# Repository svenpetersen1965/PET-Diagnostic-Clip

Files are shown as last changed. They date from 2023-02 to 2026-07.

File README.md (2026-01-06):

# PET-Diagnostic-Clip
This is a modern remake of the two Commodore Diagnostic Clips

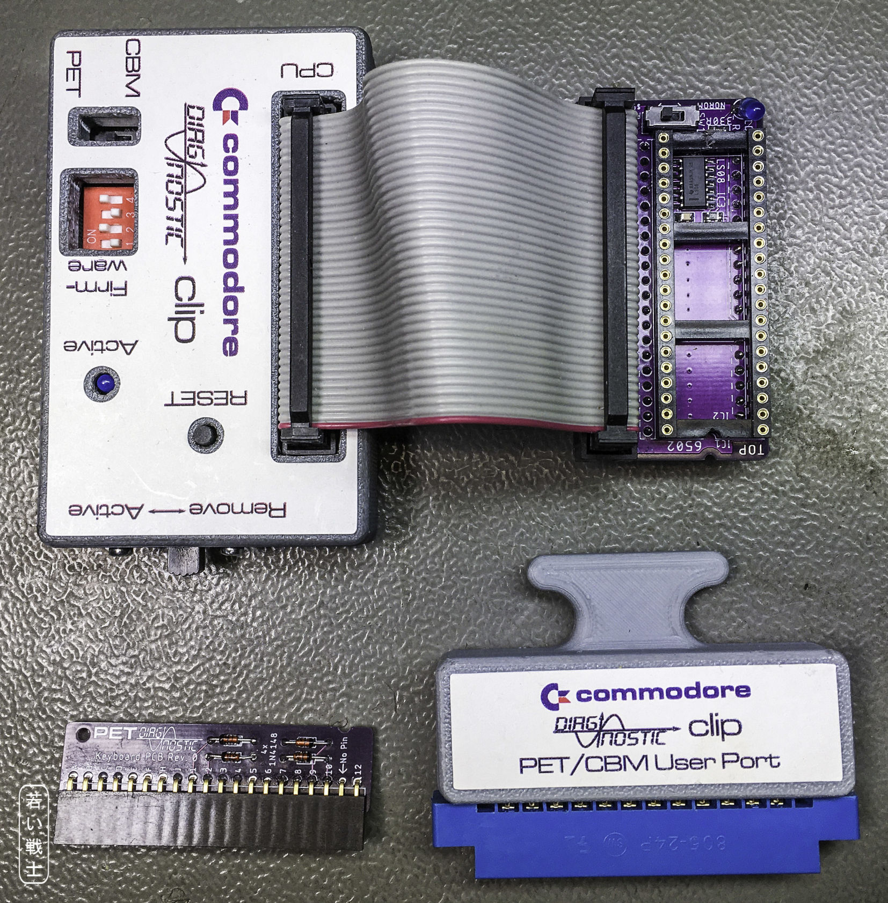
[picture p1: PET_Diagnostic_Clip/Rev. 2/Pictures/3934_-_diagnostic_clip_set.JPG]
Diagnostic Clip (complete)
<br>Complete Diagnostic Clip Set

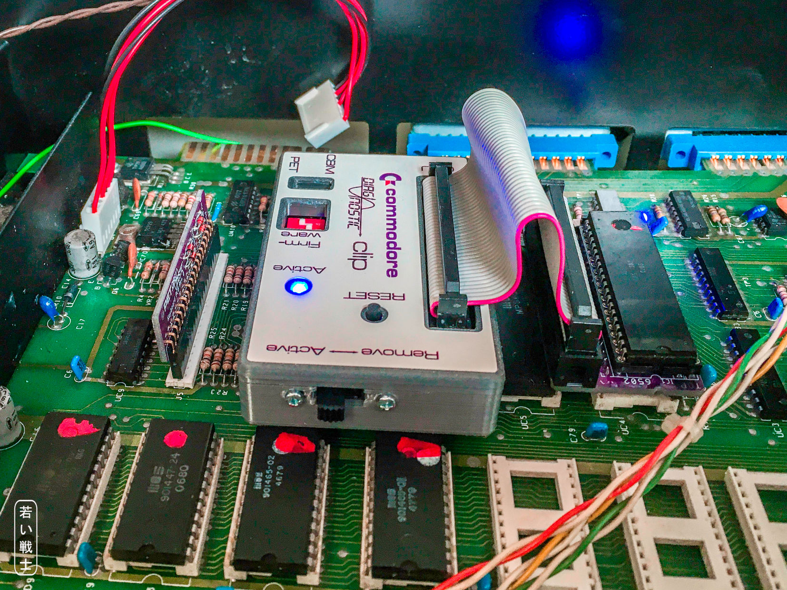
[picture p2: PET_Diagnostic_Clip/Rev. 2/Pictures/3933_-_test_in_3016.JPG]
Diagnostic Clip in CBM3016
<br>Diagnostic Clip installed in a CBM3016 (non CRTC machine)

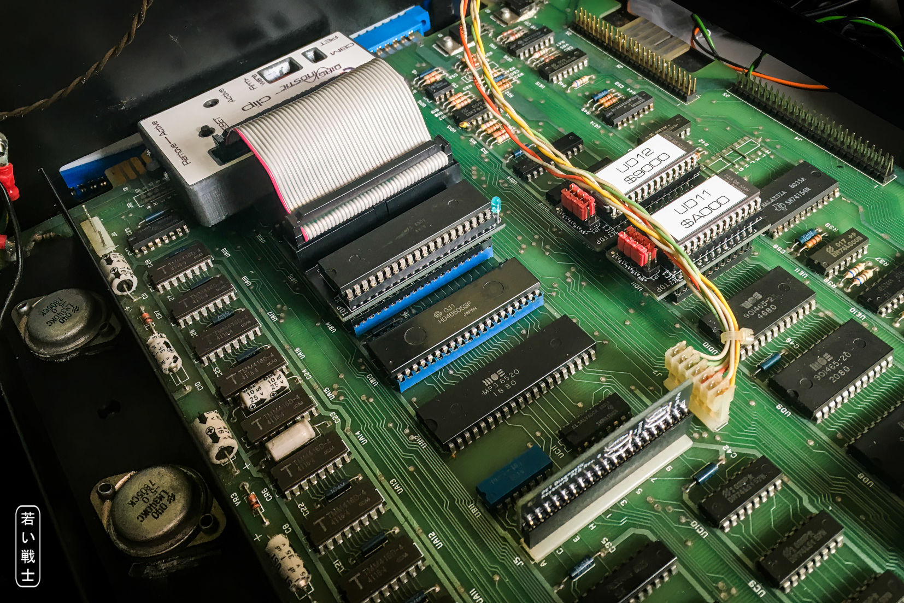
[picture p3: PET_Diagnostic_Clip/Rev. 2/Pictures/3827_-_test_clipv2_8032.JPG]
Diagnostic Clip in CBM8032
<br>Diagnostic Clip installed in a CBM8032 (CRTC machine)

# PET Diagnostic Software (40 column, non CRTC):<br>
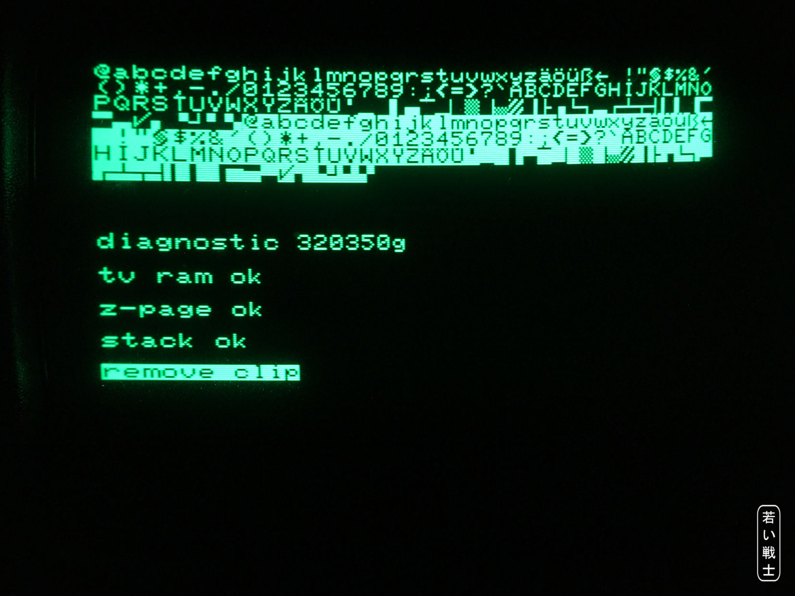
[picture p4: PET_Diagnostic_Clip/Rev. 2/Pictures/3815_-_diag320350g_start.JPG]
40col non CRTC Start
<br>Opening Screen

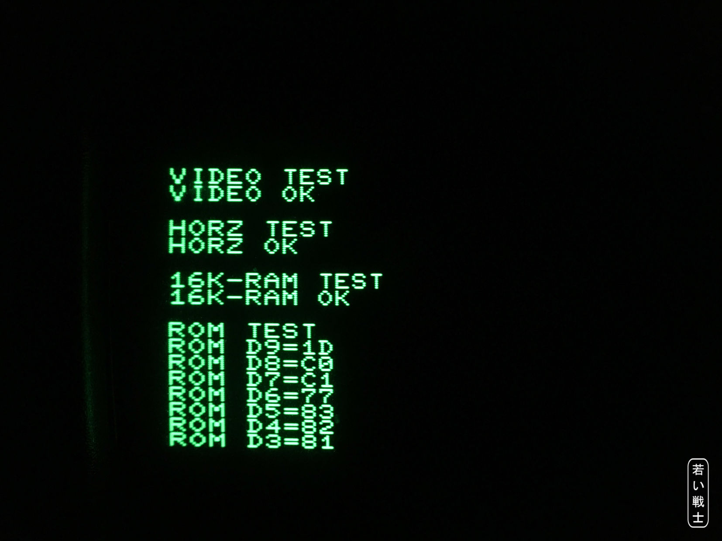
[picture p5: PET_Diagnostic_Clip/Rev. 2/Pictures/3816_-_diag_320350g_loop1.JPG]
<br>Actual tests

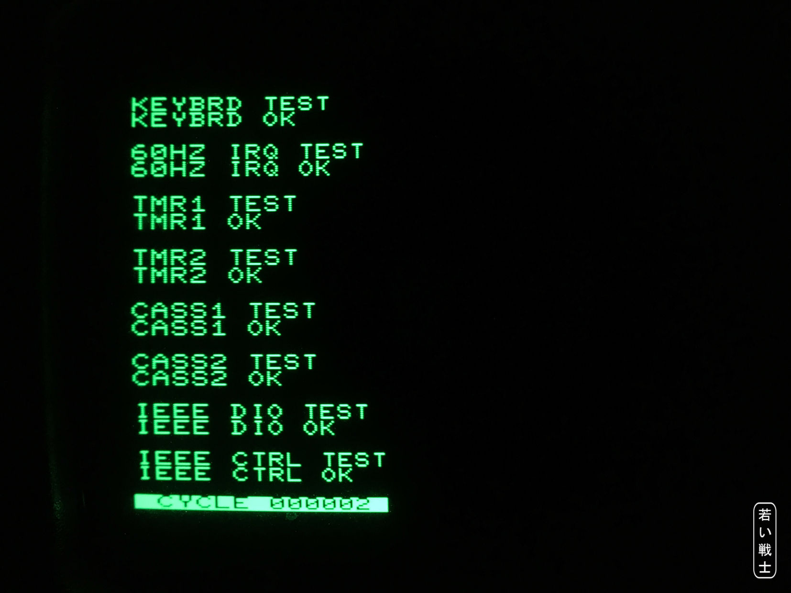
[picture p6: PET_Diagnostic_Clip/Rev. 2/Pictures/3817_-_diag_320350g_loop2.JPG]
<br>Actual tests (continued)

# PET Diagnostic Software (80 column, CRTC):<br>
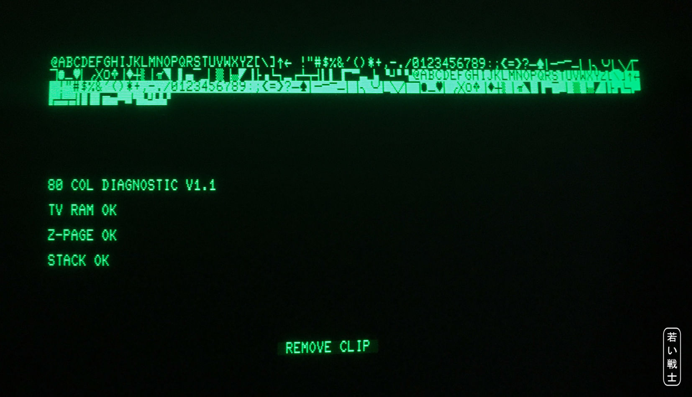
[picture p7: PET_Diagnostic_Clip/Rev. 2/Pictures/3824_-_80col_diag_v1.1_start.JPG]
80col CRTC Start
<br>Opening Screen

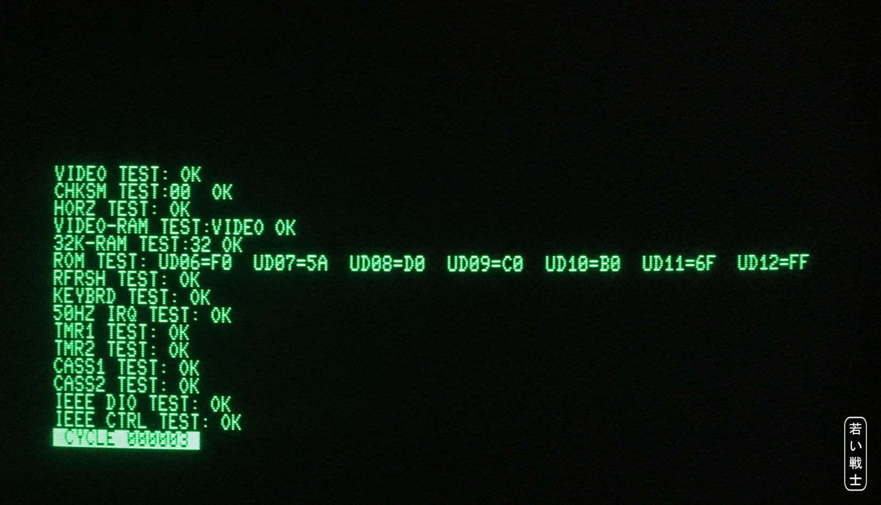
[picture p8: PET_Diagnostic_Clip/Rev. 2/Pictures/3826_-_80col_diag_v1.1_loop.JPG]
80col CRTC Tests
<br>Actual tests

# Binaries for the EPROM
The name of the combined file is "80colCRCTv1.1_40colCRCTv2.0_diag3202350g_diag320350g.bin". It contains:
<table>
  <thead>
    <tr>
      <th>EPROM Offset</th><th>Software</th><th>DIP Switch</th>
    </tr>
  </thead>
  <tbody>
    <tr>
      <td>$0000</td><td>80_col_diagnostic_v1.1.bin</td><td>A[15..12]: 0000 =  ON  ON  ON  ON</td>
    </tr>
    <tr>
      <td>$1000</td><td>40_col_diagnostic_v2.0.bin</td><td>A[15..12]: 0001 =  ON  ON  ON  OFF</td>
    </tr>
    <tr>
      <td>$2000</td><td>901447-30_diagnostic_320350g_$9000.bin</td><td>A[15..12]: 0010 =  ON  ON  OFF ON</td>
    </tr>
    <tr>
      <td>$3000</td><td>901447-30_diagnostic_320350g_$9000.bin</td><td>A[15..12]: 0011 =  ON  ON  OFF OFF</td>
    </tr>
 </tbody>
</table>    
    
The Diagnostic 320350g is double. The reason is, the computer would crash if an empty slot is selected. So all slots, that can be selected with the two low switches of the dip switch are occupied.

In a subdirectory, there are some "PETtester" Softwares. These are not a complete test. The (vice) screen shots are included. It could also be installed on the clip, if desired. 
# CBM8296
This part of the project is not tested yet. <b>The release is preliminary</b>.

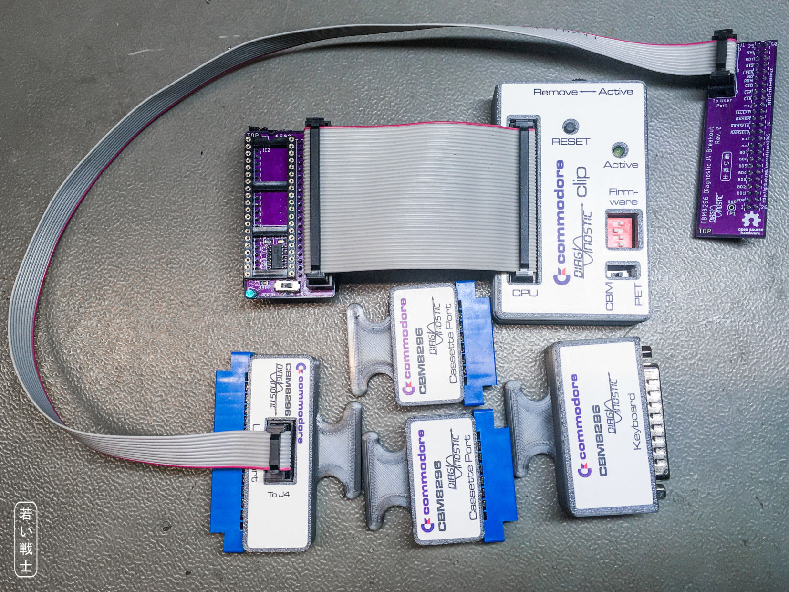
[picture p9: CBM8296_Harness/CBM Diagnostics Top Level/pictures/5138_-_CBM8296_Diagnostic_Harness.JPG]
CBM8296 Diagnostic Harness (complete)
<br>CBM8296 Diagnostic Harness (complete)

The diagnostic software for the CBM8296 is contained in the respective folder. There is also a merged binary file ("80colCRCTv1.1_40colCRCTv2.0_diag3202350g_diag320350g_8296.bin") which contains the 324806-01.bin at offset address $4000 (A[15..12]: 0100 =  ON  OFF  ON ON).

<b>State of testing:</b><br>
14.06.2023:<br>
* all dongles work with the original (Commodore) clip
* the cassette dongle case reqires modification
21.06.2023:<br>
The CBM8296 can actively switch the /NOROM signal (register @$FFF0). It does so to access the RAM underneath the ROMs. As a result, the diagnostic ROM in the clip is getting visible, which interferes with the test of the upper RAM banks.

A solution is switching off the /NOROM signal in the clip by using the 2nd stage of the external switch. The /NOROM trace at J1, pin 9 has to be cut open and connected to the middle pin of the said switch, the right pin ("active" position) has to be connected to the clip's internal /NOROM signal, e.g. at SW4.  

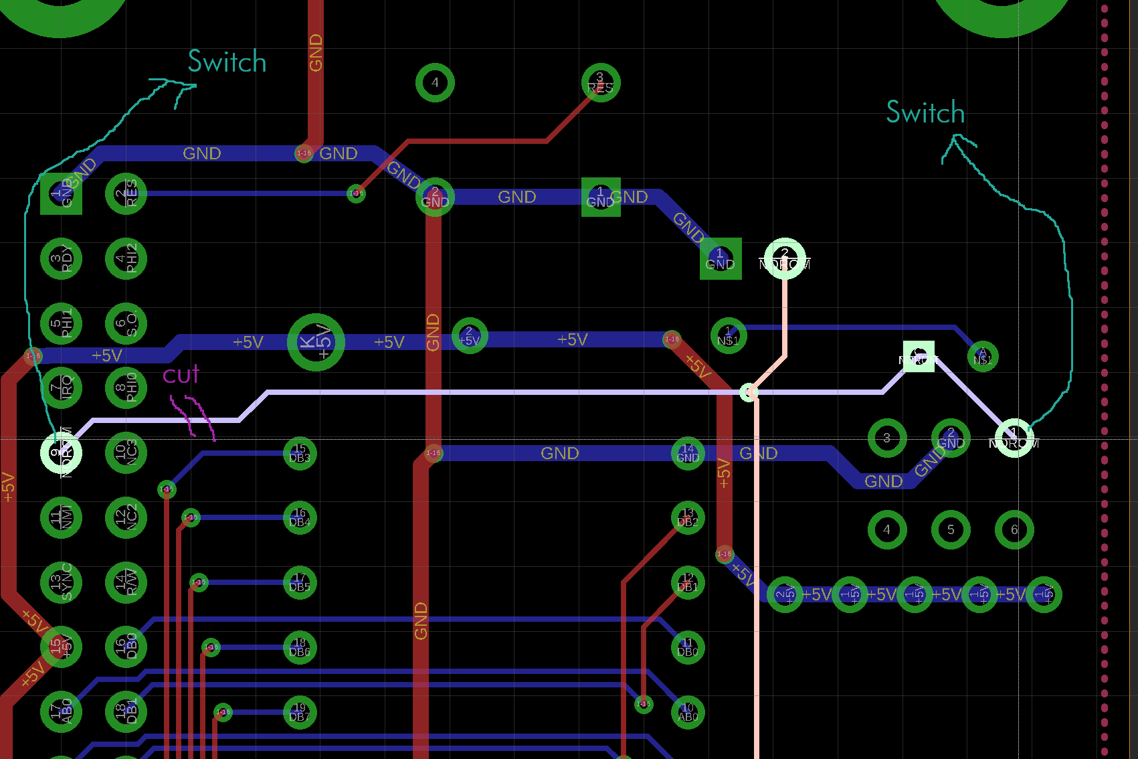
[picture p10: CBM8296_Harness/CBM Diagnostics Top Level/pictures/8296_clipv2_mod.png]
Diagnostic Clip (complete)
<br>/NOROM modification of Clip Rev. 2

The clip Rev. 3 incorporates this modificaltion. Since I do not own a CBM8296, I cannot test the new clip with this computer. 

# Additional Information
I have held a presentation about this topic for Commodore Users Europe on Sept. 23rd, 2023. The pdf of the power point presentation can be found here: <a href="https://github.com/svenpetersen1965/PET-Diagnostic-Clip/commit/a3cc22ed0ae75f65ffd660c29feb877c46cf6521">here</a>

Also check my website for <a href="http://tech.guitarsite.de/petcbm_diag_clip.html">additional information</a>.

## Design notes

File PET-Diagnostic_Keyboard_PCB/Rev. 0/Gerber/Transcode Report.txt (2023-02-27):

   ---- Transcoding 'X:\Projekte\_Eigene\PET_CBM_Projects\PET_Diagostics\PET-Diagnostic_Keyboard_PCB\Rev. 0\Gerber\gerber_PET_Diag_KB.out' ----   Sat Feb 18 21:43:34 2023

D11   --> D100
D12   --> D101
D13   --> D102
-----------------------------------------------------------------

   ---- Transcoding 'X:\Projekte\_Eigene\PET_CBM_Projects\PET_Diagostics\PET-Diagnostic_Keyboard_PCB\Rev. 0\Gerber\gerber_PET_Diag_KB.plc' ----   Sat Feb 18 21:43:34 2023

D11   --> D103
D12   --> D104
D13   --> D105
D14   --> D106
D15   --> D107
D16   --> D108
D17   --> D109
D18   --> D110
D19   --> D111
D20   --> D112
-----------------------------------------------------------------

   ---- Transcoding 'X:\Projekte\_Eigene\PET_CBM_Projects\PET_Diagostics\PET-Diagnostic_Keyboard_PCB\Rev. 0\Gerber\gerber_PET_Diag_KB.pls' ----   Sat Feb 18 21:43:34 2023

D11   --> D183
D12   --> D184
D13   --> D185
D14   --> D186
D15   --> D187
D16   --> D188
D17   --> D189
D18   --> D190
D19   --> D191
D20   --> D192
D21   --> D193
D22   --> D194
D23   --> D195
D24   --> D196
D25   --> D197
D26   --> D198
D27   --> D199
D28   --> D200
D29   --> D201
D30   --> D202
D31   --> D203
D32   --> D204
D33   --> D205
D34   --> D206
D35   --> D207
D36   --> D208
D37   --> D209
D38   --> D210
D39   --> D211
D40   --> D212
D41   --> D213
D42   --> D214
D43   --> D215
D44   --> D216
D45   --> D217
D46   --> D218
D47   --> D219
D48   --> D220
D49   --> D221
D50   --> D222
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
-----------------------------------------------------------------

   ---- Transcoding 'X:\Projekte\_Eigene\PET_CBM_Projects\PET_Diagostics\PET-Diagnostic_Keyboard_PCB\Rev. 0\Gerber\gerber_PET_Diag_KB.stc' ----   Sat Feb 18 21:43:34 2023

D11   --> D274
D12   --> D275
D13   --> D276
D14   --> D277
D16   --> D278
D17   --> D279
D18   --> D280
-----------------------------------------------------------------

   ---- Transcoding 'X:\Projekte\_Eigene\PET_CBM_Projects\PET_Diagostics\PET-Diagnostic_Keyboard_PCB\Rev. 0\Gerber\gerber_PET_Diag_KB.sts' ----   Sat Feb 18 21:43:34 2023

D11   --> D281
D12   --> D282
D13   --> D283
D14   --> D284
D16   --> D285
D17   --> D286
D18   --> D287
-----------------------------------------------------------------

   ---- Transcoding 'X:\Projekte\_Eigene\PET_CBM_Projects\PET_Diagostics\PET-Diagnostic_Keyboard_PCB\Rev. 0\Gerber\gerber_PET_Diag_KB.top' ----   Sat Feb 18 21:43:34 2023

D11   --> D288
D12   --> D289
D13   --> D290
D14   --> D291
D15   --> D292
D16   --> D293
D17   --> D294
D18   --> D295
D19   --> D296
-----------------------------------------------------------------

   ---- Transcoding 'X:\Projekte\_Eigene\PET_CBM_Projects\PET_Diagostics\PET-Diagnostic_Keyboard_PCB\Rev. 0\Gerber\excellon_PET_Diag_KB.ndk' ----   Sat Feb 18 21:43:44 2023

T1   --> T4
-----------------------------------------------------------------

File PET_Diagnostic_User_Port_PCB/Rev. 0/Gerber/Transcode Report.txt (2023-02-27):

   ---- Transcoding 'X:\Projekte\_Eigene\PET_CBM_Projects\PET_Diagostics\PET_Diagnostic_User_Port_PCB\Rev. 0\Gerber\gerber_PET_Diag_UP.out' ----   Wed Jan 04 18:26:30 2023

D12   --> D100
D13   --> D101
-----------------------------------------------------------------

   ---- Transcoding 'X:\Projekte\_Eigene\PET_CBM_Projects\PET_Diagostics\PET_Diagnostic_User_Port_PCB\Rev. 0\Gerber\gerber_PET_Diag_UP.plc' ----   Wed Jan 04 18:26:30 2023

D11   --> D252
D12   --> D253
D13   --> D254
D14   --> D255
D15   --> D256
D16   --> D257
D17   --> D258
D18   --> D259
D19   --> D260
D20   --> D261
D100  --> D262
D101  --> D263
-----------------------------------------------------------------

   ---- Transcoding 'X:\Projekte\_Eigene\PET_CBM_Projects\PET_Diagostics\PET_Diagnostic_User_Port_PCB\Rev. 0\Gerber\gerber_PET_Diag_UP.stc' ----   Wed Jan 04 18:26:30 2023

D12   --> D264
D13   --> D265
D15   --> D266
D16   --> D267
-----------------------------------------------------------------

   ---- Transcoding 'X:\Projekte\_Eigene\PET_CBM_Projects\PET_Diagostics\PET_Diagnostic_User_Port_PCB\Rev. 0\Gerber\gerber_PET_Diag_UP.sts' ----   Wed Jan 04 18:26:30 2023

D12   --> D268
D13   --> D269
D15   --> D270
D16   --> D271
-----------------------------------------------------------------

   ---- Transcoding 'X:\Projekte\_Eigene\PET_CBM_Projects\PET_Diagostics\PET_Diagnostic_User_Port_PCB\Rev. 0\Gerber\gerber_PET_Diag_UP.top' ----   Wed Jan 04 18:26:30 2023

D18   --> D272
D19   --> D273
-----------------------------------------------------------------

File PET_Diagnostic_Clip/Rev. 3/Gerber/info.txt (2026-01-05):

      
       Board: PET_Diag_Clip
       Rev.:  3
  
       Files:
       ======
  
       All Gerber files are generated in extended gerber format (RS274X)
       *.TOP        : Film top copper
       *.BOT        :  -"- bottom copper
       *.STC        :  -"- top soldermask 
       *.STS        :  -"- bottom soldermask
       *.PLC        :  -"- silk screen top
       *.PLS        :  -"- silk screen bottom
       *.DK         : Drills plated Through (Excellon)
       *.NDK        : Drills not plated Through (Excellon)
       *.OUT        : Board outline

       Board Size:
       ===========
       Length     :   77.0 mm
       Width      :   47.0 mm
       Thickness  :   1.6 mm
       Material   :   FR 4
       Copper     :   35 um
       Surface    :   HASL
       
       Remarks:
       ========
       minimum drill: 0.35mm
       minimum width: 8 mil
       minimum distance: 6 mil

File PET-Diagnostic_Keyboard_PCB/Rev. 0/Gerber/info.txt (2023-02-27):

      
       Board: PET_Diag_KB
       Rev:   0
  
       Files:
       ======
  
       All Gerber files are generated in extended gerber format (RS274X)
       *.TOP        : Film top copper
       *.BOT        :  -"- bottom copper
       *.STC        :  -"- top soldermask 
       *.STS        :  -"- bottom soldermask
       *.PLC        :  -"- silk screen top
       *.PLS        :  -"- silk screen bottom
       *.DK         : Drills plated Through (Excellon)
       *.NDK        : Drills not plated Through (Excellon)
       *.OUT        : Board outline

       Board Size:
       ===========
       Length     :   53.0 mm
       Width      :   14.0 mm
       Thickness  :   1.6 mm
       Material   :   FR 4
       Copper     :   35 um
       Surface    :   HASL
       
       Remarks:
       ========
       Width >= 8mil
       Distance >= 6mil
       Drill >= 0.35mm

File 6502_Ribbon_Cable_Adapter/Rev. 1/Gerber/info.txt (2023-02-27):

      
       Board: 6502_cable_ada
       Rev.:  1
  
       Files:
       ======
  
       All Gerber files are generated in extended gerber format (RS274X)
       *.TOP        : Film top copper
       *.BOT        :  -"- bottom copper
       *.STC        :  -"- top soldermask 
       *.STS        :  -"- bottom soldermask
       *.PLC        :  -"- silk screen top
       *.PLS        :  -"- silk screen bottom
       *.CRC        :  -"- cream top
       *.DK         : Drills plated Through (Excellon)
       *.NDK        : Drills not plated Through (Excellon)
       *.OUT        : Board outline

       Board Size:
       ===========
       Length     :   61.0 mm
       Width      :   32.0 mm
       Thickness  :   1.6 mm
       Material   :   FR 4
       Copper     :   35 um
       Surface    :   HASL
       
       Remarks:
       ========
       minimum drill: 0.35mm
       minimum width: 8 mil
       minimum distance: 6 mil

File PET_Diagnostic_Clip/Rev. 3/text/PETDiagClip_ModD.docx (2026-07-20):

Commodore PET/CBM80xx/40xx Diagnostic Clip Rev. 3

Module Description

# 1. Introduction

The diagnostic clip is a diagnostic tool, which is originally issued by Commodore. It contains the diagnostic software, which has to fit to the board type, that is tested. For testing, it is connected to the 6502, switches off the ROMs on the mainboard and/or redirects the Kernal accesses to its built in EPROM.

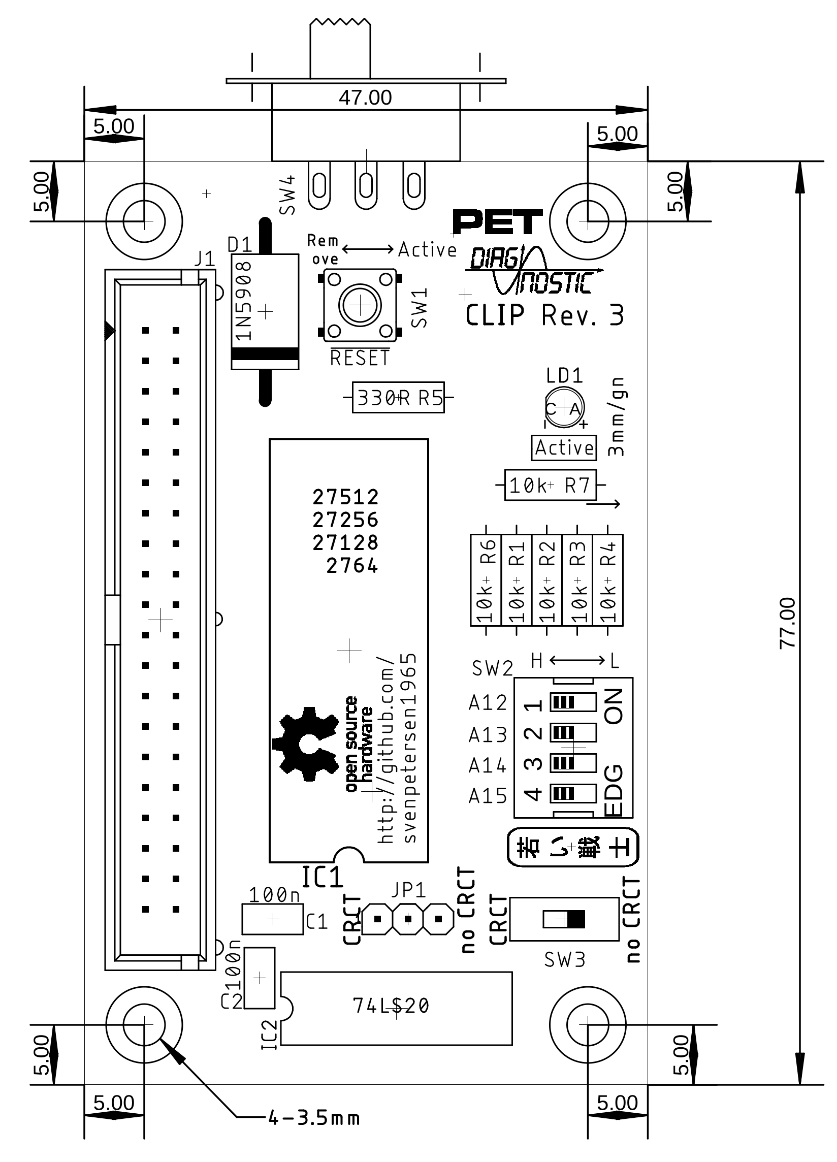
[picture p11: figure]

Figure 1: Dimension of the PCB

The original hardware consists of:

- DIP40 test clip (3M is still producing this kind of clip – They are available from Mouser and Digikey: https://www.digikey.com/en/products/detail/3m/923743-40/12075, which is $94.07 in February 2023)
- the box with the EPROM/Test software)
- the keyboard feedback dongle
- user port feedback dongle

There is an extra box for each version of the software.

The goal of this development is to eliminate the need for an expensive DIP40 test clip and to merge the different box designs to one PCB. Further, shorting A13 and A14 to GND should be prevented.

The result is a 4 PCB solution:

- the clip box with a ribbon cable
- a ribbon cable adapter for the 6502
- a keyboard feed back
- a user port feed back

The EPROM in the clip box is fully connected to the 6502 µprocessor address and data bus. When connected (and configured properly), the test software is run after powering up the machine. The two main types of mainboards require different methods of making the test software appear in the system.

- CRTC machines, like the 8032, have a signal, which can switch off all ROMs on the mainboard (except the character set) and the test software resides at $Fxxx instead of the Kernal. It comes with its own RESET vector @ $FFFC/D (it points to $F000, the start of the test software)
- Non CRTC machines, like the PET2001 or CBM30xx: the Kernal access is redirected to the option ROM address space $9xxx. This happens by (brutally) shorting the address signals A13 and A14 to GND – $F/1111BIN becomes a $9/1001BIN. The test software starts at $9800, the redirected reset vector is now at $9FFC/D and it points to $9800

Note: CRTC means “Cathode Ray Tube Controller. The first PETs had a video circuit, solely consisting of TTL ICs and the Character ROM. This includes the first “dynamic PETs”, like the CBM 30xx. The later machines had a controller chip (6545) as the heart of the video circuit. It can be configured for 40 column and 80 column machines and is a bit more flexible. The CBM 80xx and most CBM 40xx are CRTC machines.

For testing the CBM8296, it is required to switch the /NOROM signal off while the Active « Remove switch is in the Remove state, since it is also controlled by software. This is realize in Rev. 3.

# 2. Test procedure

## 2.1. Brief discription

The diagnostic hardware (clip/ribbon cable adapter, clip box, keyboard and user port dongles have to be connected before power up.

After power up, the diagnostic software is started. It consists or the first basic tests, which make sure, that the basic system is working:

- Printing the character set on the screen
- Testing the “TV RAM” (screen memory)
- Testing the Zero Page
- Testing the stack
- Copying the actual test software into the RAM, starting at $0200. Jumping to that software
- Waiting for the clip to be removed

NOTE: A switch installed on JP5 allows to switch off , which is logically removing the clip EPROM from the system. As a non-CRTC machine the CBM3016 was tested.

The copied test software first waits for the clip to be removed by checking the (redirected) reset vector. If it does not point to $F000 or $9800 for a couple of seconds, it is assumed, that the clip is removed. Then testing is proceeded:

- Video Test
- Checksum Test (CRTC machines)
- Horizontal (video) Test
- Video RAM Test (CRTC machines)
- 32k RAM test
- ROM Test (shows checksum only)
- Refresh Test (dynamic RAM refresh)
- Keyboard Test
- 60Hz (non CRTC) or 50Hz (CRTC) IRQ (interrupt) test
- Timer 1 Test
- Timer 2 Test
- Cassette 1 Test
- Cassette 2 Test
- IEEE DIO Test
- IEEE Ctrl Test

This part of the test is cycling until the Reset switch is pressed or the computer is power down. The tests are described in chapter 6.2.2

## 2.2. Notes

The user port is used to monitor the video signals, SRQ and EOI from the IEEE Bus, the Tape write and read signals and the “Diagsens” and “Graphic” signal.

I would not consider this as a proper user port test.

The IEEE signals are fed back internally, there is no external feedback, so the driver chips are not tested.

The tape port TPWRITE signal on the user port us fed back to both TPREAD1 and TPREAD2. CASS SWITCH #1 and #2 are not tested, neither is CASS MOTOR #1 and #2.

The testing will stop on the first failed test.

# 3. Diagnostic Software

## 3.1. 80 col CRTC

The file name in the “Diagnostic Software” folder is “80_col_diagnostic_v1.1.bin”. It is suitable for 80 col 80xx and 40xx machines (with the 12” monitor).

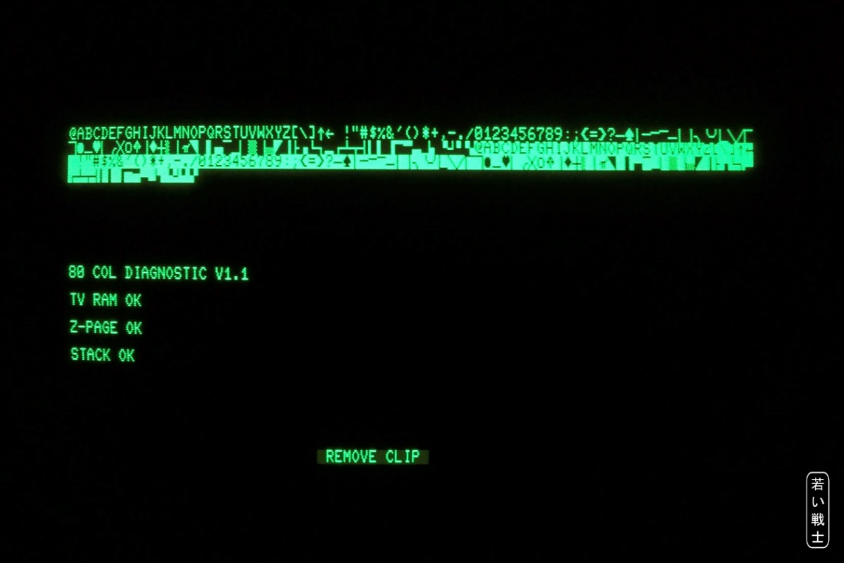
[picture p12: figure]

Figure 1: 80_col_diagnostic_v1.1.bin - first page

After removing the clip, respectively switching it to “remove”, the test continues on the 2nd page.

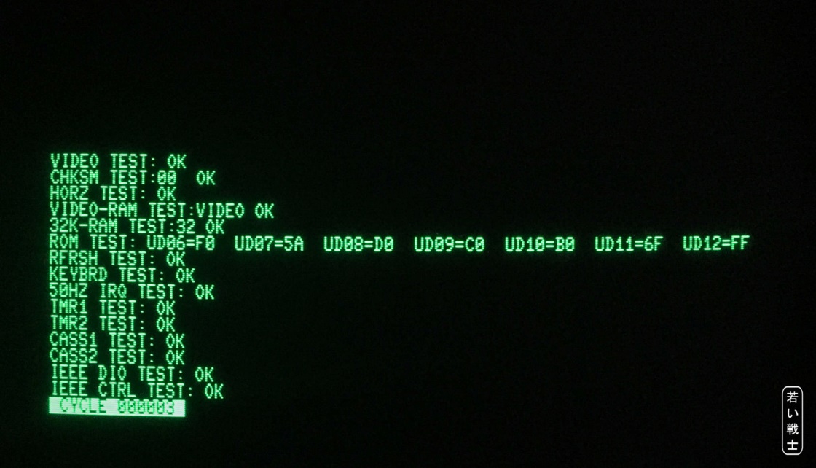
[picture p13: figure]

Figure 2: 80_col_diagnostic_v1.1.bin - second page

## 3.2. 40 col CRTC

Since no such a computer is available, just the opening page can be shown on a 40 col. screen. A further test on a non CRTC machine (CBM3016) fails. The test itself passes on the CBM8032, but the output screen is not properly aligned.

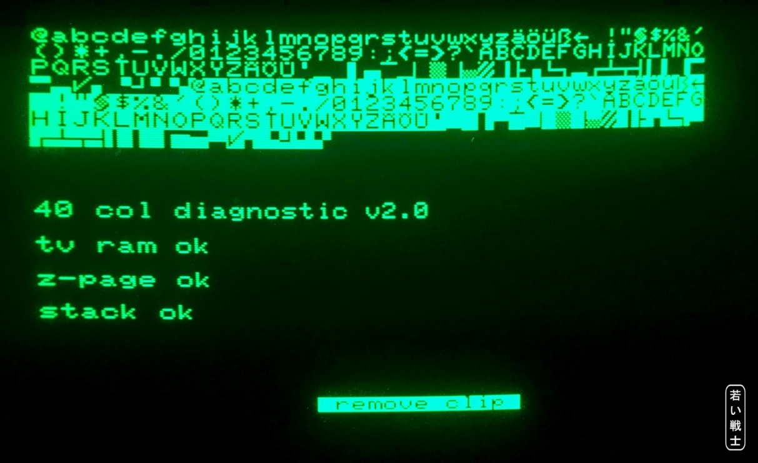
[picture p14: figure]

Figure 3: 40_col_diagnostic_v2.0.bin - first page

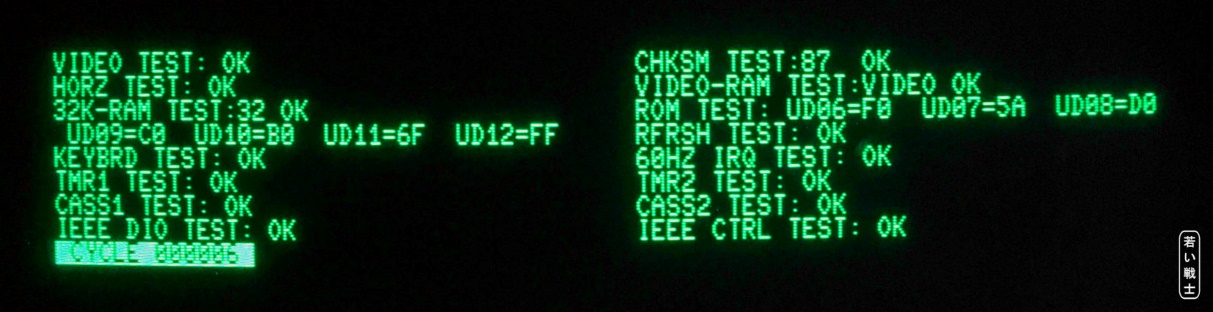
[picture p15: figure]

Figure 4: 40_col_diagnostic_v2.0.bin - second page (on an 80 col machine)

## 3.3. 40 col non-CRTC

This test should work with all 40 column non-CRTC machines. The 2nd page is scrolling, so an upper and lower half of the looping test is shown.

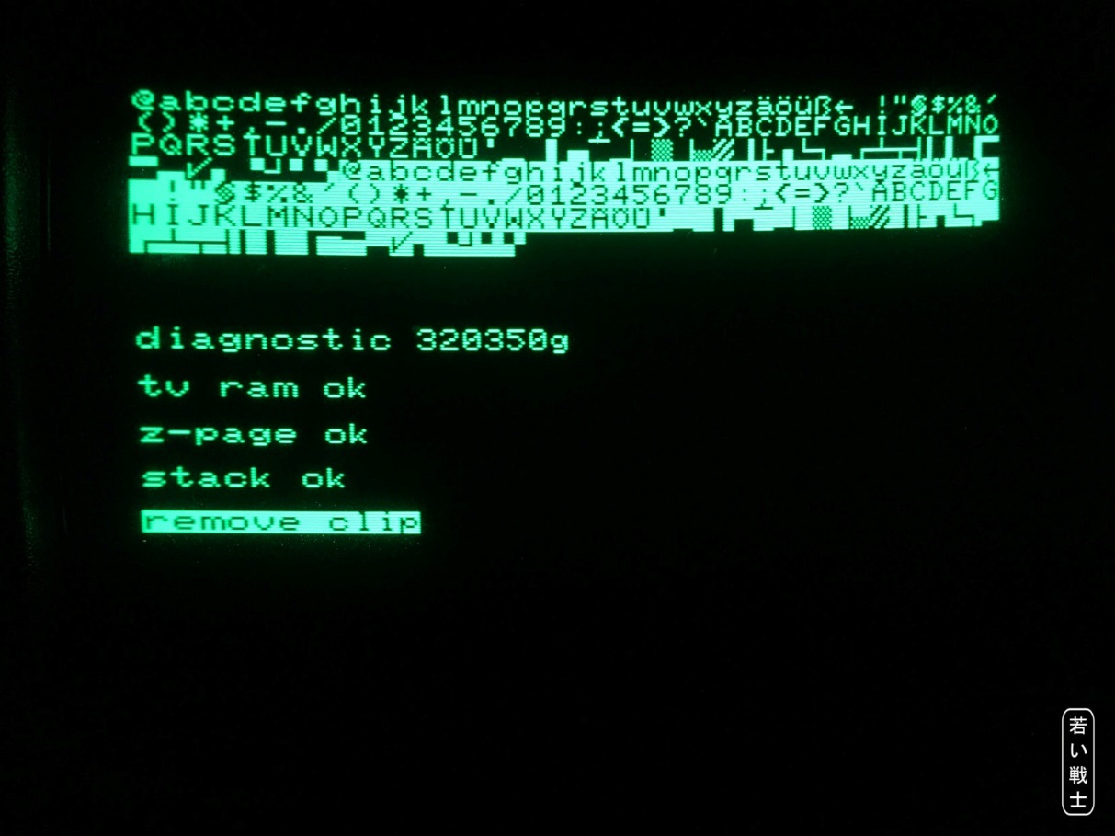
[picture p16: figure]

Figure 5: 901447-30_diagnostic_320350g_$9000.bin - first page

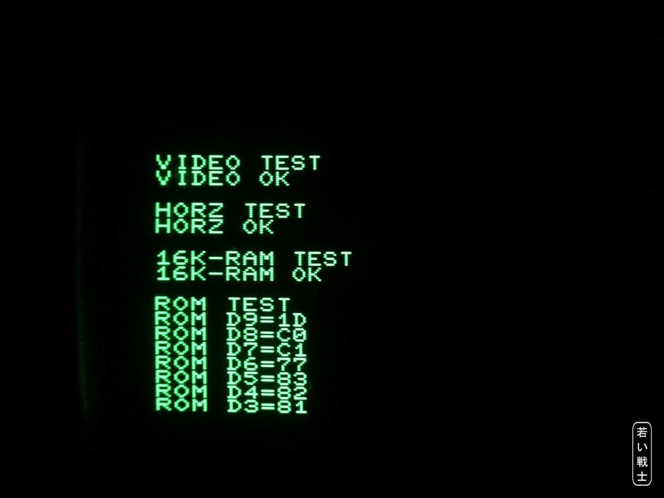
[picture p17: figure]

Figure 6: 901447-30_diagnostic_320350g_$9000.bin - 2nd page (upper half)

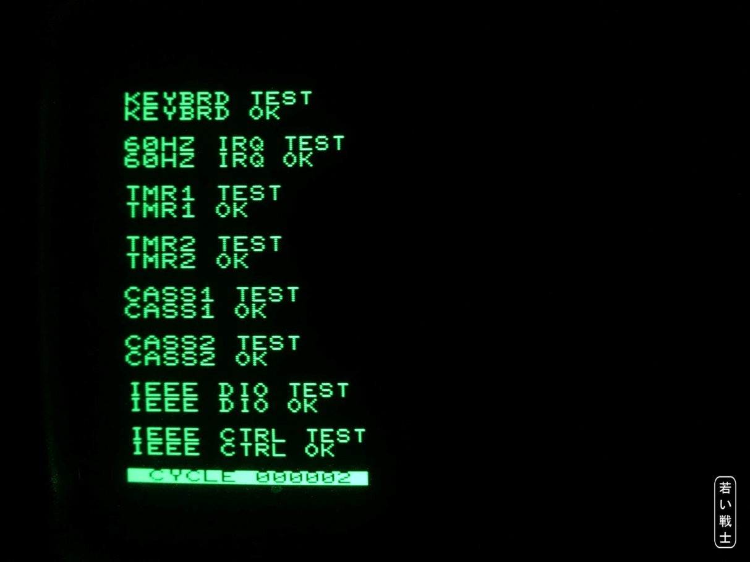
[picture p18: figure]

Figure 7: 901447-30_diagnostic_320350g_$9000.bin - 2nd page (lower half)

# 4. Complete Diagnostic Clip Set

In Figure 8 all required PCBs are shown, including the short 40 pin ribbon cable.

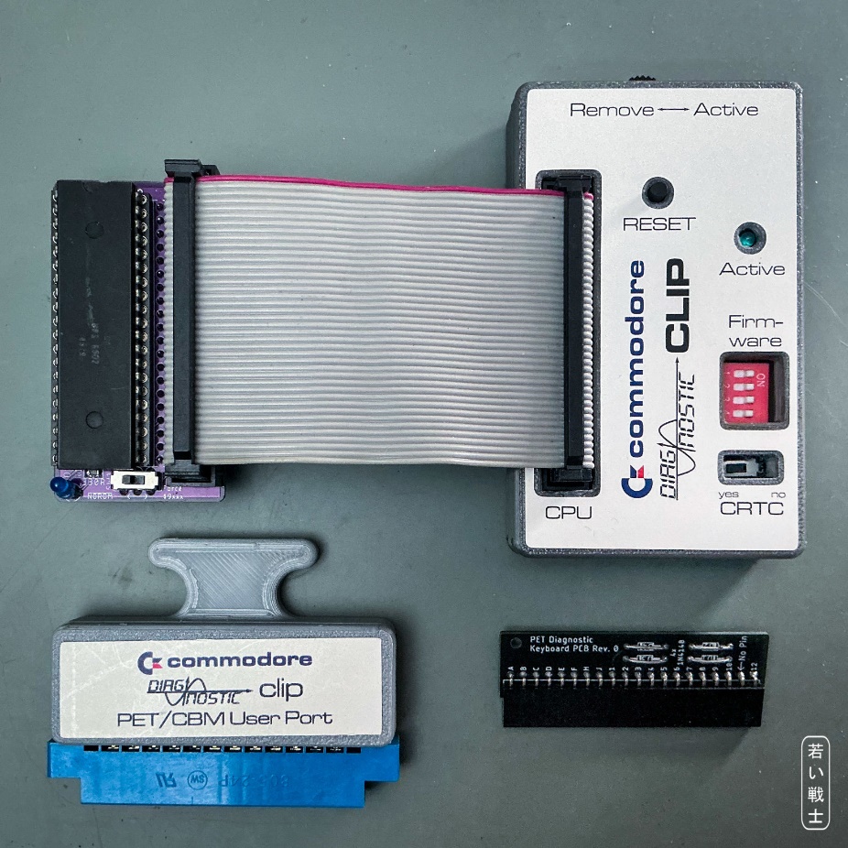
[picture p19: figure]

Figure 8: Diagnostic set, 6502 inserted in Ribbon cable adapter

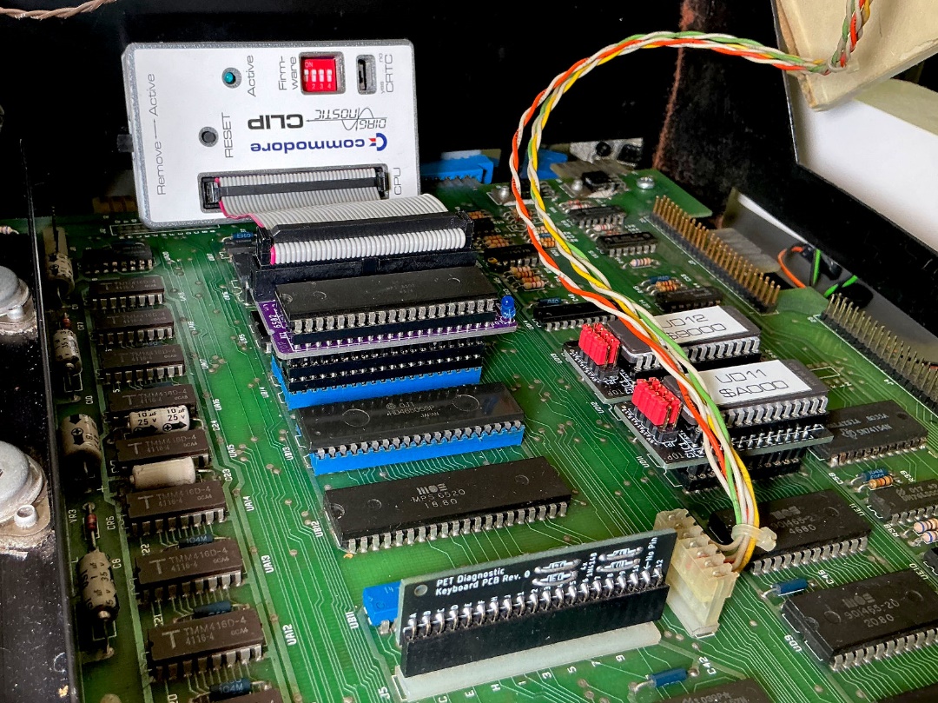
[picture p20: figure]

Figure 9: Diagnostic clip connected to the 6502 ribbon cable adapter (in the CBM8032)

# 5. Connectors and Jumpers

## 5.1. J1 – Connector to test clip/6502 Ribbon Cable Adapter

A 2x20 box connector, 2.54mm pitch

Signal | Pin | Pin | Signal
GND (6502, Pin 1) | 1 | 2
RDY | 3 | 4 | PHI2
PHI | 5 | 6 | S.O.
| 7 | 8 | PHI0
| 9 | 10 | n.c. (6502, Pin 36)
| 11 | 12 | n.c. (6502, Pin 35)
SYNC | 13 | 14 | R/
5V | 15 | 16 | DB0
AB0 | 17 | 18 | DB1
AB1 | 19 | 20 | DB2
AB2 | 21 | 22 | DB3
AB3 | 23 | 24 | DB4
AB4 | 25 | 26 | DB5
AB5 | 27 | 28 | DB6
AB6 | 29 | 30 | DB7
AB7 | 31 | 32 | AB15
AB8 | 33 | 34 | AB14
AB9 | 35 | 36 | AB13
AB10 | 37 | 38 | AB12
AB11 | 39 | 40 | GND (6502, Pin 21)

## 5.2. Jumpers & Switches

### 5.2.1. SW1 Reset Switch

The Reset switch serves for resetting the tested computer.

### 5.2.2. JP6/SW3 – AB13 & AB14

This selects the CRTC/non CRTC mode

Signal | Pin | Pin | Signal
n.c. | 1 | 2 | AS14
AB13 | 3 | 4 | AB14
GND | 5 | 6 | GND

CRTC machines, like the 80xx or most 40xx: Jumper 1 – 3 & 2 – 4.

Non-CRTC machines, like the PET20xx or CBM 30xx: Jumper 3 – 5 & 4 – 6.

Internally the mini slide Switch SW3 can be installed instead of JP6, which is the recommended solution.

### 5.2.3. SW2 – The DIP Switch

The DIP-Switch serves for selecting the test software (one of 16 possible) from the EPROM (27C512) that can be run on the clip. The size of the test software is 4kByte, while the size of the EPROM is 64kByte. If it is desired to have a smaller EPROM, the highest (not required) address bits have to be HIGH and the DIP-switch can be smaller.

EPROM | SW | Address Bits | DIP-Switch
27C256 | 8x4k | A15 open/HIGH | position 1-3
27C128 | 4x4k | A15&A14 open/HIGH | position 1-2
27C64 | 2x4k | A15&A14&A13 open/HIGH | position 1

The OFF position of a switch means HIGH, the ON Position means LOW.

4 | 3 | 2 | 1 | A15..12 | 4k Slot | EPROM Offset
on | on | on | on | 0000 | 0 | $0000
on | on | on | off | 0001 | 1 | $1000
on | on | off | on | 0010 | 2 | $2000
on | on | off | off | 0011 | 3 | $3000
on | off | on | on | 0100 | 4 | $4000
on | off | on | off | 0101 | 5 | $5000
on | off | off | on | 0110 | 6 | $6000
on | off | off | off | 0111 | 7 | $7000
off | on | on | on | 1000 | 8 | $8000
off | on | on | off | 1001 | 9 | $9000
off | on | off | on | 1010 | 10 | $A000
off | on | off | off | 1011 | 11 | $B000
off | off | on | on | 1100 | 12 | $C000
off | off | on | off | 1101 | 13 | $D000
off | off | off | on | 1110 | 14 | $E000
off | off | off | off | 1111 | 15 | $F000

### 5.2.4. SW4 – Active/Remove Switch

This switch is initially set to “Active”, after the computer is started (by power on or reset), the diagnostics software runs the first page/part of the diagnostic test routine (Figure 1 and Figure 3). In this state, the internal signal is pulled LOW and is connected to the (external) signal that is connected to the CPU socket pin 5 and the rest of the computer.

To continue the diagnostic test, the switch SW4 has to be set to the “Remove” position. In this position, the signal is HIGH (via pull-up R7) and it is also disconnected from the external signal.

The separation of the internal and the external signal has no effect with the PETs or CBM40xx and 80xx, but obviously the CBM8296 can modify the signal via a register to access the RAM, which is in the same address space of the ROMs. Since there is no real clip in this project, which is physically disconnected from the computer, the signal has to be separated with SW4 to prevent the clip from interfering with the test.

# 6. Resources

## 6.1. Websites

The information for creating this project, like the schematics of the original diagnostic clips and some test software was retrieved from André Fachat’s website:

- http://www.6502.org/users/andre/petindex/diag/index.html

Further test software and the connections of the keyboard and user port feedback was retrieved from Bo Zimmerman’s website:

- http://www.zimmers.net/anonftp/pub/cbm/firmware/computers/pet/other/index.html
- http://www.zimmers.net/anonftp/pub/cbm/schematics/computers/pet/diagnostics.txt

## 6.2. Commodore Training: 40xx/80xx Service Manual

Some further descriptions can be found in the (German) "Commodore Training_40xx_80xx_Service Manual (https://www.retro-commodore.eu/2017/02/26/commodore-service-training-material-for-cbm-40xx80xx/)" on Carsten's great retro-commodore.eu website .

Page 33ff:

### 6.2.1. DIAGNOSTIC BOX DESCRIPTION

"DIAGNOSTIC-BOX BESCHREIBUNG

Die Diagnostic-Box ist ein Testgerät, mit dem die wichtigsten Komponenten auf der Logic-Platine der Zentraleinheiten getestet und ein hoher Prozentsatz der Fehler gefunden werden kann.

Die Tastatur selbst und das Video-Board wird nicht überprüft. Für jede Zentraleinheit gibt es eine spezielle Diagnostic-Box.

Anschluß und Starten des Testprogramms:

Zur Diagnostic-Box gehören zwei Diagnostic-Stecker, einer für den User-Port und einer für die Tastatur. An der Box befindet sich ein 40-poliges Flachbandkabel mit einem IC-Clip.

Dieser Clip wird auf den Prozessor gesteckt und die beiden Diagnostic-Stecker kommen an die entsprechenden Positionen

Wenn die rote LED leuchtet, kann das Diagnose-Programm durch drücken der roten Taste (Reset) gestartet werden.

Auf dem Bildschirm wird nun angezeigt welcher Test gerade läuft, ob er fehlerfrei durchläuft, oder was für Fehler erkannt wurden. Wird ein Fehler erkannt, stoppt das Testprogramm. Treten keine Fehler auf, werden die Tests laufend wiederholt."

Translated to English:

"DIAGNOSTIC BOX DESCRIPTION

The Diagnostic-Box is a test device with which the most important components on the logic board of the central units are tested and a high percentage of errors can be found.

The keyboard itself and the video board are not checked. There is a special diagnostic box for each computer.

Connection and start of the test program:

The Diagnostic Box includes two diagnostic plugs, one for the User port and one for the keyboard. There is a 40-pin ribbon cable with an IC clip attached to the box.

This clip is put on the processor and the two diagnostic plugs are connected to the appropriate positions/connectors.

When the red LED lights up, the diagnostic program can be started by pressing the red button (Reset). The screen now shows which test is currently running and whether it is passed or failed, or what kind of errors were detected. If an error is detected, the test program stops. if there are no fails, the tests are repeated continuously."

[...]

### 6.2.2. Test description

"Testbeschreibung

Nach Betätigung der Reset-Taste wird der CRT-Controller initialisiert und der CBM-Zeichensatz in den oberen Teil des Bildschirms geschrieben womit festgestellt wird ob es überhaupt möglich ist Daten auf den Bildschirm zu schreiben.

Nun wird Zero-Page und Stack getestet. Treten hier Fehler auf wird entweder ein RAM als defekt angezeigt oder eine Adressleitung.

Eine genaue Erkennung des Fehlers ist aber in manchen Fällen nicht möglich, sodaß zum Teil unrichtige Fehlermeldungen ausgegeben werden. Um den Fehler zu lokalisieren kann man die CAS-Leitungen an den RAMs vertauschen und den Test neu starten. Wird wieder eine Fehlermeldung ausgegeben, so liegt der Fehler wahrscheinlich nicht an den RAM', sondern an der Ansteuerung (Adressleitungen, Refresh, RAS, CAS, RAM R/W, MUX A).

Ist Zero-Page und Stack in Ordnung wird ein Testprogramm in den RAM-Bereich geschrieben und die Aufforderung REMOVE CLIP erscheint auf dem Bildschirm.

Wird nun die Diagnostic-Box vom Prozessor entfernt, werden von dem in der Zero-Page befindlichen Testprogramm die weiteren Teile des Systems getestet. Die ausgegebenen Fehlermeldungen sind im Allgemeinen zuverlässig."

English:

"Test description

After pressing the reset button, the CRT controller is initialized and the CBM character set is displayed on the upper part of the screen, which determines whether it is even possible to write data on the screen.

Now the zero-page and stack are tested. If errors occur here, either a RAM is displayed as defective or an address line

In some cases, however, an exact detection of the error is not possible, so that in some cases incorrect error messages are output. To localize the error, you can swap the CAS lines on the RAM's and restart the test. If an error message is output again, the error is probably not due to the RAM, but to the control (address lines, refresh, RAS, CAS, RAM R/W, MUX A).

If the zero page and stack are OK, a test program is written to the RAM area and the REMOVE CLIP request appears the screen.

If the diagnostic box is now removed from the processor, the other parts of the system are tested by the test program in the zero page. The error messages issued are generally reliable."

CHKSM TEST: | Um zu überprüfen, ob das Testprogramm richtig in die Zero-Page geladen wurde, wird eine Prüfsumme gebildet die 00 ergeben muß.
VIDEO RAM TEST: | Es werden in jede Bildschirmadresse Daten geschrieben wieder gelesen und verglichen
32K RAM TEST: | Es wird der gesamte RAM-Speicher außer Zero-Page und Stack getestet
ROM TEST: | Es werden Prüfsummen von jedem ROM gebildet (siehe Liste der Prüfsummen)
RFRSH TEST: | Es werden Daten in die RAMs geschrieben, eine Zeit lang gewartet und die Daten wieder ausgelesen. So wird überprüft, ob der Refresh in Ordnung ist.
KEYBOARD TEST: | Es wird die Funktion des Decoders und des PIA überprüft
50 HZ IRQ TEST: | Es wird getestet, ob von dem Signal Vert Drive über den PIA Interrupts erzeugt werden.
TMR1/2 TEST: | Es werden die beiden TIMER des VIA getestet
CASS1/2 TEST: | Es werden die beiden Cassetten-Ports getestet Beim Lesen werden Interrupts erzeugt (VIA, PIA)
IEEE Tests: | Es werden Daten und Steuersignale getestet. Die IEEE-Buffer werden mitgetestet

English:

CHKSM TEST: | In order to check whether the test program has been loaded correctly into the zero page, a checksum is formed which must result 00.
VIDEO RAM TEST: | Data is written to each screen address, read back and compared
32K RAM TEST: | The entire RAM memory except for the zero page and stack is tested
ROM TEST: | Checksums are generated from each ROM (see list of checksums)
RFRSH TEST: | Data is written to the RAMs, waited for a while and the data is read out again. This checks whether the refresh is OK
KEYBOARD TEST: | The function of the decoder and the PIA is checked
50 HZ IRQ TEST: | It is tested whether interrupts are generated by the signal Vert Drive via the PIA
TMR1 / 2 TEST: | The two TIMERS of the VIA are tested
CASS1 / 2 TEST: | The two cassette ports are tested When reading, interrupts are generated (VIA, PIA)
IEEE Tests: | Data and control signals are tested. The IEEE buffers are also tested

# 7. Annotations

## 7.1. 3D printed Case

The case of Rev. 0 is not suitable for any later version of the PCB than Rev.0. The PCBs rev. 1 and 2 require the case revision 1. PCB Rev. 3 requires a Case Rev. 3

For the switch, two M2x5 screws are required. For the case, four C2.9 x 9.5 (DIN7981) self-tapping plastic screws are recommended.

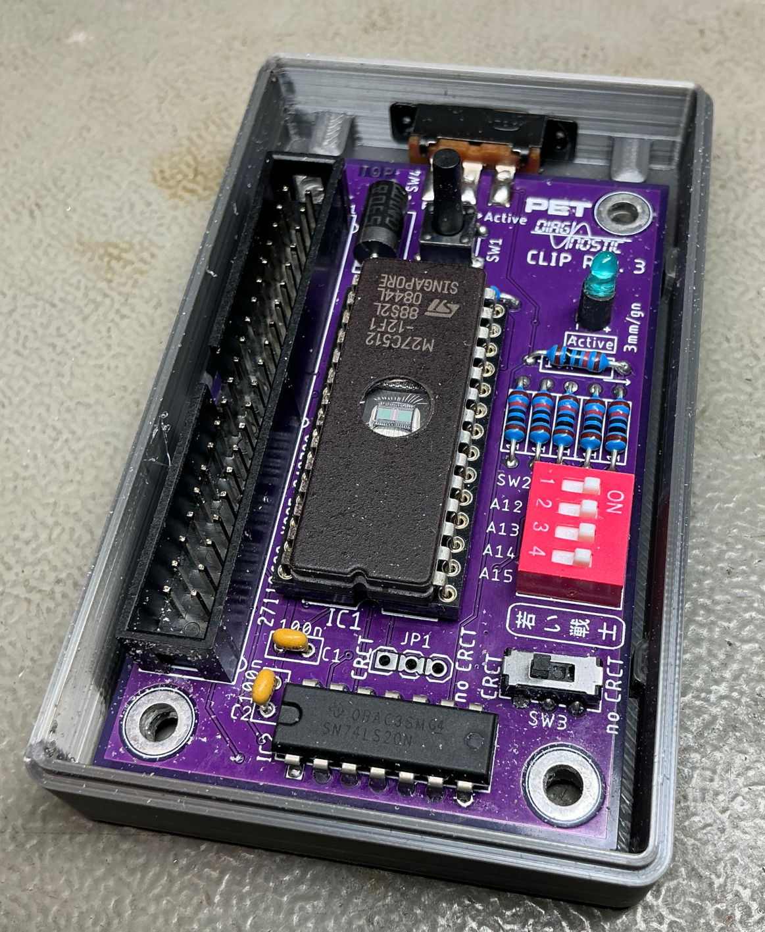
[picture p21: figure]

Figure 2: PCB v3 in bottom shell of the case

## 7.2. Ribbon Cable

The ribbon cable is used to connect the Diagnostic Clip (Box) to the 6502 Ribbon Cable Adapter. Since it directly connects to the address and data bus of the 6502, this ribbon cable should not be too long. 10cm -15cm are tested and acceptable.

The strain reliefs should be installed properly, because it is expected to be connected and disconnected several times.

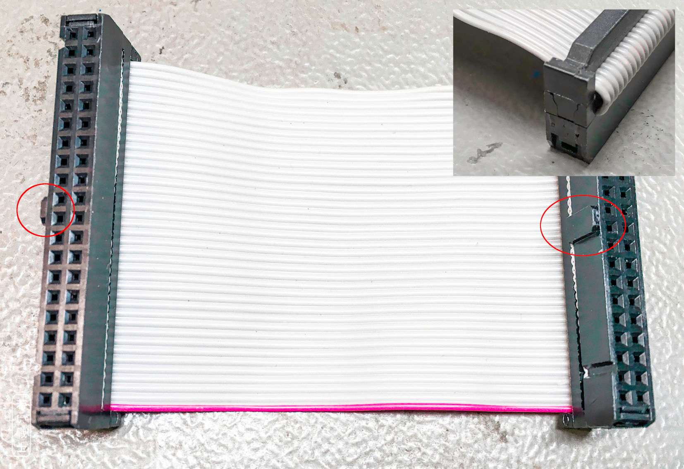
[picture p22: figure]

Figure 10: Ribbon cable

Building the ribbon cable is fairly simple. The ribbon cable itself is cut to length, both ends should be cut off perpendicular to the cable. The red wire marks pin one.

- Insert the cable into the IDC receptacle, be aware of the orientation (Figure 10, rec circles)
- Slightly squeeze the connector (to hold the ribbon cable)
- check, if the wires are placed exactly over the blades of the connector
- squeeze the connector with a vice (or a special IDC tool)
- bend the ribbon cable over the top of the connector and install the strain relief (Figure 10, top right).

Note: IDC means “Insulation-Displacement Connector”. When the crimping is carried out properly, the wires cold-weld to the blades, resulting in a gas tight connection. Refer to http://tech.guitarsite.de/cable_making.html#Ribbon%20Cables

# 8. Revision History

## 8.1. Rev. 0

- Prototype tested successfully with an 8032. Need for improvement.

## 8.2. Rev. 1

- DIP switch SW2 is 4 position now (no more “active”)
- Slide switch SW3 is new (CRTC « non CRTC)
- Slide switch SW4 is new (active « remove)

## 8.3. Rev. 2

- Support of the AND-gates on the ribbon cable adapter to set A13 and A14 low (for non CRTC mainboards).
- SW3 different circuit
- JP6 1x3 pin, different circuit
- Requires 6502 ribbon cable adapter Rev. 1 or later
- No more 3M DIP40 clip possible for non CRTC machines, since no grounding of A13 and A14

## 8.4. Rev. 3

- Active «Remove switch direct solder
- /NORAM is switched with the above switch (CBM8296 compatibility)
- New case Rev. 3 for the clip

PETDiagClip_ModD.docx 20.07.2026 20:00 Drafted by Sven Petersen Page 15 of 15 Doc.-No.: 163-6-01-03

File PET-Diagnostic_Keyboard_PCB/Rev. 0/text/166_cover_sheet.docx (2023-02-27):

Project Documentation

Commodore PET/CBM80xx/40xx Diagnostic Keyboard PCB

Project number: 166

Revision: 0

Date: 27.10.2020

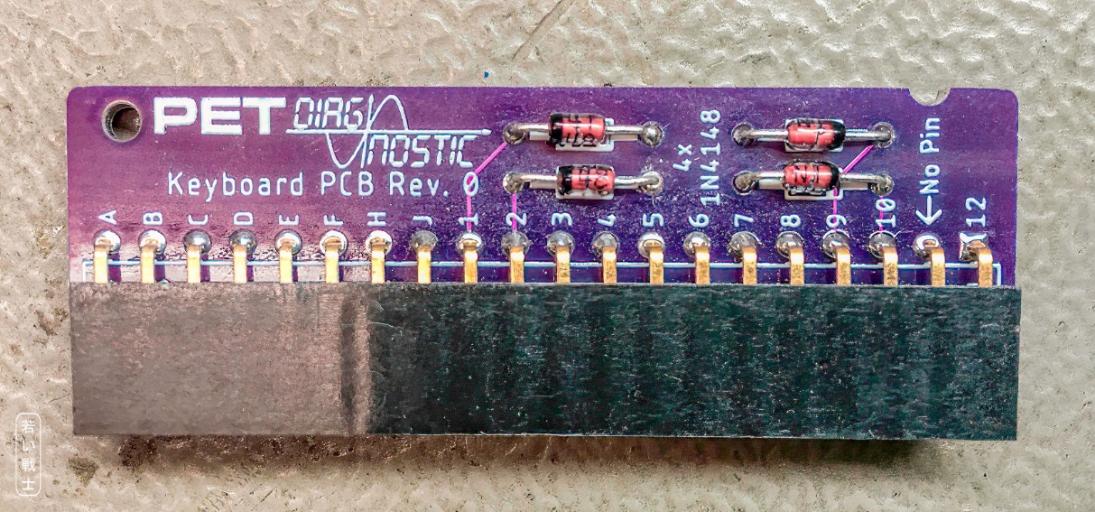
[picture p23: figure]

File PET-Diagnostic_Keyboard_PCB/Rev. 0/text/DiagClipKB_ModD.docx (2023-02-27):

Commodore PET/CBM80xx/40xx Diagnostic Keyboard PCB Rev. 0

Module Description

# Introduction

The Keyboard PCB is part of the Diagnostic Clip project. Originally, it was made with a connector and wires, but since PCBs got cheap and provide interconnects very reproduceable with a low failure rate, it is a very simple board design.

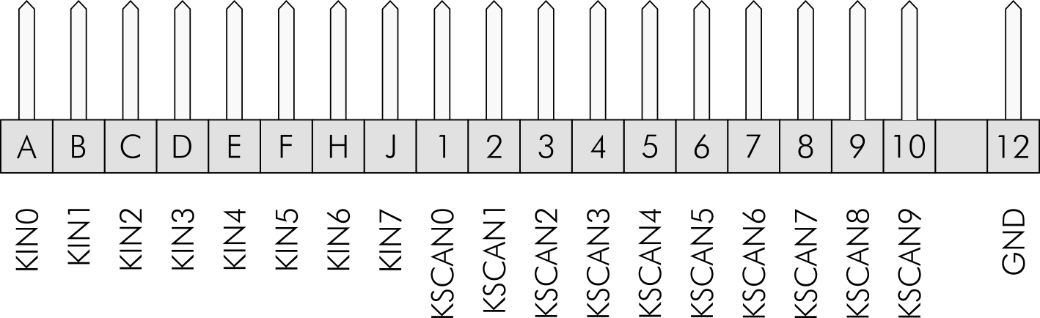
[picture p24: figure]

Figure 1: Pinout of the keyboard connector

KSCANx are the open collector outputs of a 74LS145 BCD to Decimal Decoder. So, it is not critical to connect more than one KeyScan Signal, nevertheless, the keyboard PCB provides diodes for a wired-AND connection, in case the slightly rare 74LS145 was replaced with another IC, that does not provide open collector outputs. The diodes could be replaced by a wire bridge.

Pins | Connected Signals
A-1-9 | KIN0 - KeyScan0 - KeyScan8
B-2-10 | KIN1 - KeyScan1 - KeyScan9
C-3 | KIN2 - KeyScan2
D-4 | KIN3 - KeyScan3
E-5 | KIN4 - KeyScan4
F-6 | KIN5 - KeyScan5
H-7 | KIN6 - KeyScan6
J-8 | KIN7 - KeyScan7

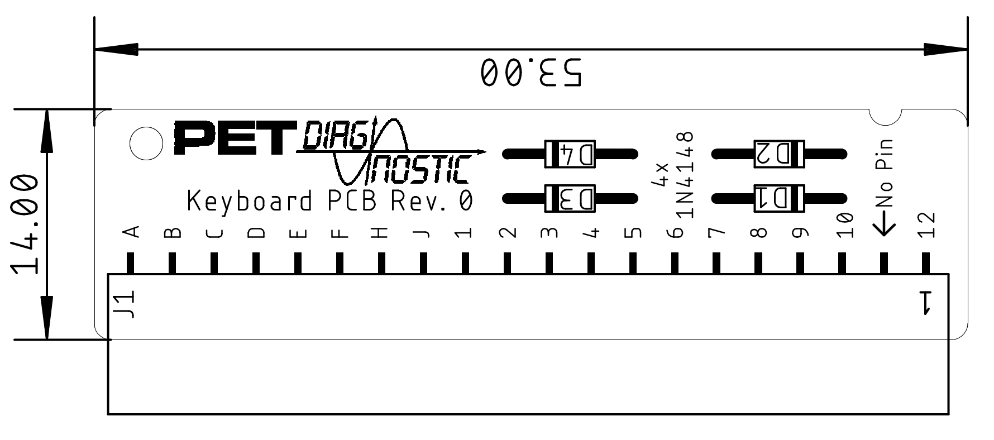
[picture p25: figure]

Figure 2: Dimensions of the Keyboard PCB

# Revision History

## Rev. 0

- Fully functional prototype

DiagClipKB_ModD.docx 26.02.2023 18:50 Drafted by Sven Petersen Page 2 of 2 Doc.-No.: 166-6-01-00

DiagClipKB_ModD.docx 26.02.2023 18:50 Drafted by Sven Petersen Page 1 of 1 Doc.-No.: 000-6-00-00

ENZIANWEG 16 ● 83052 BRUCKMÜHL TEL (08062) 728704 ● FAX (08062) 728705

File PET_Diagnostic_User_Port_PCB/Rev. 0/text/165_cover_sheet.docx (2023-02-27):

Project Documentation

Commodore PET/CBM80xx/40xx Diagnostic User Port PCB

Project number: 165

Revision: 0

Date: 27.10.2020

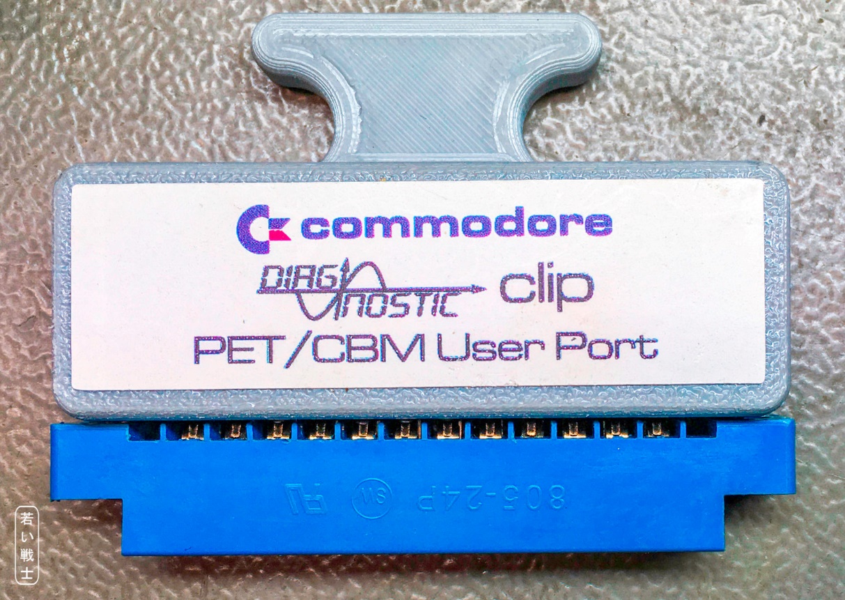
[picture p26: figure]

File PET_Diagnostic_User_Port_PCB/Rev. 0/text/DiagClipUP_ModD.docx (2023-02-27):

Commodore PET/CBM80xx/40xx Diagnostic User Port PCB Rev. 0

Module Description

# Introduction

The User Port PCB is part of the Diagnostic Clip project. Originally, it was made with a connector and wires, but since PCBs got cheap and provide interconnects very reproduceable with a low failure rate, it is a very simple board design.

The user port dongle/PCB connects the video signals and, IEEE Control signals and DIAGSENS & GRAPHIC to the GPIO pins of the user port. Further, it connects the tape read #1/#2 to the tape write signal. Not all user port signals are involved, so the user port is not completely tested.

Pins | Connected Signals
2-B | TVVIDEO - CA1
3-C | IEEESRQ - PA0
4-D | IEEEEOI - PA1
5-E-11 | DIAGSENS - PA2 - GRAPHIC
6-7-8 | TPREAD2 - TPWRITE - TPREAD1
9-K | TVVERT - PA6
10-L | TVHOR - PA7

The source of the information, that was required to design this PCB was retrieved from http://www.zimmers.net/anonftp/pub/cbm/schematics/computers/pet/diagnostics.txt

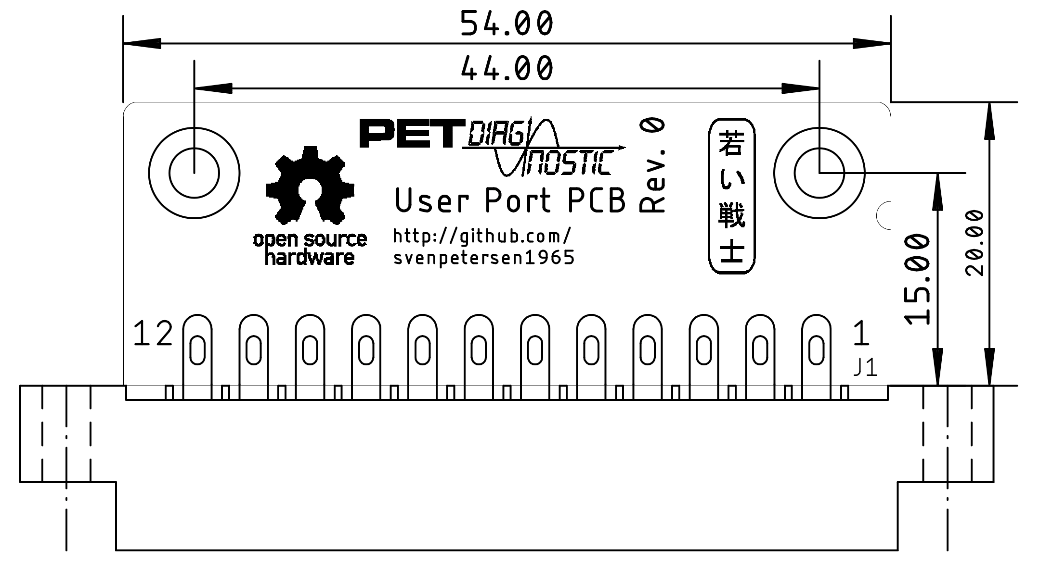
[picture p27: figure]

Figure 1: Dimensions of the User Port PCB

The 3D printable case requires two screws. Type C2.9 x 9.5 (DIN7981) self-tapping plastic screws are recommended.

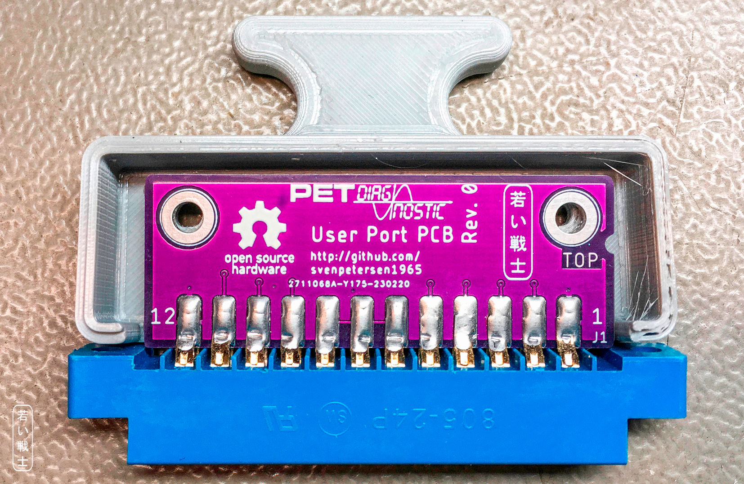
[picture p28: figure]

# Revision History

## Rev. 0

- Fully functional prototype

DiagClipUP_ModD.docx 27.02.2023 21:19 Drafted by Sven Petersen Page 2 of 2 Doc.-No.: 165-6-01-00

DiagClipUP_ModD.docx 27.02.2023 21:19 Drafted by Sven Petersen Page 1 of 1 Doc.-No.: 000-6-00-00

ENZIANWEG 16 ● 83052 BRUCKMÜHL TEL (08062) 728704 ● FAX (08062) 728705

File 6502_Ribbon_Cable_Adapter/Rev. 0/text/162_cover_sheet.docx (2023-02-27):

Project Documentation

Commodore PET/CBM 6502 Ribbon Cable Adapter

Project number: 162

Revision: 0

Date: 24.10.2020

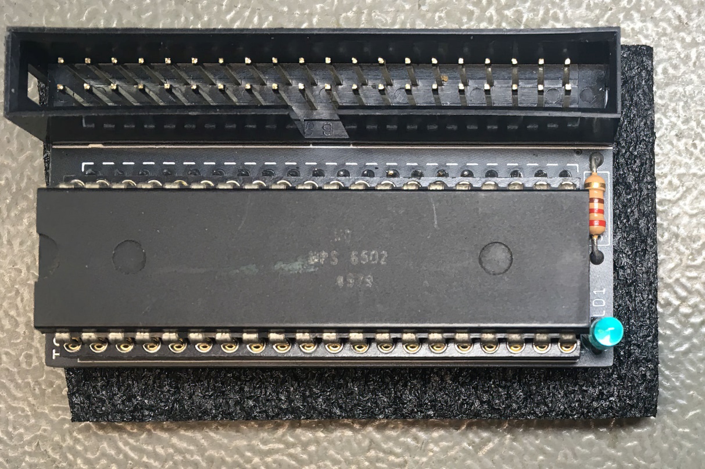
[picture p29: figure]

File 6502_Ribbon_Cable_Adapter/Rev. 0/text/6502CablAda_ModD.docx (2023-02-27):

Commodore PET/CBM 6502 Ribbon Cable Adapter Rev. 0

Module Description

# Introduction

The 6502 Ribbon Cable Adapter is part of the PET Diagnostic Clip assembly. It replaces the actual DIP40 clip, which is available from Mouser etc. for about US$50. It provides a connection of the 6502 µprocessor to a 40 pin box header. The 6502 is inserted into its socket and it is then connected to the socket of the 6502 on the mainboard of the PET.

The Ribbon Cable Adapter (with or without the clip) can remain in the mainboard for normal operation.

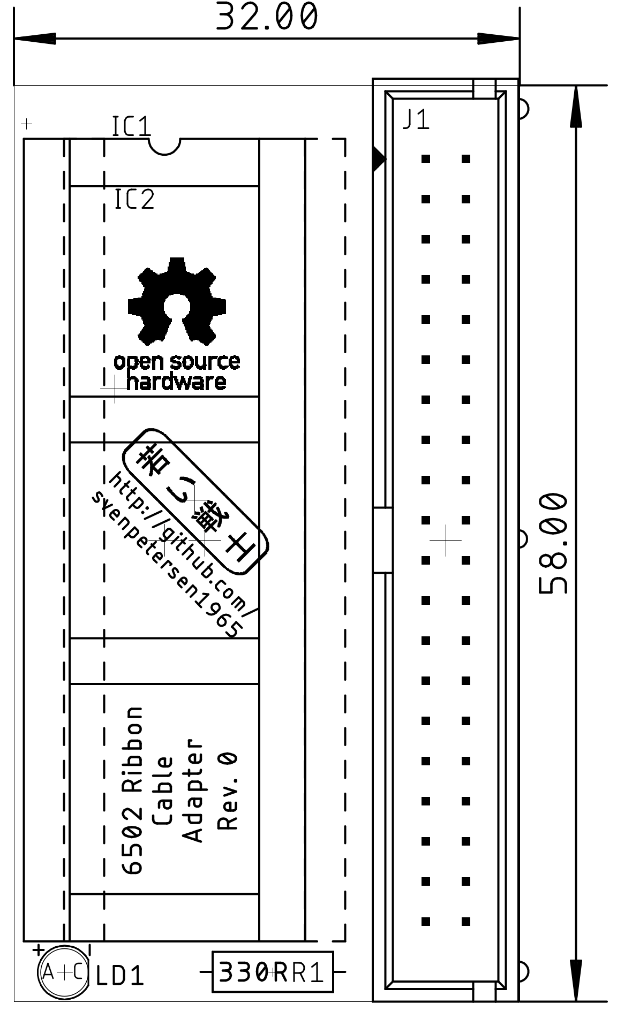
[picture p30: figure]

Figure 1: Dimensions of the 6502 Ribbon Cable Adapter#

# Connectors

## J1 – Clip Connector

Signal | Pin | Pin | Signal
GND (6502, Pin 1) | 1 | 2 | /RES
RDY | 3 | 4 | PHI2
PHI | 5 | 6 | S.O.
/IRQ | 7 | 8 | PHI0
/NOROM | 9 | 10 | n.c. (6502, Pin 36)
/NMI | 11 | 12 | n.c. (6502, Pin 35)
SYNC | 13 | 14 | R//W
5V | 15 | 16 | DB0
AB0 | 17 | 18 | DB1
AB1 | 19 | 20 | DB2
AB2 | 21 | 22 | DB3
AB3 | 23 | 24 | DB4
AB4 | 25 | 26 | DB5
AB5 | 27 | 28 | DB6
AB6 | 29 | 30 | DB7
AB7 | 31 | 32 | AB15
AB8 | 33 | 34 | AB14
AB9 | 35 | 36 | AB13
AB10 | 37 | 38 | AB12
AB11 | 39 | 40 | GND (6502, Pin 21)

It is advised to use a ribbon cable, not longer than 15cm and to install the strain reliefs.

## IC1(socket for the 6502, IC2 (6502 pin header)

Signal | Pin | Pin | Signal
To J1 Pin 1(GND) | 1 | 40 | /RES
RDY | 2 | 39 | PHI2
PHI | 3 | 38 | S.O.
/IRQ | 4 | 37 | PHI0
/NOROM | 5 | 36 | To J1, pin 10
/NMI | 6 | 35 | To J1, pin 12
SYNC | 7 | 34 | R//W
5V | 8 | 33 | DB0
AB0 | 9 | 32 | DB1
AB1 | 10 | 31 | DB2
AB2 | 11 | 30 | DB3
AB3 | 12 | 29 | DB4
AB4 | 13 | 28 | DB5
AB5 | 14 | 27 | DB6
AB6 | 15 | 26 | DB7
AB7 | 16 | 25 | AB15
AB8 | 17 | 24 | AB14
AB9 | 18 | 23 | AB13
AB10 | 19 | 22 | AB12
AB11 | 20 | 21 | GND

The precision round pins are very fragile. It is advised to keep them in a second DIP40 round pin socket.

# Revision History

## Rev. 0

- Working prototype

Dokument1 23.02.2023 20:13 Drafted by Sven Petersen Page 2 of 2 Doc.-No.: 162-6-01-00

Dokument1 23.02.2023 20:13 Drafted by Sven Petersen Page 1 of 1 Doc.-No.: 000-6-00-00

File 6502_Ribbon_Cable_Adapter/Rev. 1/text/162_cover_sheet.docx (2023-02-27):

Project Documentation

Commodore PET/CBM 6502 Ribbon Cable Adapter

Project number: 162

Revision: 1

Date: 01.01.2023

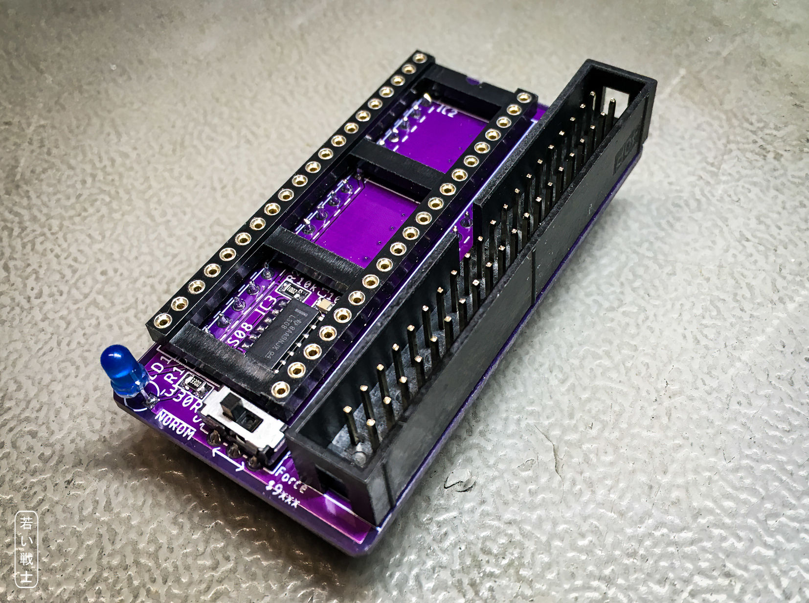
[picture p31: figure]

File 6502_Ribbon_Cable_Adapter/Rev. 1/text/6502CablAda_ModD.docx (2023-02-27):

Commodore PET/CBM 6502 Ribbon Cable Adapter Rev. 1

Module Description

# Introduction

The 6502 Ribbon Cable Adapter is part of the PET Diagnostic Clip assembly. It replaces the actual DIP40 clip, which is available from Mouser etc. for about US$50. It provides a connection of the 6502 µprocessor to a 40 pin box header. The 6502 is inserted into its socket and it is then connected to the socket of the 6502 on the mainboard of the PET.

The Ribbon Cable Adapter (with or without the clip) can remain in the mainboard for normal operation.

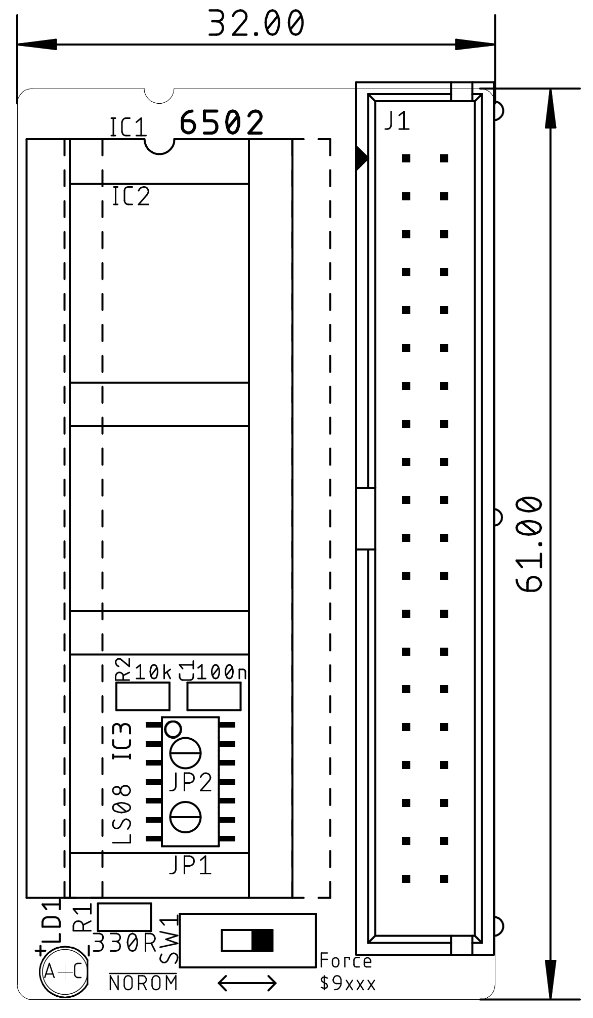
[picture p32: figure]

Figure 1: Dimensions of the 6502 Ribbon Cable Adapter

To prevent the need to short circuit the address lines AB13 and AB14 to GND to redirect kernal ROM accesses from $Fxxx to $9xxx (the lower EDIT ROM address space), two AND gates (IC3: 74LS08) are inserted directly after the processor address lines (A13 and A14). This way, the address lines can be set low. This kind of redirection is required for all “non CRTC type PETs, which are not capable to switch off all system ROMs with the /NOROM signal (being low). This feature requires a diagnostic clip rev. 2 (or later).

# Switch SW1

The switch has to be set to “Force $9xxx” for these non-CRTC mainboards. The CRTC mainboards make use of the /NOROM signal and do not require the said redirection.

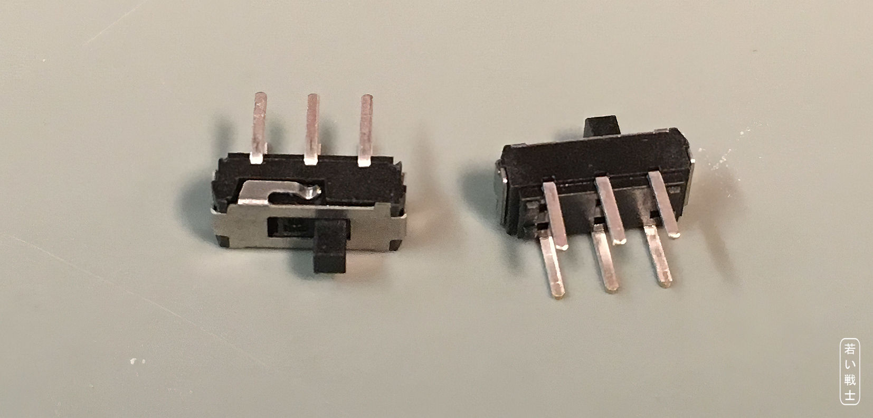
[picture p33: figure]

Figure 2: Mini slide switch

These mini slide switches can be found on Amazon, Ebay and AliExpress. A possible search term is “mini slide switch dpdt” or “MSS22D18”, which will not show these switches exclusively, but it should not be too hard to find the right ones.

# Assembly

First, the SMD components are soldered.

The precision round pins should be aligned properly. For this purpose, they are inserted into the DIP40 socket, inserted into the solder pads, soldered one pin each, checked, if they are properly aligned and vertical, adjusted if required and finally soldered completely.

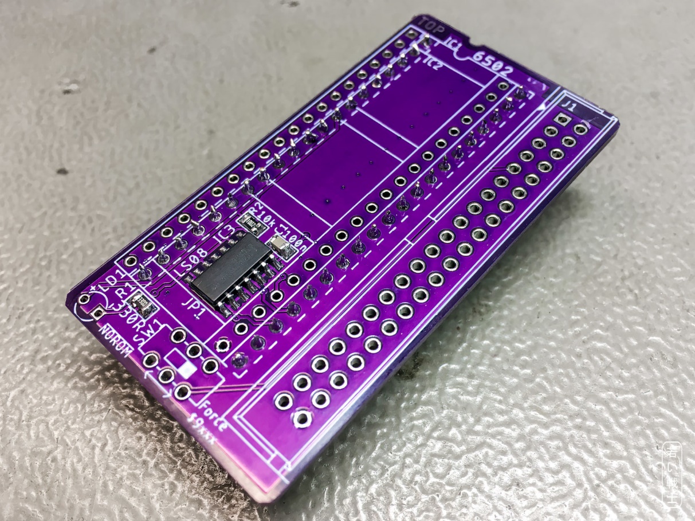
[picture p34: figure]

Figure 3: First steps - SMD components and pin strips assembled


Figure 4: bottom side of the assembled board

# Connectors

## J1 – Clip Connector

Signal | Pin | Pin | Signal
GND (6502, Pin 1) | 1 | 2 | /RES
RDY | 3 | 4 | PHI2
PHI | 5 | 6 | S.O.
/IRQ | 7 | 8 | PHI0
/NOROM | 9 | 10 | n.c. (6502, Pin 36)
/NMI | 11 | 12 | n.c. (6502, Pin 35)
SYNC | 13 | 14 | R//W
5V | 15 | 16 | DB0
AB0 | 17 | 18 | DB1
AB1 | 19 | 20 | DB2
AB2 | 21 | 22 | DB3
AB3 | 23 | 24 | DB4
AB4 | 25 | 26 | DB5
AB5 | 27 | 28 | DB6
AB6 | 29 | 30 | DB7
AB7 | 31 | 32 | AB15
AB8 | 33 | 34 | AB14
AB9 | 35 | 36 | AB13
AB10 | 37 | 38 | AB12
AB11 | 39 | 40 | GND (6502, Pin 21)

It is advised to use a ribbon cable, not longer than 15cm and to install the strain reliefs.

## IC1(socket for the 6502, IC2 (6502 pin header)

Signal | Pin | Pin | Signal
To J1 Pin 1(GND) | 1 | 40 | /RES
RDY | 2 | 39 | PHI2
PHI | 3 | 38 | S.O.
/IRQ | 4 | 37 | PHI0
/NOROM | 5 | 36 | To J1, pin 10
/NMI | 6 | 35 | To J1, pin 12
SYNC | 7 | 34 | R//W
5V | 8 | 33 | DB0
AB0 | 9 | 32 | DB1
AB1 | 10 | 31 | DB2
AB2 | 11 | 30 | DB3
AB3 | 12 | 29 | DB4
AB4 | 13 | 28 | DB5
AB5 | 14 | 27 | DB6
AB6 | 15 | 26 | DB7
AB7 | 16 | 25 | AB15
AB8 | 17 | 24 | AB14
AB9 | 18 | 23 | AB13
AB10 | 19 | 22 | AB12
AB11 | 20 | 21 | GND

The precision round pins are very fragile. It is advised to keep them in a second DIP40 round pin socket.

# Revision History

## Rev. 0

- Working prototype

## Rev. 1

- Tested good with Diagnostic Clip Board Rev. 2

6502CablAda_ModD.docx 23.02.2023 20:04 Drafted by Sven Petersen Page 2 of 2 Doc.-No.: 162-6-01-01

6502CablAda_ModD.docx 23.02.2023 20:04 Drafted by Sven Petersen Page 1 of 1 Doc.-No.: 000-6-00-00

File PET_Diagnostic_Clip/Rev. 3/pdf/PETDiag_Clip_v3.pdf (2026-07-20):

# Project Documentation

## Commodore PET/CBM80xx/40xx Diagnostic Clip

## Project number: 163

## Revision: 3

## Date: 19.03.2024


PETDiagClip_ModD.docx | | 20.07.2026 20:00
Drafted by Sven Petersen | Page 1 of 17 | Doc.-No.: 163-6-01-03

### Commodore PET/CBM80xx/40xx Diagnostic Clip Rev. 3

### Module Description

Table Of Contents


Drafted by Sven Petersen | Page 2 of 17 | Doc.-No.: 163-6-01-03

## 1. Introduction

The diagnostic clip is a diagnostic tool, which is originally issued by Commodore. It contains the diagnostic software, which has to fit to the board type, that is tested. For testing, it is connected to the 6502, switches off the ROMs on the mainboard and/or redirects the Kernal accesses to its built in EPROM.

Figure 1: Dimension of the PCB

The original hardware consists of:

- DIP40 test clip (3M is still producing this kind of clip – They are available from Mouser and Digikey: https://www.digikey.com/en/products/detail/3m/923743-40/12075, which is $94.07 in February 2023)
- the box with the EPROM/Test software)
- the keyboard feedback dongle
- user port feedback dongle

There is an extra box for each version of the software.

The goal of this development is to eliminate the need for an expensive DIP40 test clip and to merge the different box designs to one PCB. Further, shorting A13 and A14 to GND should be prevented.

The result is a 4 PCB solution:

- the clip box with a ribbon cable

Drafted by Sven Petersen | Page 3 of 17 | Doc.-No.: 163-6-01-03
- a ribbon cable adapter for the 6502
- a keyboard feed back
- a user port feed back

The EPROM in the clip box is fully connected to the 6502 µprocessor address and data bus. When connected (and configured properly), the test software is run after powering up the machine. The two main types of mainboards require different methods of making the test software appear in the system.

- CRTC machines, like the 8032, have a signal, which can switch off all ROMs on the mainboard (except the character set) and the test software resides at $Fxxx instead of the Kernal. It comes with its own RESET vector @ $FFFC/D (it points to $F000, the start of the test software)
- Non CRTC machines, like the PET2001 or CBM30xx: the Kernal access is redirected to the option ROM address space $9xxx. This happens by (brutally) shorting the address signals A13 and A14 to GND – $F/1111BIN becomes a $9/1001BIN. The test software starts at $9800, the redirected reset vector is now at $9FFC/D and it points to $9800

Note: CRTC means “Cathode Ray Tube Controller. The first PETs had a video circuit, solely consisting
of TTL ICs and the Character ROM. This includes the first “dynamic PETs”, like the CBM 30xx. The
later machines had a controller chip (6545) as the heart of the video circuit. It can be configured for 40 column and 80 column machines and is a bit more flexible. The CBM 80xx and most CBM 40xx are CRTC machines.

For testing the CBM8296, it is required to switch the /NOROM signal off while the Active « Remove switch is in the Remove state, since it is also controlled by software. This is realize in Rev. 3.

## 2. Test procedure

### 2.1. Brief discription

The diagnostic hardware (clip/ribbon cable adapter, clip box, keyboard and user port dongles have to be connected before power up.

After power up, the diagnostic software is started. It consists or the first basic tests, which make sure, that the basic system is working:

- Printing the character set on the screen

### - Testing the “TV RAM” (screen memory)

- Testing the Zero Page
- Testing the stack
- Copying the actual test software into the RAM, starting at $0200. Jumping to that software
- Waiting for the clip to be removed

NOTE: A switch installed on JP5 allows to switch off , which is logically removing the clip EPROM from the system. As a non-CRTC machine the CBM3016 was tested.

The copied test software first waits for the clip to be removed by checking the (redirected) reset vector. If it does not point to $F000 or $9800 for a couple of seconds, it is assumed, that the clip is removed. Then testing is proceeded:

- Video Test
- Checksum Test (CRTC machines)
- Horizontal (video) Test
- Video RAM Test (CRTC machines)

Drafted by Sven Petersen | Page 4 of 17 | Doc.-No.: 163-6-01-03
- 32k RAM test
- ROM Test (shows checksum only)
- Refresh Test (dynamic RAM refresh)
- Keyboard Test
- 60Hz (non CRTC) or 50Hz (CRTC) IRQ (interrupt) test
- Timer 1 Test
- Timer 2 Test
- Cassette 1 Test
- Cassette 2 Test
- IEEE DIO Test
- IEEE Ctrl Test

This part of the test is cycling until the Reset switch is pressed or the computer is power down. The tests are described in chapter 6.2.2

### 2.2. Notes

The user port is used to monitor the video signals, SRQ and EOI from the IEEE Bus, the Tape write
and read signals and the “Diagsens” and “Graphic” signal.

I would not consider this as a proper user port test.

The IEEE signals are fed back internally, there is no external feedback, so the driver chips are not tested.

The tape port TPWRITE signal on the user port us fed back to both TPREAD1 and TPREAD2. CASS SWITCH #1 and #2 are not tested, neither is CASS MOTOR #1 and #2.

The testing will stop on the first failed test.

## 3. Diagnostic Software


Drafted by Sven Petersen | Page 5 of 17 | Doc.-No.: 163-6-01-03

### 3.1. 80 col CRTC

The file name in the “Diagnostic Software” folder is “80_col_diagnostic_v1.1.bin”. It is suitable for 80 col 80xx and 40xx machines (with the 12” monitor).

Figure 1: 80_col_diagnostic_v1.1.bin - first page
After removing the clip, respectively switching it to “remove”, the test continues on the 2nd page.

Figure 2: 80_col_diagnostic_v1.1.bin - second page


Drafted by Sven Petersen | Page 6 of 17 | Doc.-No.: 163-6-01-03

### 3.2. 40 col CRTC

Since no such a computer is available, just the opening page can be shown on a 40 col. screen. A further test on a non CRTC machine (CBM3016) fails. The test itself passes on the CBM8032, but the output screen is not properly aligned.

Figure 3: 40_col_diagnostic_v2.0.bin - first page

Figure 4: 40_col_diagnostic_v2.0.bin - second page (on an 80 col machine)


Drafted by Sven Petersen | Page 7 of 17 | Doc.-No.: 163-6-01-03

### 3.3. 40 col non-CRTC

This test should work with all 40 column non-CRTC machines. The 2nd page is scrolling, so an upper and lower half of the looping test is shown.

Figure 5: 901447-30_diagnostic_320350g_$9000.bin - first page

Figure 6: 901447-30_diagnostic_320350g_$9000.bin - 2nd page (upper half)


Drafted by Sven Petersen | Page 8 of 17 | Doc.-No.: 163-6-01-03

Figure 7: 901447-30_diagnostic_320350g_$9000.bin - 2nd page (lower half)

## 4. Complete Diagnostic Clip Set

In Figure 8 all required PCBs are shown, including the short 40 pin ribbon cable.

Figure 8: Diagnostic set, 6502 inserted in Ribbon cable adapter


Drafted by Sven Petersen | Page 9 of 17 | Doc.-No.: 163-6-01-03

Figure 9: Diagnostic clip connected to the 6502 ribbon cable adapter (in the CBM8032)

Drafted by Sven Petersen | Page 10 of 17 | Doc.-No.: 163-6-01-03

## 5. Connectors and Jumpers

### 5.1. J1 – Connector to test clip/6502 Ribbon Cable Adapter

A 2x20 box connector, 2.54mm pitch

Signal | Pin | Pin | Signal
GND (6502, Pin 1) | 1 | 2
RDY | 3 | 4 | PHI2
PHI | 5 | 6 | S.O.
| 7 | 8 | PHI0
| 9 | 10 | n.c. (6502, Pin 36)
| 11 | 12 | n.c. (6502, Pin 35)
SYNC | 13 | 14 | R/
5V | 15 | 16 | DB0
AB0 | 17 | 18 | DB1
AB1 | 19 | 20 | DB2
AB2 | 21 | 22 | DB3
AB3 | 23 | 24 | DB4
AB4 | 25 | 26 | DB5
AB5 | 27 | 28 | DB6
AB6 | 29 | 30 | DB7
AB7 | 31 | 32 | AB15
AB8 | 33 | 34 | AB14
AB9 | 35 | 36 | AB13
AB10 | 37 | 38 | AB12
AB11 | 39 | 40 | GND (6502, Pin 21)

### 5.2. Jumpers & Switches

### 5.2.1. SW1 Reset Switch

The Reset switch serves for resetting the tested computer.

### 5.2.2. JP6/SW3 – AB13 & AB14

This selects the CRTC/non CRTC mode

Signal | Pin | Pin | Signal
n.c. | 1 | 2 | AS14
AB13 | 3 | 4 | AB14
GND | 5 | 6 | GND

CRTC machines, like the 80xx or most 40xx: Jumper 1 – 3 & 2 – 4.

Non-CRTC machines, like the PET20xx or CBM 30xx: Jumper 3 – 5 & 4 – 6.

Internally the mini slide Switch SW3 can be installed instead of JP6, which is the recommended solution.

Drafted by Sven Petersen | Page 11 of 17 | Doc.-No.: 163-6-01-03

### 5.2.3. SW2 – The DIP Switch

The DIP-Switch serves for selecting the test software (one of 16 possible) from the EPROM (27C512) that can be run on the clip. The size of the test software is 4kByte, while the size of the EPROM is 64kByte. If it is desired to have a smaller EPROM, the highest (not required) address bits have to be HIGH and the DIP-switch can be smaller.

EPROM | SW | Address Bits | DIP-Switch
27C256 | 8x4k | A15 open/HIGH | position 1-3
27C128 | 4x4k | A15&A14 open/HIGH | position 1-2
27C64 | 2x4k | A15&A14&A13 open/HIGH | position 1
The OFF position of a switch means HIGH, the ON Position means LOW.
4 | 3 | 2 | 1 | A15..12 | 4k Slot | EPROM Offset
on | on | on | on | 0000 | 0 | $0000
on | on | on | off | 0001 | 1 | $1000
on | on | off | on | 0010 | 2 | $2000
on | on | off | off | 0011 | 3 | $3000
on | off | on | on | 0100 | 4 | $4000
on | off | on | off | 0101 | 5 | $5000
on | off | off | on | 0110 | 6 | $6000
on | off | off | off | 0111 | 7 | $7000
off | on | on | on | 1000 | 8 | $8000
off | on | on | off | 1001 | 9 | $9000
off | on | off | on | 1010 | 10 | $A000
off | on | off | off | 1011 | 11 | $B000
off | off | on | on | 1100 | 12 | $C000
off | off | on | off | 1101 | 13 | $D000
off | off | off | on | 1110 | 14 | $E000
off | off | off | off | 1111 | 15 | $F000

### 5.2.4. SW4 – Active/Remove Switch

This switch is initially set to “Active”, after the computer is started (by power on or reset), the
diagnostics software runs the first page/part of the diagnostic test routine (Figure 1 and Figure 3). In this state, the internal signal is pulled LOW and is connected to the (external) signal that is connected to the CPU socket pin 5 and the rest of the computer.
To continue the diagnostic test, the switch SW4 has to be set to the “Remove” position. In this
position, the signal is HIGH (via pull-up R7) and it is also disconnected from the external signal.

The separation of the internal and the external signal has no effect with the PETs or CBM40xx and 80xx, but obviously the CBM8296 can modify the signal via a register to access the RAM, which is in the same address space of the ROMs. Since there is no real clip in this project, which is physically disconnected from the computer, the signal has to be separated with SW4 to prevent the clip from interfering with the test.

## 6. Resources

### 6.1. Websites

The information for creating this project, like the schematics of the original diagnostic clips and

### some test software was retrieved from André Fachat’s website:

- http://www.6502.org/users/andre/petindex/diag/index.html

Drafted by Sven Petersen | Page 12 of 17 | Doc.-No.: 163-6-01-03

Further test software and the connections of the keyboard and user port feedback was retrieved

### from Bo Zimmerman’s website:

- http://www.zimmers.net/anonftp/pub/cbm/firmware/computers/pet/other/index.html
- http://www.zimmers.net/anonftp/pub/cbm/schematics/computers/pet/diagnostics.txt

### 6.2. Commodore Training: 40xx/80xx Service Manual

Some further descriptions can be found in the (German) "Commodore Training_40xx_80xx_Service Manual" (https://www.retro-commodore.eu/2017/02/26/commodore-service-training-material-for-cbm-40xx80xx/) on Carsten's great retro-commodore.eu website .

Page 33ff:

### 6.2.1. DIAGNOSTIC BOX DESCRIPTION

"DIAGNOSTIC-BOX BESCHREIBUNG

Die Diagnostic-Box ist ein Testger‰t, mit dem die wichtigsten Komponenten auf der Logic-Platine der Zentraleinheiten getestet und ein hoher Prozentsatz der Fehler gefunden werden kann.

Die Tastatur selbst und das Video-Board wird nicht ¸berpr¸ft. Fŗ jede Zentraleinheit gibt es eine spezielle Diagnostic-Box.

Anschlufl und Starten des Testprogramms:

Zur Diagnostic-Box gehˆren zwei Diagnostic-Stecker, einer fŗ den User-Port und einer fŗ die Tastatur. An der Box befindet sich ein 40-poliges Flachbandkabel mit einem IC-Clip.

Dieser Clip wird auf den Prozessor gesteckt und die beiden Diagnostic-Stecker kommen an die entsprechenden Positionen

Wenn die rote LED leuchtet, kann das Diagnose-Programm durch drçken der roten Taste (Reset) gestartet werden.

Auf dem Bildschirm wird nun angezeigt welcher Test gerade l‰uft, ob er fehlerfrei durchl‰uft, oder was fŗ Fehler erkannt wurden. Wird ein Fehler erkannt, stoppt das Testprogramm. Treten keine Fehler auf, werden die Tests laufend wiederholt."

Translated to English:

"DIAGNOSTIC BOX DESCRIPTION

The Diagnostic-Box is a test device with which the most important components on the logic board of the central units are tested and a high percentage of errors can be found.

The keyboard itself and the video board are not checked. There is a special diagnostic box for each computer.

Connection and start of the test program:

The Diagnostic Box includes two diagnostic plugs, one for the User port and one for the keyboard. There is a 40-pin ribbon cable with an IC clip attached to the box.

This clip is put on the processor and the two diagnostic plugs are connected to the appropriate positions/connectors.

When the red LED lights up, the diagnostic program can be started by pressing the red button (Reset). The screen now shows which test is currently running and whether it is passed or failed, or what kind

Drafted by Sven Petersen | Page 13 of 17 | Doc.-No.: 163-6-01-03

of errors were detected. If an error is detected, the test program stops. if there are no fails, the tests are repeated continuously."

[...]

### 6.2.2. Test description

"Testbeschreibung

Nach Bet‰tigung der Reset-Taste wird der CRT-Controller initialisiert und der CBM-Zeichensatz in den oberen Teil des Bildschirms geschrieben womit festgestellt wird ob es ¸berhaupt mĝlich ist Daten auf den Bildschirm zu schreiben.

Nun wird Zero-Page und Stack getestet. Treten hier Fehler auf wird entweder ein RAM als defekt angezeigt oder eine Adressleitung.

Eine genaue Erkennung des Fehlers ist aber in manchen F‰llen nicht mĝlich, sodafl zum Teil unrichtige Fehlermeldungen ausgegeben werden. Um den Fehler zu lokalisieren kann man die CAS-Leitungen an den RAMs vertauschen und den Test neu starten. Wird wieder eine Fehlermeldung ausgegeben, so liegt der Fehler wahrscheinlich nicht an den RAM', sondern an der Ansteuerung (Adressleitungen, Refresh, RAS, CAS, RAM R/W, MUX A).

Ist Zero-Page und Stack in Ordnung wird ein Testprogramm in den RAM-Bereich geschrieben und die Aufforderung REMOVE CLIP erscheint auf dem Bildschirm.

Wird nun die Diagnostic-Box vom Prozessor entfernt, werden von dem in der Zero-Page befindlichen Testprogramm die weiteren Teile des Systems getestet. Die ausgegebenen Fehlermeldungen sind im Allgemeinen zuverl‰ssig."

English:

"Test description

After pressing the reset button, the CRT controller is initialized and the CBM character set is displayed on the upper part of the screen, which determines whether it is even possible to write data on the screen.

Now the zero-page and stack are tested. If errors occur here, either a RAM is displayed as defective or an address line

In some cases, however, an exact detection of the error is not possible, so that in some cases incorrect error messages are output. To localize the error, you can swap the CAS lines on the RAM's and restart the test. If an error message is output again, the error is probably not due to the RAM, but to the control (address lines, refresh, RAS, CAS, RAM R/W, MUX A).

If the zero page and stack are OK, a test program is written to the RAM area and the REMOVE CLIP request appears the screen.

If the diagnostic box is now removed from the processor, the other parts of the system are tested by the test program in the zero page. The error messages issued are generally reliable."

CHKSM TEST: | Um zu ¸berpr¸fen, ob das Testprogramm richtig in die Zero-Page geladen wurde, wird eine Pr¸fsumme gebildet die 00 ergeben mufl.
VIDEO RAM TEST: | Es werden in jede Bildschirmadresse Daten geschrieben wieder gelesen und verglichen
32K RAM TEST: | Es wird der gesamte RAM-Speicher aufler Zero-Page und Stack getestet
ROM TEST: | Es werden Pr¸fsummen von jedem ROM gebildet (siehe Liste der Pr¸fsummen)

Drafted by Sven Petersen | Page 14 of 17 | Doc.-No.: 163-6-01-03
RFRSH TEST: | Es werden Daten in die RAMs geschrieben, eine Zeit lang gewartet und die Daten wieder ausgelesen. So wird ¸berpr¸ft, ob der Refresh in Ordnung ist.
KEYBOARD TEST: | Es wird die Funktion des Decoders und des PIA ¸berpr¸ft
50 HZ IRQ TEST: | Es wird getestet, ob von dem Signal Vert Drive ¸ber den PIA Interrupts erzeugt werden.
TMR1/2 TEST: | Es werden die beiden TIMER des VIA getestet
CASS1/2 TEST: | Es werden die beiden Cassetten-Ports getestet Beim Lesen werden Interrupts erzeugt (VIA, PIA)
IEEE Tests: | Es werden Daten und Steuersignale getestet. Die IEEE-Buffer werden mitgetestet

English:

CHKSM TEST: | In order to check whether the test program has been loaded correctly into the zero page, a checksum is formed which must result 00.
VIDEO RAM TEST: | Data is written to each screen address, read back and compared
32K RAM TEST: | The entire RAM memory except for the zero page and stack is tested
ROM TEST: | Checksums are generated from each ROM (see list of checksums)
RFRSH TEST: | Data is written to the RAMs, waited for a while and the data is read out again. This checks whether the refresh is OK
KEYBOARD TEST: | The function of the decoder and the PIA is checked
50 HZ IRQ TEST: | It is tested whether interrupts are generated by the signal Vert Drive via the PIA
TMR1 / 2 TEST: | The two TIMERS of the VIA are tested
CASS1 / 2 TEST: | The two cassette ports are tested When reading, interrupts are generated (VIA, PIA)
IEEE Tests: | Data and control signals are tested. The IEEE buffers are also tested

## 7. Annotations

### 7.1. 3D printed Case

The case of Rev. 0 is not suitable for any later version of the PCB than Rev.0. The PCBs rev. 1 and

### 2 require the case revision 1. PCB Rev. 3 requires a Case Rev. 3

For the switch, two M2x5 screws are required. For the case, four C2.9 x 9.5 (DIN7981) self-tapping plastic screws are recommended.


Drafted by Sven Petersen | Page 15 of 17 | Doc.-No.: 163-6-01-03

Figure 2: PCB v3 in bottom shell of the case

### 7.2. Ribbon Cable

The ribbon cable is used to connect the Diagnostic Clip (Box) to the 6502 Ribbon Cable Adapter. Since it directly connects to the address and data bus of the 6502, this ribbon cable should not be too long. 10cm -15cm are tested and acceptable.

The strain reliefs should be installed properly, because it is expected to be connected and disconnected several times.


Drafted by Sven Petersen | Page 16 of 17 | Doc.-No.: 163-6-01-03

Figure 10: Ribbon cable

Building the ribbon cable is fairly simple. The ribbon cable itself is cut to length, both ends should be cut off perpendicular to the cable. The red wire marks pin one.

- Insert the cable into the IDC receptacle, be aware of the orientation (Figure 10, rec circles)
- Slightly squeeze the connector (to hold the ribbon cable)
- check, if the wires are placed exactly over the blades of the connector
- squeeze the connector with a vice (or a special IDC tool)
- bend the ribbon cable over the top of the connector and install the strain relief (Figure 10, top right).

### Note: IDC means “Insulation-Displacement Connector”. When the crimping is carried out

properly, the wires cold-weld to the blades, resulting in a gas tight connection. Refer to http://tech.guitarsite.de/cable_making.html#Ribbon%20Cables

## 8. Revision History

### 8.1. Rev. 0

- Prototype tested successfully with an 8032. Need for improvement.

### 8.2. Rev. 1 - DIP switch SW2 is 4 position now (no more “active”)

- Slide switch SW3 is new (CRTC « non CRTC)
- Slide switch SW4 is new (active « remove)

### 8.3. Rev. 2

- Support of the AND-gates on the ribbon cable adapter to set A13 and A14 low (for non CRTC mainboards).
- SW3 different circuit
- JP6 1x3 pin, different circuit
- Requires 6502 ribbon cable adapter Rev. 1 or later

Drafted by Sven Petersen | Page 17 of 17 | Doc.-No.: 163-6-01-03
- No more 3M DIP40 clip possible for non CRTC machines, since no grounding of A13 and A14

### 8.4. Rev. 3

- Active «Remove switch direct solder
- /NORAM is switched with the above switch (CBM8296 compatibility)
- New case Rev. 3 for the clip


Diagnostic Clip Sven Petersen

EDG

M27C512-DIP28; EDG; JTP-1130; DIPSW-04


non CRTC machines: diag SW @ $9xxx

CRTC machines: diag SW @ $Fxxx





EDG


PETDiagClip_Testing.docx | | 20.07.2026 20:01
Drafted by Sven Petersen | Page 1 of 2 | Doc.-No.: 163-6-02-03

### Commodore PET/CBM80xx/40xx Diagnostic Clip Rev. 3

### Testing

## Test Setup

The tests were conducted with the following setup:

- Diagnostic Clip Rev. 3
- 6502 Ribbon Cable Adapter Rev. 1
- Ribbon Cable (10 cm and 15 cm)
- User Port Dongle Rev. 0
- Keyboard Dongle Rev. 0
- Commodore CBM8032
- Commodore CBM3016

### The CBM8032 was tested with the software “80_col_diagnostic_v1.1.bin”

### The CBM3016 was tested with the software “901447-30_diagnostic_320350g_$9000.bin”

### The software “40_col_diagnostic_v2.0.bin” was partly tested with the CBM3016 and with the

CBM8032.

The 6502 was inserted into the ribbon cable adapter, which then was installed in the CPU socket of the respective computer. The ribbon cable was connected to the ribbon cable adapter.

Later, the diagnostic box was connected to the ribbon cable, the keyboard and the user port dongle were connected to the respective connector of the main board. The IEEE-488 interface was open, the cassette port was not connected to a Datassette.

Figure 1: Testing the Diagnostic Clip (v2) in the CBM 3016

Pos. Qty Value Footprint Ref.-No. Comment

1 1 163-2-01-03 2 Layer PCB Rev. 3 2 layer, Cu 35µ, HASL, 77.0mm x 47.0mm, 1.6mm FR4

2 1 DPDT switch 1X02 SW4 Reichelt.de: T217 or AliExpress SS22F25-G7

3 1 2x20 box header, 2.54mm

pitch

2X20WV J1 2x20, box pin header or standard pin header, e.g.

reichelt.de WSL 40G

4 2 100n/50V C-2,5 C1, C2 cer. cap, 2.5mm pitch

5 6 10k R-10 R1, R2, R3, R4, R6, R7 1/4W, 5%

6 1 1N5908 DO-201 D1 5V TVS diode. ST Micro. E.g. Reichelt: 1N 5908, tme.eu:

1N5908

7 1 330R R-10 R5 1/4W, 5%

8 1 3mm/gn 3MM LD1 standard LED 3mm/green + 5mm distance holder for 3mm

LED

9 1 74LS20 DIL-14 IC2 e.G. RENESAS, e.G. Reichelt LS 20

10 1 DIPSW-04 DIPSW-04V-

COMBI SW2 Standard DIP-Switch with 4 switches (switch side facing up) The DIP-Switch can be replaced with a 2 switch DIP Switch
and hardwire switch 3 and 4. Reichelt NT 04 or NT 02

11 1 mini slide switch, 2.54mm,

DPDT, through hole

DPDT_9MM SW3 Ali Express, ebay, Amazon, search term "MSS22D18"
12 1 JTP-1130 JTP-1130 SW1 standard TACT switch 6mm x 6mm, height = 13mm

13 1 JUMPER1x3 1X03 JP1 do not place

14 1 M27C512-DIP28 DIL28-6 IC1 M27C512 EPROM (or M27C256 or M27C128)

15 1 DIP 28 socket, low profile (IC1) e.g. Reichelt.de: GS 28P

16 2 2x20 pin IDC receptacle,

pitch 2.54mm

e.g. Reichelt.de: PFL 40

17 15 cm ribbon cable, 40p,

AWG28

e.g. Reichelt.de: AWG 28-40G 3M

18 1 3D printed case Rev. 3

19 4 C2.9x9.5H self tapping screws, DIN7981 (dia 2.9mm, length 9.5mm)

## Commodore PET Diagnostic: Diagnostic Clip Rev. 3

## Bill of Material Rev. 3.0

PETDiag_Clip_BOM_v3_0.xlsx

Drafted by Sven Petersen Page 1 of 1

20.07.2026 20:12
Doc.No.: 163-5-01-03.0


PETDiagClip_Testing.docx | | 20.07.2026 20:01
Drafted by Sven Petersen | Page 2 of 2 | Doc.-No.: 163-6-02-03

Figure 2: Test in CBM8032

## Test Execution

### Interference Test

First, the computer was started with the ribbon cable adapter with the ribbon cable only. The computer was operated over an hour. No crash was experienced. Next, the diagnostic box was connected to the said setup. The computer was used for several hours. No interference was found. The computer operated properly.

### Diagnostic Test

The User Port and Keyboard Dongles were connected. The Diagnostic Clip was switched to “active”.
The computer was switched on.
- The first page of the diagnostic was shown. All tests were performed properly (refer to module description)
- The switch was then toggled to “remove”.
- The actual diagnostic tests were repeatedly performed without error messages until the computer was switched off (refer to module description).

## Test Result

The Diagnostic Clip Rev.3, the adapter and the dongles are working properly.

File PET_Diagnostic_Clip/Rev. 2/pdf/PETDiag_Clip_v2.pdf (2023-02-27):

# Project Documentation

## Commodore PET/CBM80xx/40xx Diagnostic Clip

## Project number: 163

## Revision: 2

## Date: 01.01.2023


PETDiagClip_ModD.docx | | 27.02.2023 22:25
Drafted by Sven Petersen | Page 1 of 14 | Doc.-No.: 163-6-01-02

### Commodore PET/CBM80xx/40xx Diagnostic Clip Rev. 2

### Module Description

Table Of Contents

## 1. Introduction

The diagnostic clip is a diagnostic tool, which is originally issued by Commodore. It contains the diagnostic software, which has to fit to the board type, that is tested. For testing, it is connected to the 6502, switches off the ROMs on the mainboard and/or redirects the Kernal accesses to its built in EPROM.

The original hardware consists of:

Drafted by Sven Petersen | Page 2 of 14 | Doc.-No.: 163-6-01-02
- DIP40 test clip (3M is still producing this kind of clip – They are available from Mouser and Digikey: https://www.digikey.com/en/products/detail/3m/923743-40/12075, which is $94.07 in February 2023)
- the box with the EPROM/Test software)
- the keyboard feedback dongle
- user port feedback dongle

There is an extra box for each version of the software.

The goal of this development is to eliminate the need for an expensive DIP40 test clip and to merge the different box designs to one PCB. Further, shorting A13 and A14 to GND should be prevented.

The result is a 4 PCB solution:

- the clip box with a ribbon cable
- a ribbon cable adapter for the 6502
- a keyboard feed back
- a user port feed back

The EPROM in the clip box is fully connected to the 6502 µprocessor address and data bus. When connected (and configured properly), the test software is run after powering up the machine. The two main types of mainboards require different methods of making the test software appear in the system.

- CRTC machines, like the 8032, have a NOROM signal, which can switch off all ROMs on

the mainboard (except the character set) and the test software resides at $Fxxx instead of the Kernal. It comes with its own RESET vector @ $FFFC/D (it points to $F000, the start of the test software)
- Non CRTC machines, like the PET2001 or CBM30xx: the Kernal access is redirected to the option ROM address space $9xxx. This happens by (brutally) shorting the address signals A13 and A14 to GND – $F/1111BIN becomes a $9/1001BIN. The test software starts at $9800, the redirected reset vector is now at $9FFC/D and it points to $9800

Note: CRTC means <Cathode Ray Tube Controller. The first PETs had a video circuit, solely consisting
of TTL ICs and the Character ROM. This includes the first <dynamic PETs=, like the CBM 30xx. The
later machines had a controller chip (6545) as the heart of the video circuit. It can be configured for 40 column and 80 column machines and is a bit more flexible. The CBM 80xx and most CBM 40xx are CRTC machines.

## 2. Test procedure

### 2.1. Brief discription

The diagnostic hardware (clip/ribbon cable adapter, clip box, keyboard and user port dongles have to be connected before power up.

After power up, the diagnostic software is started. It consists or the first basic tests, which make sure, that the basic system is working:

- Printing the character set on the screen

### - Testing the <TV RAM= (screen memory)

- Testing the Zero Page
- Testing the stack
- Copying the actual test software into the RAM, starting at $0200. Jumping to that software
- Waiting for the clip to be removed

Drafted by Sven Petersen | Page 3 of 14 | Doc.-No.: 163-6-01-02

NOTE: A switch installed on JP5 allows to switch off NOROM , which is logically removing the clip EPROM from the system. As a non-CRTC machine the CBM3016 was tested.

The copied test software first waits for the clip to be removed by checking the (redirected) reset vector. If it does not point to $F000 or $9800 for a couple of seconds, it is assumed, that the clip is removed. Then testing is proceeded:

- Video Test
- Checksum Test (CRTC machines)
- Horizontal (video) Test
- Video RAM Test (CRTC machines)
- 32k RAM test
- ROM Test (shows checksum only)
- Refresh Test (dynamic RAM refresh)
- Keyboard Test
- 60Hz (non CRTC) or 50Hz (CRTC) IRQ (interrupt) test
- Timer 1 Test
- Timer 2 Test
- Cassette 1 Test
- Cassette 2 Test
- IEEE DIO Test
- IEEE Ctrl Test

This part of the test is cycling until the Reset switch is pressed or the computer is power down. The tests are described in chapter 7.2.2

### 2.2. Notes

The user port is used to monitor the video signals, SRQ and EOI from the IEEE Bus, the Tape write and read signals and the <Diagsens= and <Graphic= signal.

I would not consider this as a proper user port test.

The IEEE signals are fed back internally, there is no external feedback, so the driver chips are not tested.

The tape port TPWRITE signal on the user port us fed back to both TPREAD1 and TPREAD2. CASS SWITCH #1 and #2 are not tested, neither is CASS MOTOR #1 and #2.

The testing will stop on the first failed test.

## 3. Diagnostic Software


Drafted by Sven Petersen | Page 4 of 14 | Doc.-No.: 163-6-01-02

### 3.1. 80 col CRTC

The file name in the <Diagnostic Software= folder is <80_col_diagnostic_v1.1.bin=. It is suitable for 80 col 80xx and 40xx machines (with the 12= monitor).

Figure 1: 80_col_diagnostic_v1.1.bin - first page
After removing the clip, respectively switching it to <remove=, the test continues on the 2nd page.

Figure 2: 80_col_diagnostic_v1.1.bin - second page


Drafted by Sven Petersen | Page 5 of 14 | Doc.-No.: 163-6-01-02

### 3.2. 40 col CRTC

Since no such a computer is available, just the opening page can be shown on a 40 col. screen. A further test on a non CRTC machine (CBM3016) fails. The test itself passes on the CBM8032, but the output screen is not properly aligned.

Figure 3: 40_col_diagnostic_v2.0.bin - first page

Figure 4: 40_col_diagnostic_v2.0.bin - second page (on an 80 col machine)


Drafted by Sven Petersen | Page 6 of 14 | Doc.-No.: 163-6-01-02

### 3.3. 40 col non-CRTC

This test should work with all 40 column non-CRTC machines. The 2nd page is scrolling, so an upper and lower half of the looping test is shown.

Figure 5: 901447-30_diagnostic_320350g_$9000.bin - first page

Figure 6: 901447-30_diagnostic_320350g_$9000.bin - 2nd page (upper half)


Drafted by Sven Petersen | Page 7 of 14 | Doc.-No.: 163-6-01-02

Figure 7: 901447-30_diagnostic_320350g_$9000.bin - 2nd page (lower half)

## 4. Complete Diagnostic Clip Set

In Figure 8 all required PXCBs are shown. The short 40 pin ribbon cable is missing.

Figure 8: Diagnostic PCBs assembled


Drafted by Sven Petersen | Page 8 of 14 | Doc.-No.: 163-6-01-02

Figure 9: Diagnostic clip connected to the 6502 ribbon cable adapter (in the CBM8032)

## 5. Dimensions

Figure 10: Dimensions of the Diagnostic Clip PCB Rev. 0

Drafted by Sven Petersen | Page 9 of 14 | Doc.-No.: 163-6-01-02

## 6. Connectors and Jumpers

### 6.1. J1 – Connector to test clip/6502 Ribbon Cable Adapter

A 2x20 box connector, 2.54mm pitch

Signal Pin | Pin Signal
GND (6502, Pin 1) | 1 | 2 | RES
RDY | 3 | 4 | PHI2
PHI | 5 | 6 | S.O.
IRQ | 7 | 8 | PHI0
NOROM | 9 | 10 | n.c. (6502, Pin 36)
NMI | 11 | 12 | n.c. (6502, Pin 35)
SYNC | 13 | 14 | R/ W
5V | 15 | 16 | DB0
AB0 | 17 | 18 | DB1
AB1 | 19 | 20 | DB2
AB2 | 21 | 22 | DB3
AB3 | 23 | 24 | DB4
AB4 | 25 | 26 | DB5
AB5 | 27 | 28 | DB6
AB6 | 29 | 30 | DB7
AB7 | 31 | 32 | AB15
AB8 | 33 | 34 | AB14
AB9 | 35 | 36 | AB13
AB10 | 37 | 38 | AB12
AB11 | 39 | 40 | GND (6502, Pin 21)

### 6.2. Jumpers & Switches 6.2.1. JP5/SW4 – Switch for <Active « Remove=

The <Jumper= is not actually placed, but an external slide switch (at least SPST) is connected via short cables. ON means <active=, OFF means <remove=. Internally the mini slide Switch SW4 can
be installed instead of JP5, which is not the recommended solution.

### 6.2.2. JP6/SW3 – AB13 & AB14

This selects the CRTC/non CRTC mode

Signal Pin | Pin Signal
n.c. | 1 | 2 | AS14
AB13 | 3 | 4 | AB14
GND | 5 | 6 | GND

CRTC machines, like the 80xx or most 40xx: Jumper 1 – 3 & 2 – 4.

Non-CRTC machines, like the PET20xx or CBM 30xx: Jumper 3 – 5 & 4 – 6.

Internally the mini slide Switch SW3 can be installed instead of JP6, which is the recommended solution.

Drafted by Sven Petersen | Page 10 of 14 | Doc.-No.: 163-6-01-02

### 6.2.3. SW2 – The DIP Switch

The DIP-Switch serves for selecting the test software (one of 16 possible) from the EPROM (27C512) that can be run on the clip. The size of the test software is 4kByte, while the size of the EPROM is 64kByte. If it is desired to have a smaller EPROM, the highest (not required) address bits have to be HIGH and the DIP-switch can be smaller.

EPROM | SW | Address Bits | DIP-Switch
27C256 | 8x4k | A15 open/HIGH | position 1-3
27C128 | 4x4k | A15&A14 open/HIGH | position 1-2
27C64 | 2x4k | A15&A14&A13 open/HIGH | position 1

The OFF position of a switch means HIGH, the ON Position means LOW.

4 | 3 | 2 | 1 | A15..12 | 4k Slot | EPROM Offset
on | on | on | on | 0000 | 0 | $0000
on | on | on | off | 0001 | 1 | $1000
on | on | off | on | 0010 | 2 | $2000
on | on | off | off | 0011 | 3 | $3000
on | off | on | on | 0100 | 4 | $4000
on | off | on | off | 0101 | 5 | $5000
on | off | off | on | 0110 | 6 | $6000
on | off | off | off | 0111 | 7 | $7000
off | on | on | on | 1000 | 8 | $8000
off | on | on | off | 1001 | 9 | $9000
off | on | off | on | 1010 | 10 | $A000
off | on | off | off | 1011 | 11 | $B000
off | off | on | on | 1100 | 12 | $C000
off | off | on | off | 1101 | 13 | $D000
off | off | off | on | 1110 | 14 | $E000
off | off | off | off | 1111 | 15 | $F000

## 7. Resources

### 7.1. Websites

The information for creating this project, like the schematics of the original diagnostic clips and

### some test software was retrieved from André Fachat’s website:

- http://www.6502.org/users/andre/petindex/diag/index.html

Further test software and the connections of the keyboard and user port feedback was retrieved

### from Bo Zimmerman’s website:

- http://www.zimmers.net/anonftp/pub/cbm/firmware/computers/pet/other/index.html
- http://www.zimmers.net/anonftp/pub/cbm/schematics/computers/pet/diagnostics.txt

### 7.2. Commodore Training: 40xx/80xx Service Manual

Some further descriptions can be found in the (German) "Commodore Training_40xx_80xx_Service Manual" (https://www.retro-commodore.eu/2017/02/26/commodore-service-training-material-for-cbm-40xx80xx/) on Carsten's great retro-commodore.eu website .

Page 33ff:

Drafted by Sven Petersen | Page 11 of 14 | Doc.-No.: 163-6-01-02

### 7.2.1. DIAGNOSTIC BOX DESCRIPTION

"DIAGNOSTIC-BOX BESCHREIBUNG

Die Diagnostic-Box ist ein Testger‰t, mit dem die wichtigsten Komponenten auf der Logic-Platine der Zentraleinheiten getestet und ein hoher Prozentsatz der Fehler gefunden werden kann.

Die Tastatur selbst und das Video-Board wird nicht ¸berpr¸ft. Fŗ jede Zentraleinheit gibt es eine spezielle Diagnostic-Box.

Anschlufl und Starten des Testprogramms:

Zur Diagnostic-Box gehˆren zwei Diagnostic-Stecker, einer fŗ den User-Port und einer fŗ die Tastatur. An der Box befindet sich ein 40-poliges Flachbandkabel mit einem IC-Clip.

Dieser Clip wird auf den Prozessor gesteckt und die beiden Diagnostic-Stecker kommen an die entsprechenden Positionen

Wenn die rote LED leuchtet, kann das Diagnose-Programm durch drçken der roten Taste (Reset) gestartet werden.

Auf dem Bildschirm wird nun angezeigt welcher Test gerade l‰uft, ob er fehlerfrei durchl‰uft, oder was fŗ Fehler erkannt wurden. Wird ein Fehler erkannt, stoppt das Testprogramm. Treten keine Fehler auf, werden die Tests laufend wiederholt."

Translated to English:

"DIAGNOSTIC BOX DESCRIPTION

The Diagnostic-Box is a test device with which the most important components on the logic board of the central units are tested and a high percentage of errors can be found.

The keyboard itself and the video board are not checked. There is a special diagnostic box for each computer.

Connection and start of the test program:

The Diagnostic Box includes two diagnostic plugs, one for the User port and one for the keyboard. There is a 40-pin ribbon cable with an IC clip attached to the box.

This clip is put on the processor and the two diagnostic plugs are connected to the appropriate positions/connectors.

When the red LED lights up, the diagnostic program can be started by pressing the red button (Reset). The screen now shows which test is currently running and whether it is passed or failed, or what kind of errors were detected. If an error is detected, the test program stops. if there are no fails, the tests are repeated continuously."

[...]

### 7.2.2. Test description

"Testbeschreibung

Nach Bet‰tigung der Reset-Taste wird der CRT-Controller initialisiert und der CBM-Zeichensatz in den oberen Teil des Bildschirms geschrieben womit festgestellt wird ob es ¸berhaupt mĝlich ist Daten auf den Bildschirm zu schreiben.

Nun wird Zero-Page und Stack getestet. Treten hier Fehler auf wird entweder ein RAM als defekt angezeigt oder eine Adressleitung.

Drafted by Sven Petersen | Page 12 of 14 | Doc.-No.: 163-6-01-02

Eine genaue Erkennung des Fehlers ist aber in manchen F‰llen nicht mĝlich, sodafl zum Teil unrichtige Fehlermeldungen ausgegeben werden. Um den Fehler zu lokalisieren kann man die CAS-Leitungen an den RAMs vertauschen und den Test neu starten. Wird wieder eine Fehlermeldung ausgegeben, so liegt der Fehler wahrscheinlich nicht an den RAM', sondern an der Ansteuerung (Adressleitungen, Refresh, RAS, CAS, RAM R/W, MUX A).

Ist Zero-Page und Stack in Ordnung wird ein Testprogramm in den RAM-Bereich geschrieben und die Aufforderung REMOVE CLIP erscheint auf dem Bildschirm.

Wird nun die Diagnostic-Box vom Prozessor entfernt, werden von dem in der Zero-Page befindlichen Testprogramm die weiteren Teile des Systems getestet. Die ausgegebenen Fehlermeldungen sind im Allgemeinen zuverl‰ssig."

English:

"Test description

After pressing the reset button, the CRT controller is initialized and the CBM character set is displayed on the upper part of the screen, which determines whether it is even possible to write data on the screen.

Now the zero-page and stack are tested. If errors occur here, either a RAM is displayed as defective or an address line

In some cases, however, an exact detection of the error is not possible, so that in some cases incorrect error messages are output. To localize the error, you can swap the CAS lines on the RAM's and restart the test. If an error message is output again, the error is probably not due to the RAM, but to the control (address lines, refresh, RAS, CAS, RAM R/W, MUX A).

If the zero page and stack are OK, a test program is written to the RAM area and the REMOVE CLIP request appears the screen.

If the diagnostic box is now removed from the processor, the other parts of the system are tested by the test program in the zero page. The error messages issued are generally reliable."

CHKSM TEST: | Um zu ¸berpr¸fen, ob das Testprogramm richtig in die Zero-Page geladen wurde, wird eine Pr¸fsumme gebildet die 00 ergeben mufl.
VIDEO RAM TEST: | Es werden in jede Bildschirmadresse Daten geschrieben wieder gelesen und verglichen
32K RAM TEST: | Es wird der gesamte RAM-Speicher aufler Zero-Page und Stack getestet
ROM TEST: | Es werden Pr¸fsummen von jedem ROM gebildet (siehe Liste der Pr¸fsummen)
RFRSH TEST: | Es werden Daten in die RAMs geschrieben, eine Zeit lang gewartet und die Daten wieder ausgelesen. So wird ¸berpr¸ft, ob der Refresh in Ordnung ist.
KEYBOARD TEST: | Es wird die Funktion des Decoders und des PIA ¸berpr¸ft
50 HZ IRQ TEST: | Es wird getestet, ob von dem Signal Vert Drive ¸ber den PIA Interrupts erzeugt werden.
TMR1/2 TEST: | Es werden die beiden TIMER des VIA getestet
CASS1/2 TEST: | Es werden die beiden Cassetten-Ports getestet Beim Lesen werden Interrupts erzeugt (VIA, PIA)
IEEE Tests: | Es werden Daten und Steuersignale getestet. Die IEEE-Buffer werden mitgetestet

English:


Drafted by Sven Petersen | Page 13 of 14 | Doc.-No.: 163-6-01-02
CHKSM TEST: | In order to check whether the test program has been loaded correctly into the zero page, a checksum is formed which must result 00.
VIDEO RAM TEST: | Data is written to each screen address, read back and compared
32K RAM TEST: | The entire RAM memory except for the zero page and stack is tested
ROM TEST: | Checksums are generated from each ROM (see list of checksums)
RFRSH TEST: | Data is written to the RAMs, waited for a while and the data is read out again. This checks whether the refresh is OK
KEYBOARD TEST: | The function of the decoder and the PIA is checked
50 HZ IRQ TEST: | It is tested whether interrupts are generated by the signal Vert Drive via the PIA
TMR1 / 2 TEST: | The two TIMERS of the VIA are tested
CASS1 / 2 TEST: | The two cassette ports are tested When reading, interrupts are generated (VIA, PIA)
IEEE Tests: | Data and control signals are tested. The IEEE buffers are also tested

## 8. Annotations

### 8.1. 3D printed Case

The case of Rev. 0 is not suitable for any later version of the PCB than Rev.0. The PCBs rev. 1 and 2 require the case revision 1.

For the switch, two M2x5 screws are required. For the case, four C2.9 x 9.5 (DIN7981) self-tapping plastic screws are recommended.

### 8.2. Ribbon Cable

The ribbon cable is used to connect the Diagnostic Clip (Box) to the 6502 Ribbon Cable Adapter. Since it directly connects to the address and data bus of the 6502, this ribbon cable should not be too long. 10cm -15cm are tested and acceptable.

The strain reliefs should be installed properly, because it is expected to be connected and disconnected several times.

Figure 11: Ribbon cable

Drafted by Sven Petersen | Page 14 of 14 | Doc.-No.: 163-6-01-02

Building the ribbon cable is fairly simple. The ribbon cable itself is cut to length, both ends should be cut off perpendicular to the cable. The red wire marks pin one.

- Insert the cable into the IDC receptacle, be aware of the orientation (Figure 11, rec circles)
- Slightly squeeze the connector (to hold the ribbon cable)
- check, if the wires are placed exactly over the blades of the connector
- squeeze the connector with a vice (or a special IDC tool)
- bend the ribbon cable over the top of the connector and install the strain relief (Figure 11, top right).

### Note: IDC means <Insulation-Displacement Connector=. When the crimping is carried out

properly, the wires cold-weld to the blades, resulting in a gas tight connection. Refer to http://tech.guitarsite.de/cable_making.html#Ribbon%20Cables

## 9. Revision History

### 9.1. Rev. 0

- Prototype tested successfully with an 8032. Need for improvement.

### 9.2. Rev. 1 - DIP switch SW2 is 4 position now (no more <active=)

- Slide switch SW3 is new (CRTC « non CRTC)
- Slide switch SW4 is new (active « remove)

### 9.3. Rev. 2

- Support of the AND-gates on the ribbon cable adapter to set A13 and A14 low (for non CRTC mainboards).
- SW3 different circuit
- JP6 1x3 pin, different circuit
- Requires 6502 ribbon cable adapter Rev. 1 or later
- No more 3M DIP40 clip possible for non CRTC machines, since no grounding of A13 and A14










PETDiagClip_Testing.docx | | 27.02.2023 22:08
Drafted by Sven Petersen | Page 1 of 2 | Doc.-No.: 163-6-02-02

### Commodore PET/CBM80xx/40xx Diagnostic Clip Rev. 2

### Testing

## Test Setup

The tests were conducted with the following setup:

- Diagnostic Clip Rev. 2
- 6502 Ribbon Cable Adapter Rev. 1
- Ribbon Cable (10 cm and 15 cm)
- User Port Dongle Rev. 0
- Keyboard Dongle Rev. 0
- Commodore CBM8032
- Commodore CBM3016

The CBM8032 was tested with the software <80_col_diagnostic_v1.1.bin=

The CBM3016 was tested with the software <901447-30_diagnostic_320350g_$9000.bin=

The software <40_col_diagnostic_v2.0.bin= was partly tested with the CBM3016 and with the CBM8032.

The 6502 was inserted into the ribbon cable adapter, which then was installed in the CPU socket of the respective computer. The ribbon cable was connected to the ribbon cable adapter.

Later, the diagnostic box was connected to the ribbon cable, the keyboard and the user port dongle were connected to the respective connector of the main board. The IEEE-488 interface was open, the cassette port was not connected to a Datassette.

Figure 1: Testing the Diagnostic Clip in the CBM 3016


PETDiagClip_Testing.docx | | 27.02.2023 22:08
Drafted by Sven Petersen | Page 2 of 2 | Doc.-No.: 163-6-02-02

Figure 2: Test in CBM8032

## Test Execution

### Interference Test

First, the computer was started with the ribbon cable adapter with the ribbon cable only. The computer was operated over an hour. No crash was experienced. Next, the diagnostic box was connected to the said setup. The computer was used for several hours. No interference was found. The computer operated properly.

### Diagnostic Test

The User Port and Keyboard Dongles were connected. The Diagnostic Clip was switched to <active=. The computer was switched on.

- The first page of the diagnostic was shown. All tests were performed properly (refer to module description)
- The switch was then toggled to <remove=.
- The actual diagnostic tests were repeatedly performed without error messages until the computer was switched off (refer to module description).

## Test Result

The Diagnostic Clip, the adapter and the dongles are working properly.

Pos. Qty Value Footprint Ref.-No. Comment

1 1 163-2-01-02 2 Layer PCB Rev. 2 2 layer, Cu 35µ, HASL, 77.0mm x 47.0mm, 1.6mm FR4

2 1 external DPDT switch wired

up

1X02 JP5 Reichelt.de: T217 or AliExpress SS22F25-G7 + 6cm

AWG24 cable

3 1 2x20 box header, 2.54mm

pitch

2X20WV J1 2x20, box pin header or standard pin header, e.g.

reichelt.de WSL 40G

4 2 100n/50V C-2,5 C1, C2 cer. cap, 2.5mm pitch

5 5 10k R-10 R1, R2, R3, R4, R6 1/4W, 5%

6 1 1N5908 DO-201 D1 5V TVS diode. ST Micro. E.g. Reichelt: 1N 5908, tme.eu:

1N5908

7 1 330R R-10 R5 1/4W, 5%

8 1 3mm/gn 3MM LD1 standard LED 3mm/green + 5mm distance holder for 3mm

LED

9 1 74LS20 DIL-14 IC2 e.G. RENESAS, e.G. Reichelt LS 20

10 1 DIPSW-04 DIPSW-04V-

COMBI SW2 Standard DIP-Switch with 4 switches (switch side facing up) The DIP-Switch can be replaced with a 2 switch DIP Switch
and hardwire switch 3 and 4. Reichelt NT 04 or NT 02

11 1 mini slide switch, 2.54mm,

DPDT, through hole

DPDT_9MM SW3 Ali Express, ebay, Amazon, search term "MSS22D18"

12 1 mini slide switch, 2.54mm,

DPDT, through hole

DPDT_9MM SW4 do not place

13 1 JTP-1130 JTP-1130 SW1 standard TACT switch 6mm x 6mm, height = 13mm

14 1 JUMPER1x3 1X03 JP6 do not place

15 1 M27C512-DIP28 DIL28-6 IC1 M27C512 EPROM (or M27C256 or M27C128)

16 1 DIP 28 socket, low profile (IC1) e.g. Reichelt.de: GS 28P

17 1 2x20 pin IDC receptacle,

pitch 2.54mm

e.g. Reichelt.de: PFL 40

18 15 cm ribbon cable, 40p,

AWG28

e.g. Reichelt.de: AWG 28-40G 3M

## Commodore PET Diagnostic: Diagnostic Clip Rev. 2

## Bill of Material Rev. 2.0

PETDiag_Clip_BOM_v2_0.xlsx

Drafted by Sven Petersen Page 1 of 1

27.02.2023 22:27
Doc.No.: 163-5-01-02.0

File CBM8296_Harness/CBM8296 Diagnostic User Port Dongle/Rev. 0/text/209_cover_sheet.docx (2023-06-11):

Project Documentation

Commodore CBM8296 Diagnostic: User Port Dongle

Project number: 209

Revision: 0

Date: 16.05.2023


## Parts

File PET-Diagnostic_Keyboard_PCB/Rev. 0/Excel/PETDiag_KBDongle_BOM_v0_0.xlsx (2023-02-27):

Commodore PET Diagnostic Clip: Keyboard Dongle Rev. 0
Bill of Material Rev. 0.0
Pos. | Qty | Value | Footprint | Ref.-No. | Comment
1 | 1 | 166-2-01-00 | 2 Layer | PCB Rev. 0 | 2 layer, Cu 35µ, HASL, 53.0mm x 14.0mm, 1.6mm FR4
2 | 4 | 1N4148 | DO-35 | D1, D2, D3, D4 | Diode 1N4148
3 | 1 | BL1-85AXX-20U | BL1-85AXX-20U | J1 | e.g. MPE Garry, Reichelt BL 1x20W8 2,54

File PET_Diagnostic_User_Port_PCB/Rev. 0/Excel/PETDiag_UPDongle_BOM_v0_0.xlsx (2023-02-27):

Commodore PET Diagnostic Clip: User Port Dongle Rev. 0
Bill of Material Rev. 0.0
Pos. | Qty | Value | Footprint | Ref.-No. | Comment
1 | 1 | 165-2-01-00 | 2 Layer | PCB Rev. 0 | 2 layer, Cu 35µ, HASL, 54.0mm x 20.0mm, 1.6mm FR4
2 | 1 | 2x12, 3.96mm pitch | USERPORT | J1 | edge connector, C64 user port, Ali Express: Series 805

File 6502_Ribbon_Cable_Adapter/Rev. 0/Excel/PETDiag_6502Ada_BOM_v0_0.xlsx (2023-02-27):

Commodore PET Diagnostic Clip: 6502 Ribbon Cable Adapter Rev. 0
Bill of Material Rev. 0.0
Pos. | Qty | Value | Footprint | Ref.-No. | Comment
1 | 1 | 162-2-01-00 | 2 Layer | PCB Rev. 0 | 2 layer, Cu 35µ, HASL, 58.8mm x 32.0mm, 1.6mm FR4
2 | 1 | 2x20 box header, 2.54mm pitch | 2X20WV | J1 | 2x20, box pin header or standard pin header, e.g. reichelt.de WSL 40G
3 | 1 | 330R | R-10 | R1 | 1/4W, 5%
4 | 1 | 3mm/gn | 3MM | LD1 | standard LED 3mm/green
5 | 1 | 6502PINS | DIL40_PINS_SS | IC2 | Precision round pin header, e.G. bkl-electronic.de Art.-Nr. 10120540, Reichelt BKL 10120540
6 | 1 | DIP40 socket | GS40P | IC1 | Socket for 6502

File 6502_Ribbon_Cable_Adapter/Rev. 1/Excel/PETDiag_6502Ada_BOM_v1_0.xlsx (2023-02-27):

Commodore PET Diagnostic Clip: 6502 Ribbon Cable Adapter Rev. 1
Bill of Material Rev. 1.0
Pos. | Qty | Value | Footprint | Ref.-No. | Comment
1 | 1 | 162-2-01-01 | 2 Layer | PCB Rev. 1 | 2 layer, Cu 35µ, HASL, 61.0mm x 32.0mm, 1.6mm FR4
2 | 1 | 2x20 box header, 2.54mm pitch | 2X20WV | J1 | 2x20, box pin header or standard pin header, e.g. reichelt.de WSL 40G
3 | 1 | 330R | 0805 | R1 | SMD, 1/8W, 5%
4 | 1 | 3mm/gn | 3MM | LD1 | standard LED 3mm/green
5 | 1 | 6502PINS | DIL40_PINS_SS | IC2 | Precision round pin header, e.G. bkl-electronic.de Art.-Nr. 10120540, Reichelt BKL 10120540
6 | 1 | DIP40 socket | GS40P | IC1 | Socket for 6502
7 | 1 | 10k | 0805 | R2 | SMD, 1/8W, 5%
8 | 1 | 100n | 0805 | C1 | SMD
9 | 1 | 74LS08D | SO-14 | IC3 | SMD IC, e.g. TI
10 | 1 | mini slide switch, 2.54mm, DPDT, through hole |  | SW1 | Ali Express, ebay, Amazon, search term "MSS22D18", see module description
 |  | Rev. History
 |  | Rev. 1
Pos | 3 | now 0805
Pos | 7 | new
Pos | 8 | new
Pos | 9 | new
Pos | 10 | new

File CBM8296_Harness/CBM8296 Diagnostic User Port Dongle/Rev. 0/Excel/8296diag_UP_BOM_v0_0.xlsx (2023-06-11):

Commodore CBM8296 Diagnostic: User Port Dongle Rev. 0
Bill of Material Rev. 0.0
Pos. | Qty | Value | Footprint | Ref.-No. | Comment
1 | 1 | 209-2-01-00 | 2 Layer | PCB Rev. 0 | 2 layer, Cu 35µ, HASL, 54.0mm x 20.0mm, 1.6mm FR4
2 | 1 | box connector, 2x5, 2.54mm | 2X05WV | J2 | e.g. Reichelt WSL 10G
3 | 1 | 2x12, 3.96mm pitch | USERPORT | J1 | edge connector, C64 user port, Ali Express: "Series 805"
4 | 2 | 10-pin IDC socket with strain relief |  | cable drawing 209-3-01-00 | e.g. Reichelt PFL 10
5 | 43cm | ribbon cable |  | cable drawing 209-3-01-00 | ribbon cable, 10 wires, AWG28, 1.27mm pitch

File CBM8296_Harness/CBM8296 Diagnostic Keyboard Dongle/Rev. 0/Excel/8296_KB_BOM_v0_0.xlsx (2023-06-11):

Commodore CBM8296 Diagnostic: Keyboard Dongle Rev. 0
Bill of Material Rev. 0.0
Pos. | Qty | Value | Footprint | Ref.-No. | Comment
1 | 1 | 212-2-01-00 | 2 Layer | PCB Rev. 0 | 2 layer, Cu 35µ, HASL, 53.0 x 25.0, 1.6mm FR4
2 | 1 | D-Sub 25 male, 90°, PCB, European | D25M90CLEU | J1 | e.g. Reichelt.de D-SUB ST 25EU

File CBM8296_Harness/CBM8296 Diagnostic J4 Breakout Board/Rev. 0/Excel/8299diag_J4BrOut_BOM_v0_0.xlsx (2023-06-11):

Commodore CBM8296 Diagnostic: J4 Breakout Board Rev. 0
Bill of Material Rev. 0.0
Pos. | Qty | Value | Footprint | Ref.-No. | Comment
1 | 1 | 210-2-01-00 | 2 Layer | PCB Rev. 0 | 2 layer, Cu 35µ, HASL, 74.0 x 32.0, 1.6mm FR4
2 | 1 | box connector, 2x5, 2.54mm | 2X05WV | J1 | e.g. Reichelt WSL 10G
3 | 1 | pin header, 1 pin | 1X01 | TP1 | optional ground pin for debugging, e.g. Distrelec 300-93-642 (RND 205-00622)
4 | 1 | 2x25 female, pitch 2.54mm | 2x25 female | J4 | female socket connector for 0.65sq pins, 2x25 pins, pitch 2.54mm. E.g. MPE 094-2-050, e.g. Reichelt.de MPE 094-2-050

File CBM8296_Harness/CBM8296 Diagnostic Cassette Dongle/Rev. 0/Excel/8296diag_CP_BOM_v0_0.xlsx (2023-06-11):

Commodore CBM8296 Diagnostic: Cassette Dongle Rev. 0
Bill of Material Rev. 0.0
Pos. | Qty | Value | Footprint | Ref.-No. | Comment
1 | 1 | 211-2-01-00 | 2 Layer | PCB Rev. 0 | 2 layer, Cu 35µ, HASL, 30.0mm x 21.0mm, 1.6mm FR4
2 | 1 | 47R | R-10 | R1 | 1/4 Watt, 5%
3 | 1 | 51R | R-10 | R2 | 1/4 Watt, 5%
4 | 1 | 2x6, 3.96mm pitch | TAPEPORT | J1 | edge connector, C64 cassette port. AliExpress: "Series 805"

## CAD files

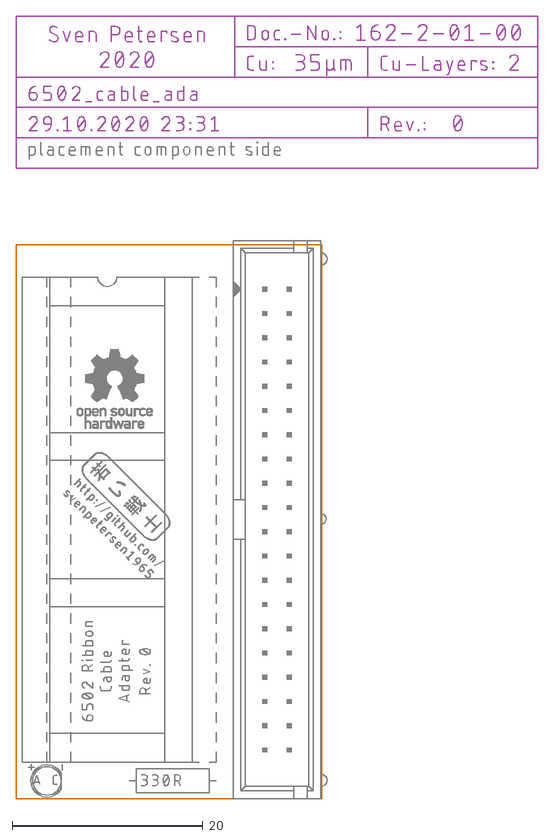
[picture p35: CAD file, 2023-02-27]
6502_Ribbon_Cable_Adapter/Rev. 0/dxf/6502_cable_ada.dxf
54.6 x 81.9

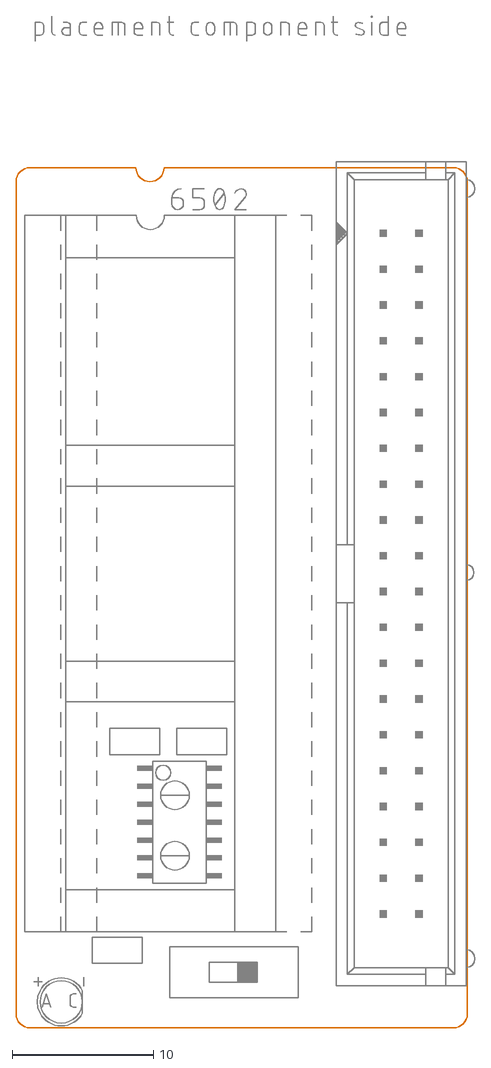
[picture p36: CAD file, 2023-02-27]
6502_Ribbon_Cable_Adapter/Rev. 1/dxf/6502_cable_ada.dxf
32.5 x 71.7

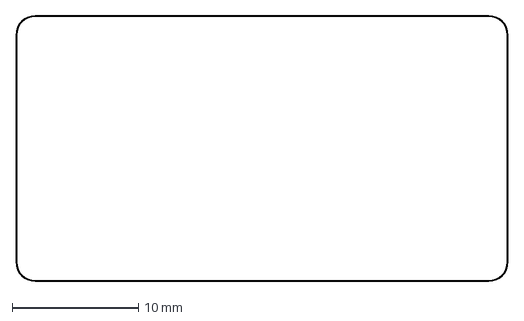
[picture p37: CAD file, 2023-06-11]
CBM8296_Harness/CBM8296 Diagnostic Cassette Dongle/3D printed case/Label/outline.dxf
39.0 x 21.0 mm

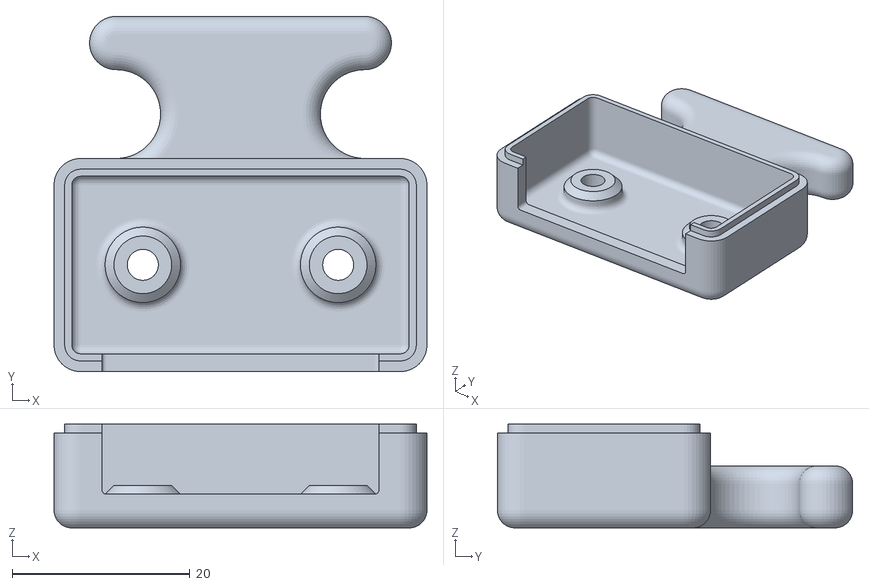
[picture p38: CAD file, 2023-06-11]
CBM8296_Harness/CBM8296 Diagnostic Cassette Dongle/3D printed case/Rev. 0/STL/8296_CP_bottom_shell.stl
42.0 x 40.0 x 11.7

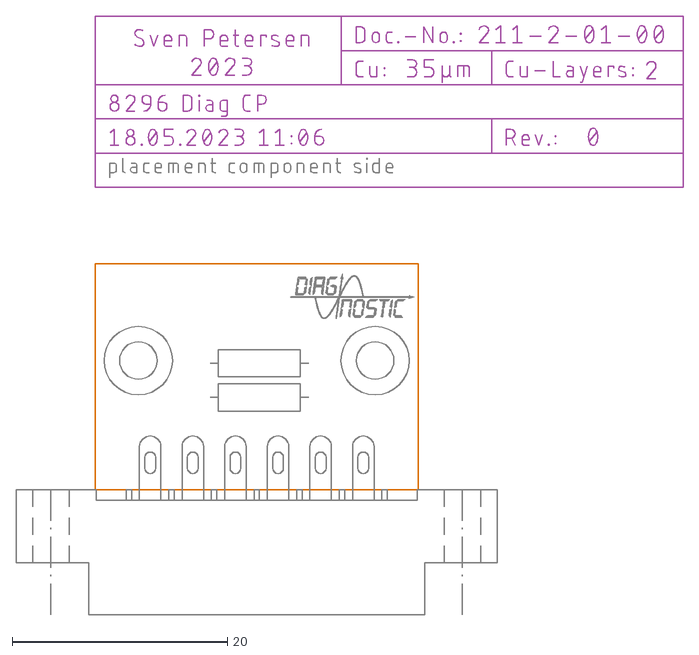
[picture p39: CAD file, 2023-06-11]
CBM8296_Harness/CBM8296 Diagnostic Cassette Dongle/Rev. 0/dxf/8296 Diag CP.dxf
62.0 x 55.6

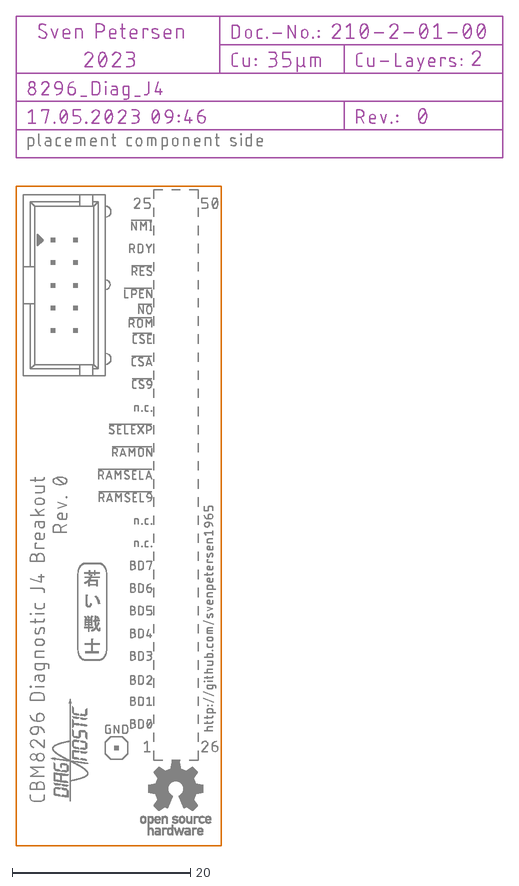
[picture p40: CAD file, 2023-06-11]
CBM8296_Harness/CBM8296 Diagnostic J4 Breakout Board/Rev. 0/dxf/8296_Diag_J4.dxf
54.6 x 93.0

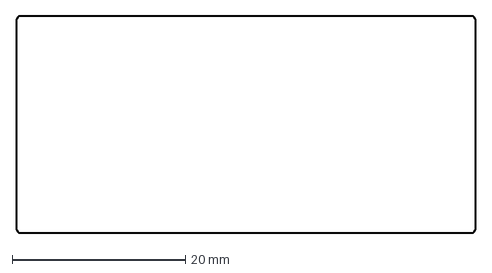
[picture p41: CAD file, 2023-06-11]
CBM8296_Harness/CBM8296 Diagnostic Keyboard Dongle/3D printed case/Label/Outline.dxf
53.0 x 25.0 mm

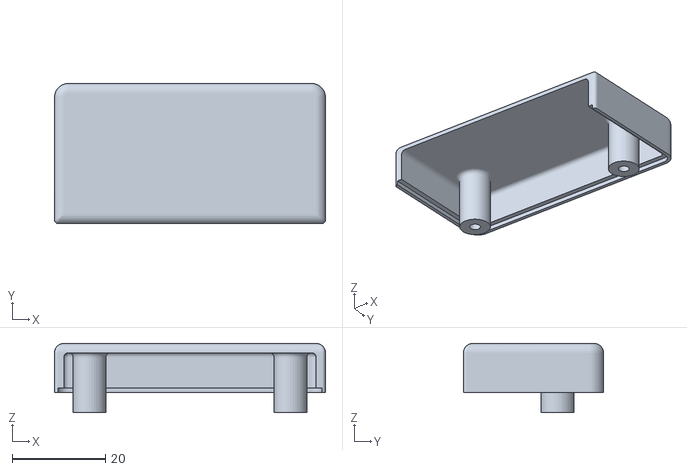
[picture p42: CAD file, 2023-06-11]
CBM8296_Harness/CBM8296 Diagnostic Keyboard Dongle/3D printed case/Rev. 0/STL/8296KB_top_shell.stl
58.0 x 30.0 x 14.8

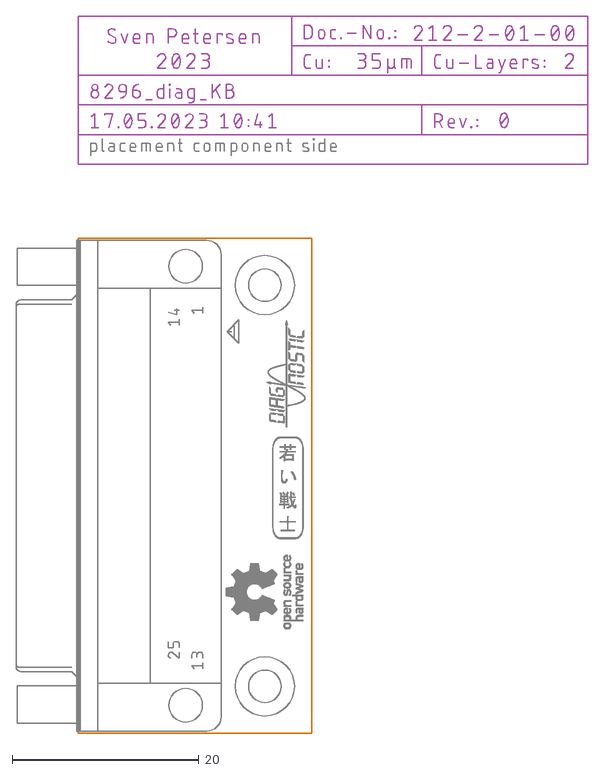
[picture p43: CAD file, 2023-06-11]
CBM8296_Harness/CBM8296 Diagnostic Keyboard Dongle/Rev. 0/dxf/8296_diag_KB.dxf
61.3 x 76.8

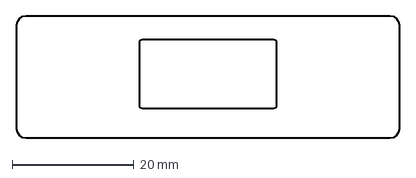
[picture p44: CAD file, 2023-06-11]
CBM8296_Harness/CBM8296 Diagnostic User Port Dongle/3D printed case/Label/Outline.dxf
63.0 x 20.0 mm

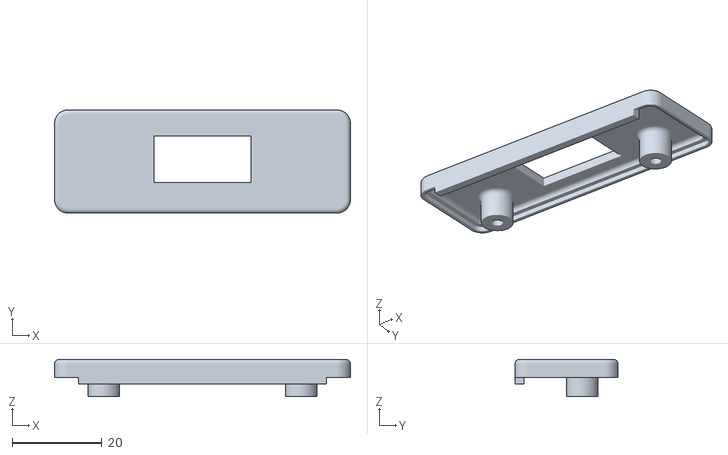
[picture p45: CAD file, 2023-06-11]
CBM8296_Harness/CBM8296 Diagnostic User Port Dongle/3D printed case/Rev. 0/STL/8286UP_top_shell.stl
66.0 x 23.0 x 8.30

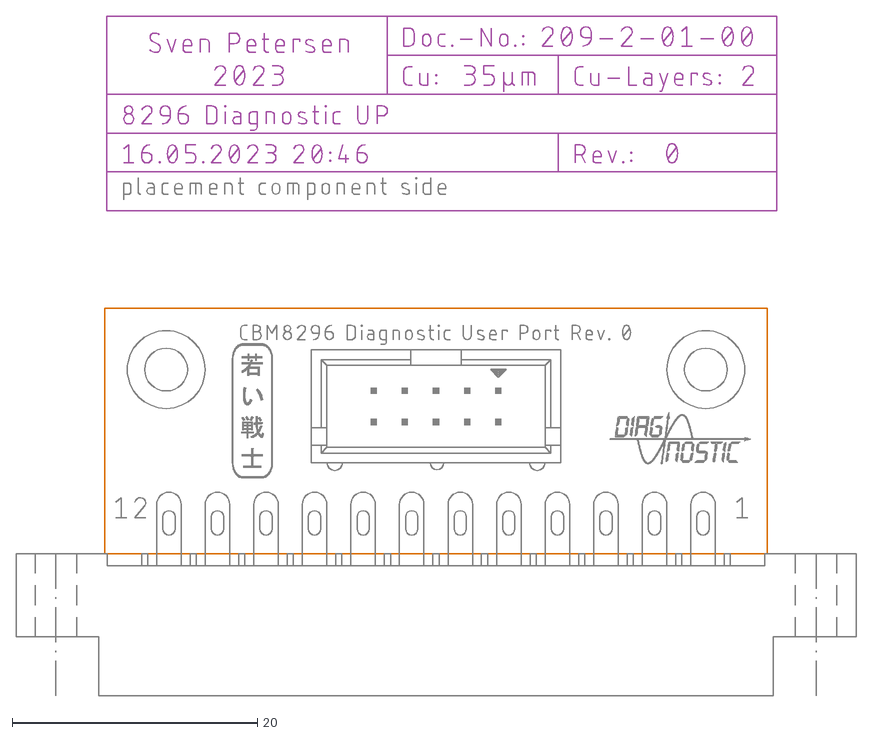
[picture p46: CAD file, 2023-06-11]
CBM8296_Harness/CBM8296 Diagnostic User Port Dongle/Rev. 0/dxf/8296 Diagnostic UP.dxf
68.5 x 55.4

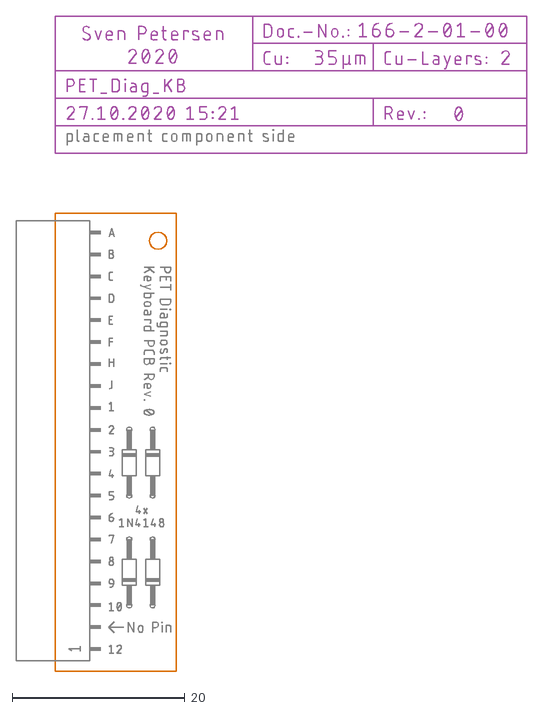
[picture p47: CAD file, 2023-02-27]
PET-Diagnostic_Keyboard_PCB/Rev. 0/dxf/PET_Diag_KB.dxf
59.1 x 75.9

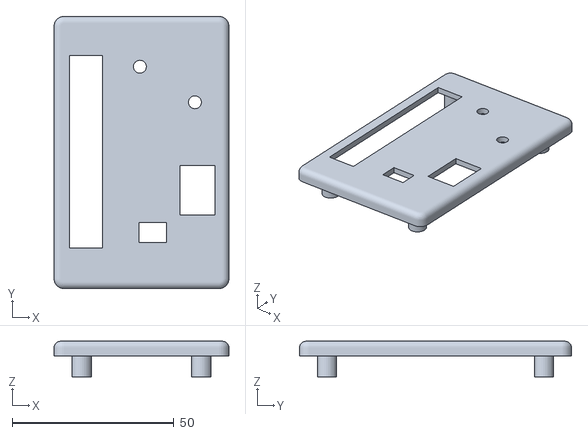
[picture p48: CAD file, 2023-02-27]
PET_Diagnostic_Clip/case/Rev. 0/stl/PETDiag_Clip_top_shell.stl
54.0 x 84.0 x 11.0

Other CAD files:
PET_Diagnostic_Clip/case/Rev. 1/stl/Diag_clip_top_shell.stl
PET_Diagnostic_Clip/case/Rev. 3/stl/clip_bottom_shell.stl
PET_Diagnostic_Clip/Rev. 0/dxf/PET_Diag_Clip.dxf
PET_Diagnostic_Clip/Rev. 1/dxf/PET_Diag_Clip.dxf
CBM8296_Harness/CBM8296 Diagnostic Cassette Dongle/3D printed case/Rev. 0/Fusion 360/CBM8296_CP_Dongle v1.f3d
CBM8296_Harness/CBM8296 Diagnostic Cassette Dongle/3D printed case/Rev. 0/STL/8296_CP_top_shell.stl
CBM8296_Harness/CBM8296 Diagnostic Keyboard Dongle/3D printed case/Rev. 0/Fusion 360/CBM8296_KB_Dongle v11.f3d
CBM8296_Harness/CBM8296 Diagnostic Keyboard Dongle/3D printed case/Rev. 0/STL/8296KB_bottom_shell.stl
CBM8296_Harness/CBM8296 Diagnostic User Port Dongle/3D printed case/Rev. 0/Fusion 360/CBM8296_UP_Dongle v2.f3d
CBM8296_Harness/CBM8296 Diagnostic User Port Dongle/3D printed case/Rev. 0/STL/8296UP_bottom_shell.stl
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

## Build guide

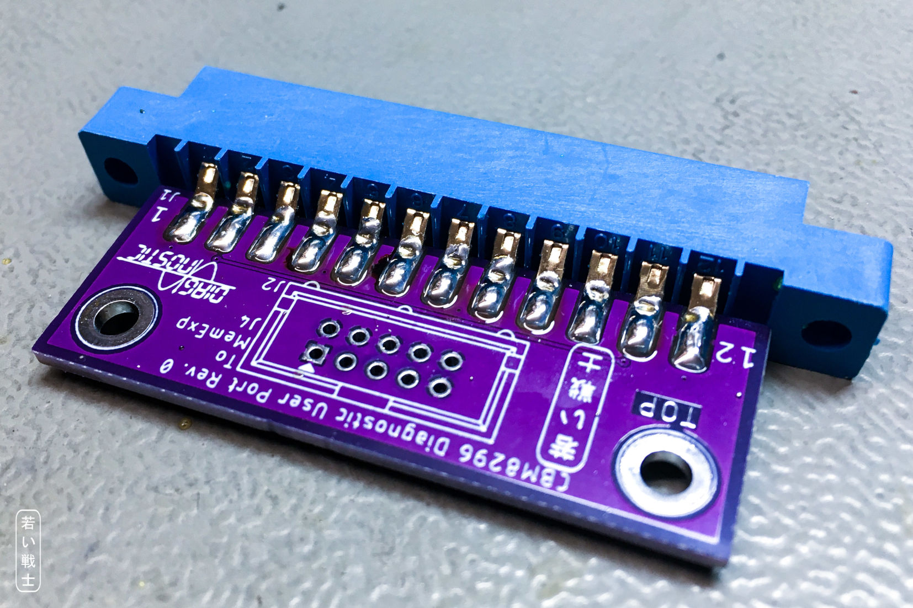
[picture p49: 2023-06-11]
CBM8296_Harness/CBM8296 Diagnostic User Port Dongle/Rev. 0/pictures/5116_-_8296UP_TOP_soldered.JPG

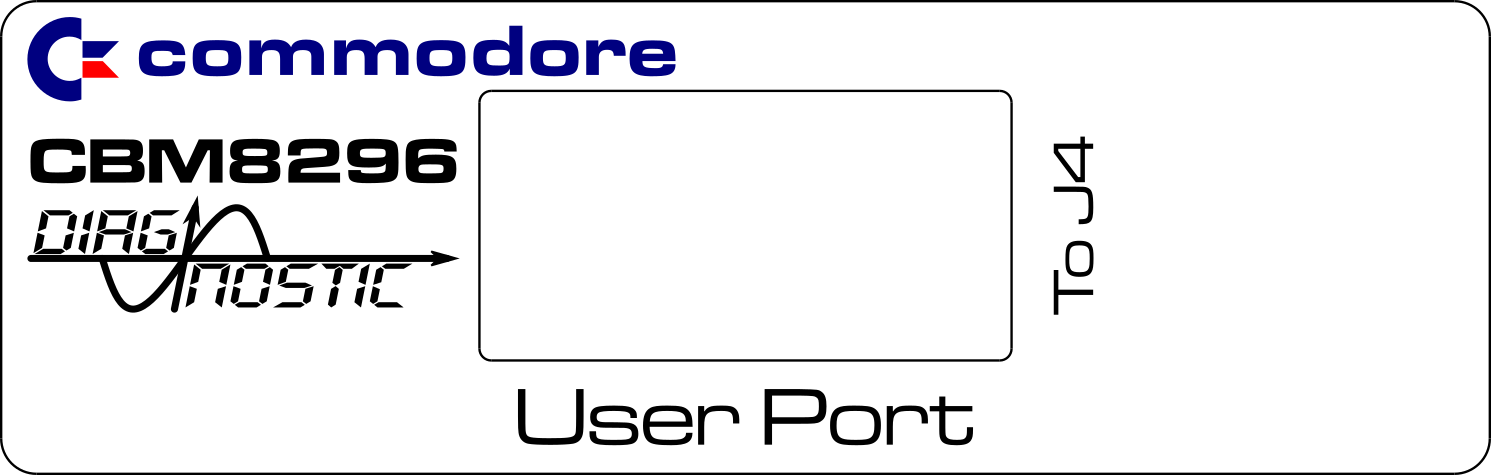
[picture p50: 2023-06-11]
CBM8296_Harness/CBM8296 Diagnostic User Port Dongle/3D printed case/Label/8296UP_label.png

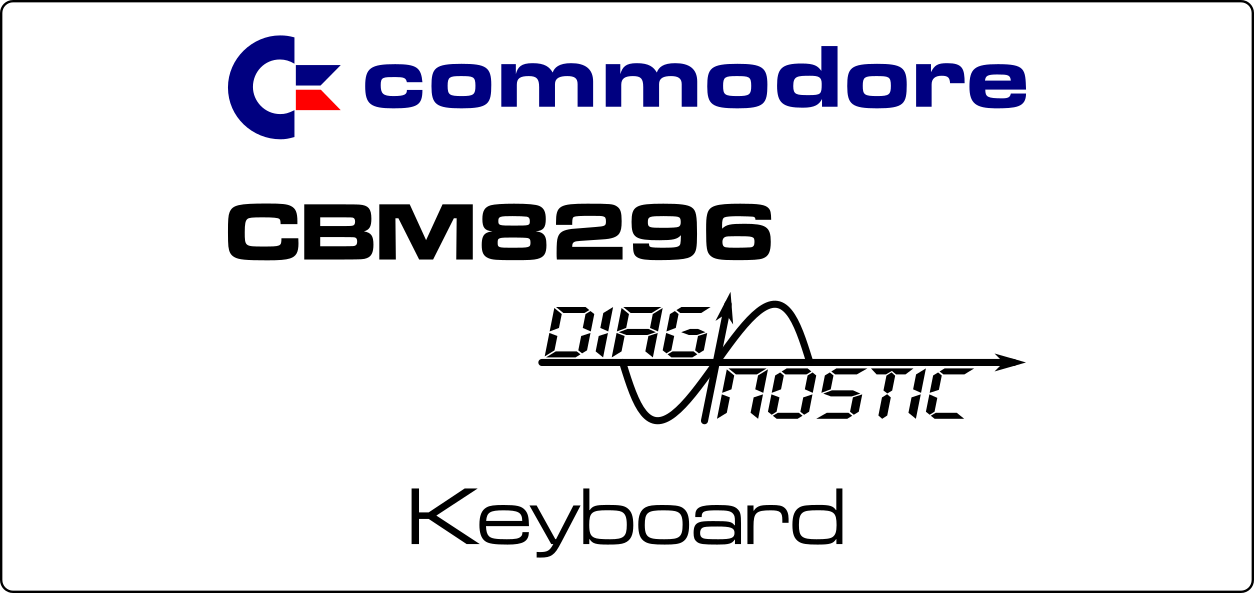
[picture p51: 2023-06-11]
CBM8296_Harness/CBM8296 Diagnostic Keyboard Dongle/3D printed case/Label/8296KB_label.png

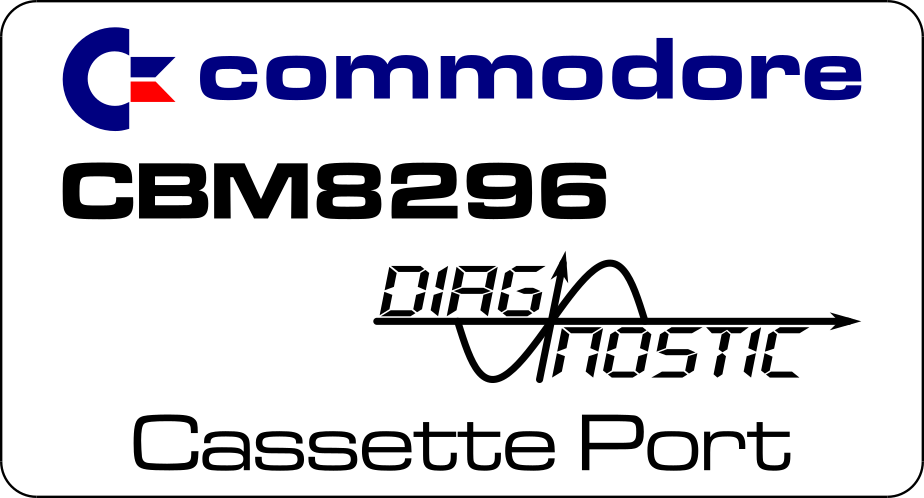
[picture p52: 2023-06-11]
CBM8296_Harness/CBM8296 Diagnostic Cassette Dongle/3D printed case/Label/8296CP_label.png

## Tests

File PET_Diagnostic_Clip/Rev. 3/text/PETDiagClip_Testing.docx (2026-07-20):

Commodore PET/CBM80xx/40xx Diagnostic Clip Rev. 3

Testing

# Test Setup

The tests were conducted with the following setup:

- Diagnostic Clip Rev. 3
- 6502 Ribbon Cable Adapter Rev. 1
- Ribbon Cable (10 cm and 15 cm)
- User Port Dongle Rev. 0
- Keyboard Dongle Rev. 0
- Commodore CBM8032
- Commodore CBM3016

The CBM8032 was tested with the software “80_col_diagnostic_v1.1.bin”

The CBM3016 was tested with the software “901447-30_diagnostic_320350g_$9000.bin”

The software “40_col_diagnostic_v2.0.bin” was partly tested with the CBM3016 and with the CBM8032.

The 6502 was inserted into the ribbon cable adapter, which then was installed in the CPU socket of the respective computer. The ribbon cable was connected to the ribbon cable adapter.

Later, the diagnostic box was connected to the ribbon cable, the keyboard and the user port dongle were connected to the respective connector of the main board. The IEEE-488 interface was open, the cassette port was not connected to a Datassette.

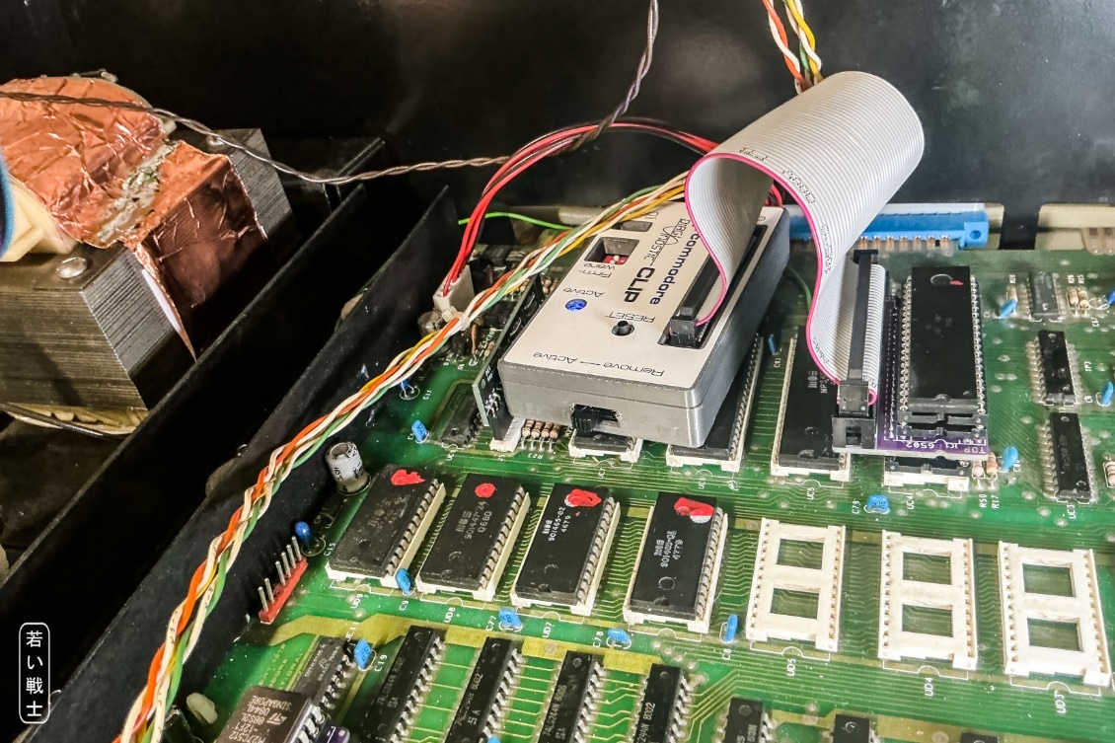
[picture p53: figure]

Figure 1: Testing the Diagnostic Clip (v2) in the CBM 3016

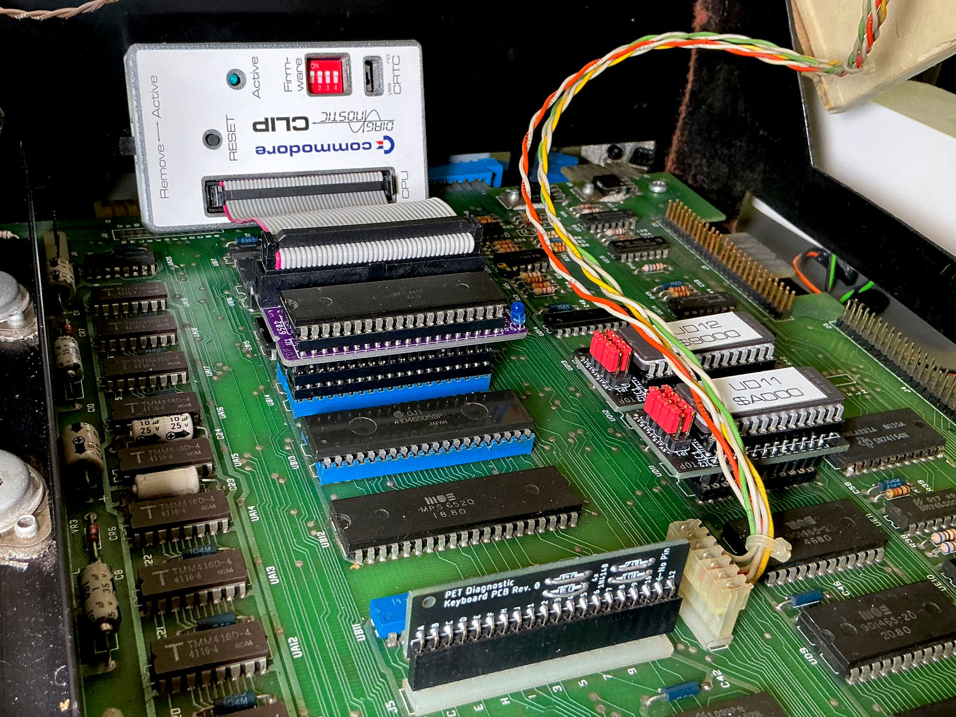
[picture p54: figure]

Figure 2: Test in CBM8032

# Test Execution

## Interference Test

First, the computer was started with the ribbon cable adapter with the ribbon cable only. The computer was operated over an hour. No crash was experienced. Next, the diagnostic box was connected to the said setup. The computer was used for several hours. No interference was found. The computer operated properly.

## Diagnostic Test

The User Port and Keyboard Dongles were connected. The Diagnostic Clip was switched to “active”. The computer was switched on.

- The first page of the diagnostic was shown. All tests were performed properly (refer to module description)
- The switch was then toggled to “remove”.
- The actual diagnostic tests were repeatedly performed without error messages until the computer was switched off (refer to module description).

# Test Result

The Diagnostic Clip Rev.3, the adapter and the dongles are working properly.

PETDiagClip_Testing.docx 20.07.2026 20:01 Drafted by Sven Petersen Page 1 of 2 Doc.-No.: 163-6-02-03

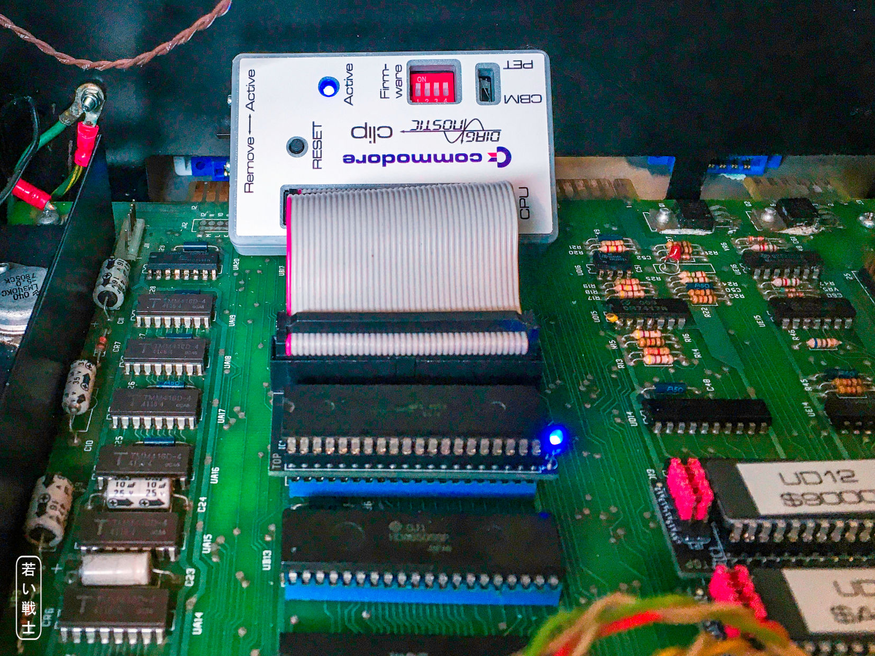
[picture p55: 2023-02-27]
PET_Diagnostic_Clip/Rev. 1/Pictures/0729_-_test_clip_rev1_8032.JPG

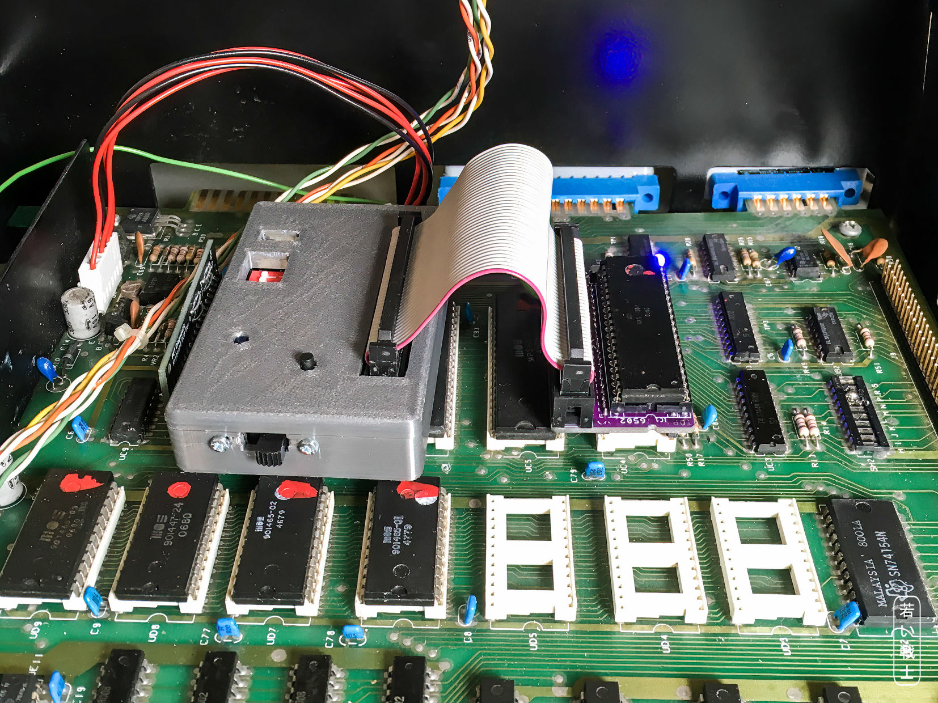
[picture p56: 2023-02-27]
PET_Diagnostic_Clip/Rev. 2/Pictures/3808_-_test_in_3016.JPG

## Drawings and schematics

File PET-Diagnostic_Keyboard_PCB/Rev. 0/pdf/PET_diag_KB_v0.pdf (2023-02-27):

# Project Documentation

## Commodore PET/CBM80xx/40xx Diagnostic Keyboard PCB

## Project number: 166

## Revision: 0

## Date: 27.10.2020

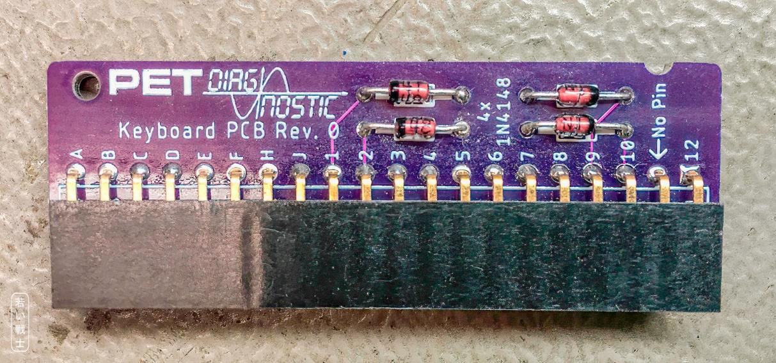
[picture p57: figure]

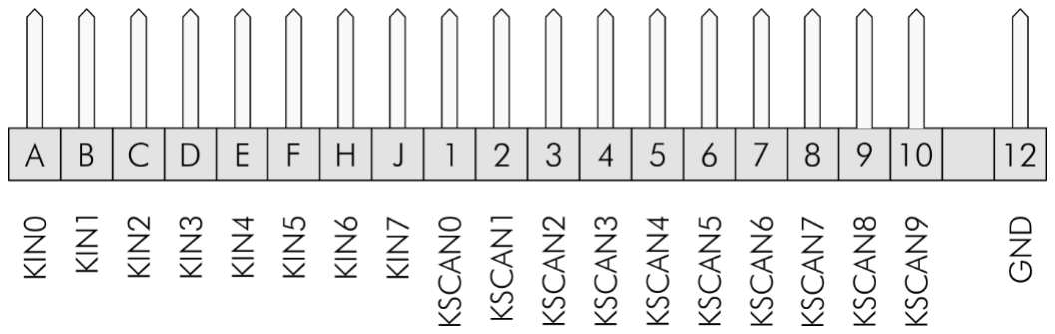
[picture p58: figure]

DiagClipKB_ModD.docx | | 26.02.2023 18:50
Drafted by Sven Petersen | Page 1 of 2 | Doc.-No.: 166-6-01-00

### Commodore PET/CBM80xx/40xx Diagnostic Keyboard PCB Rev. 0

### Module Description

## Introduction

The Keyboard PCB is part of the Diagnostic Clip project. Originally, it was made with a connector and wires, but since PCBs got cheap and provide interconnects very reproduceable with a low failure rate, it is a very simple board design.

Figure 1: Pinout of the keyboard connector

KSCANx are the open collector outputs of a 74LS145 BCD to Decimal Decoder. So, it is not critical to connect more than one KeyScan Signal, nevertheless, the keyboard PCB provides diodes for a wired-AND connection, in case the slightly rare 74LS145 was replaced with another IC, that does not provide open collector outputs. The diodes could be replaced by a wire bridge.

Pins | Connected Signals
A-1-9 | KIN0 - KeyScan0 - KeyScan8
B-2-10 KIN1 - KeyScan1 - KeyScan9
C-3 | KIN2 - KeyScan2
D-4 | KIN3 - KeyScan3
E-5 | KIN4 - KeyScan4
F-6 | KIN5 - KeyScan5
H-7 | KIN6 - KeyScan6
J-8 | KIN7 - KeyScan7

Figure 2: Dimensions of the Keyboard PCB

DiagClipKB_ModD.docx | | 26.02.2023 18:50
Drafted by Sven Petersen | Page 2 of 2 | Doc.-No.: 166-6-01-00

## Revision History

### Rev. 0

- Fully functional prototype

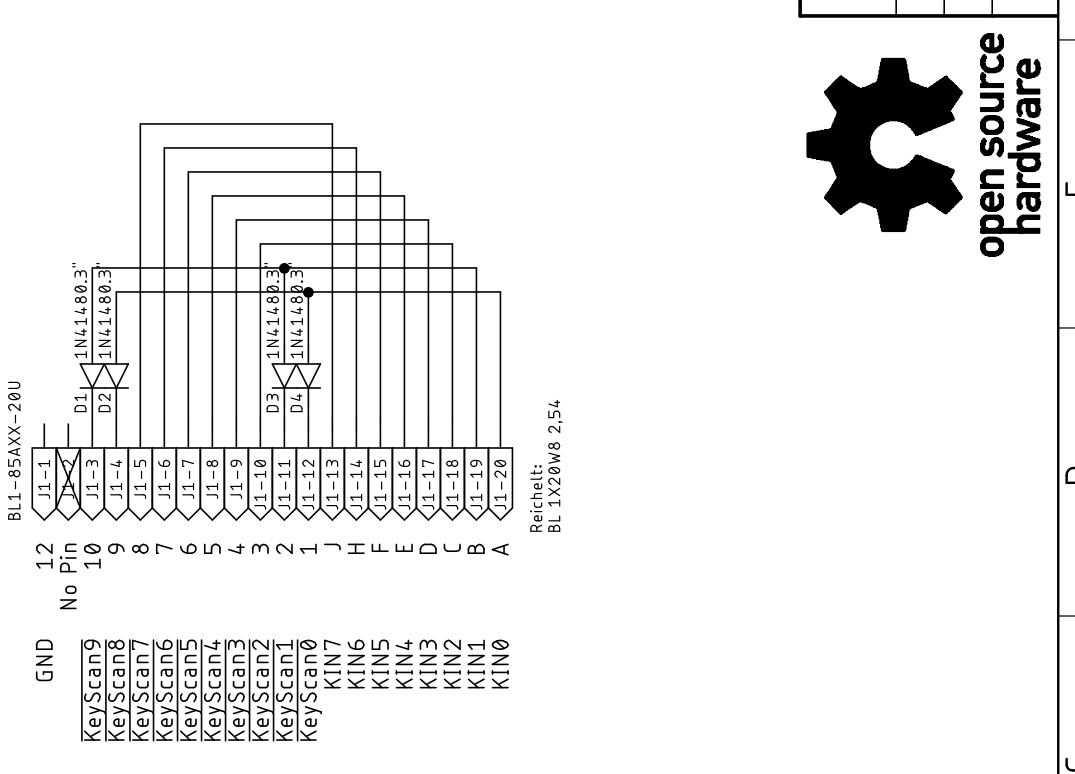
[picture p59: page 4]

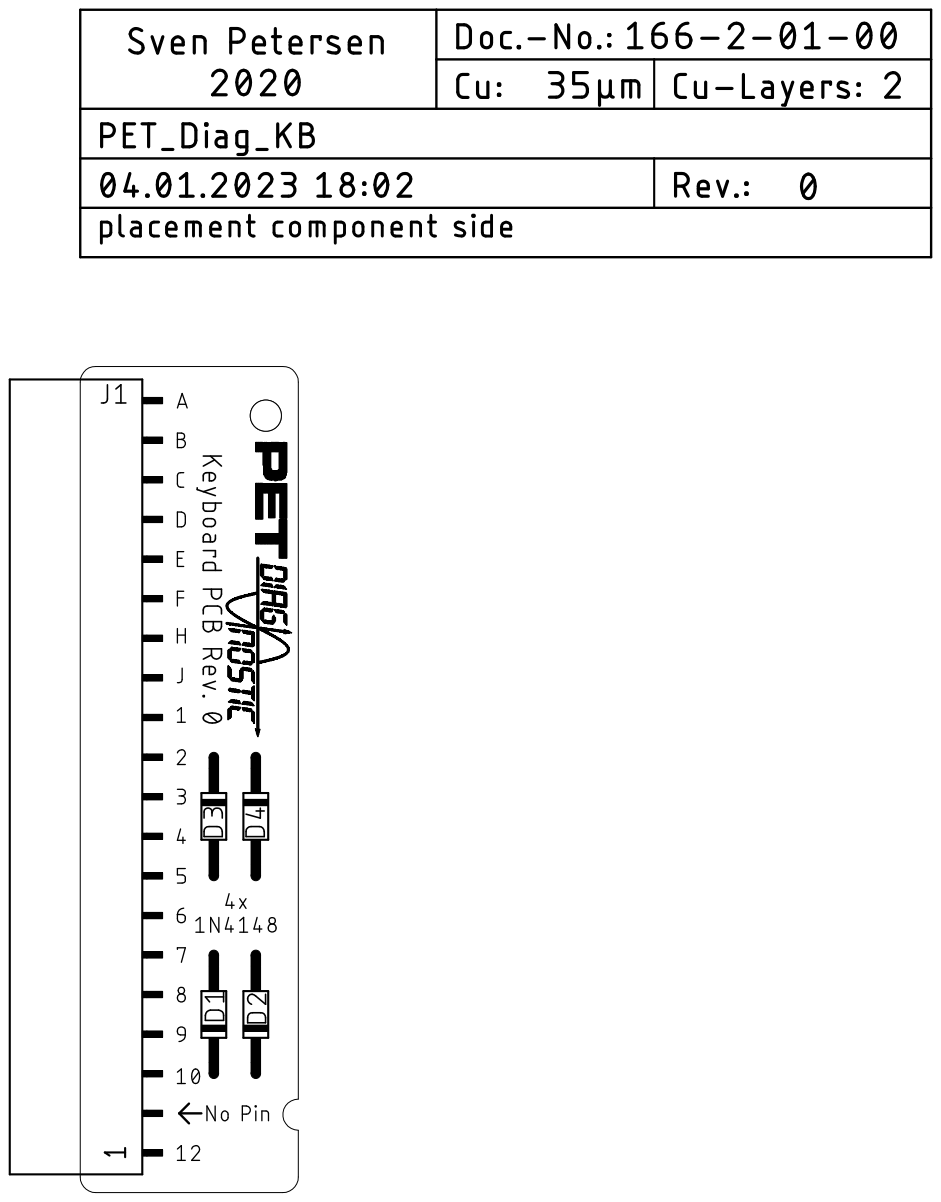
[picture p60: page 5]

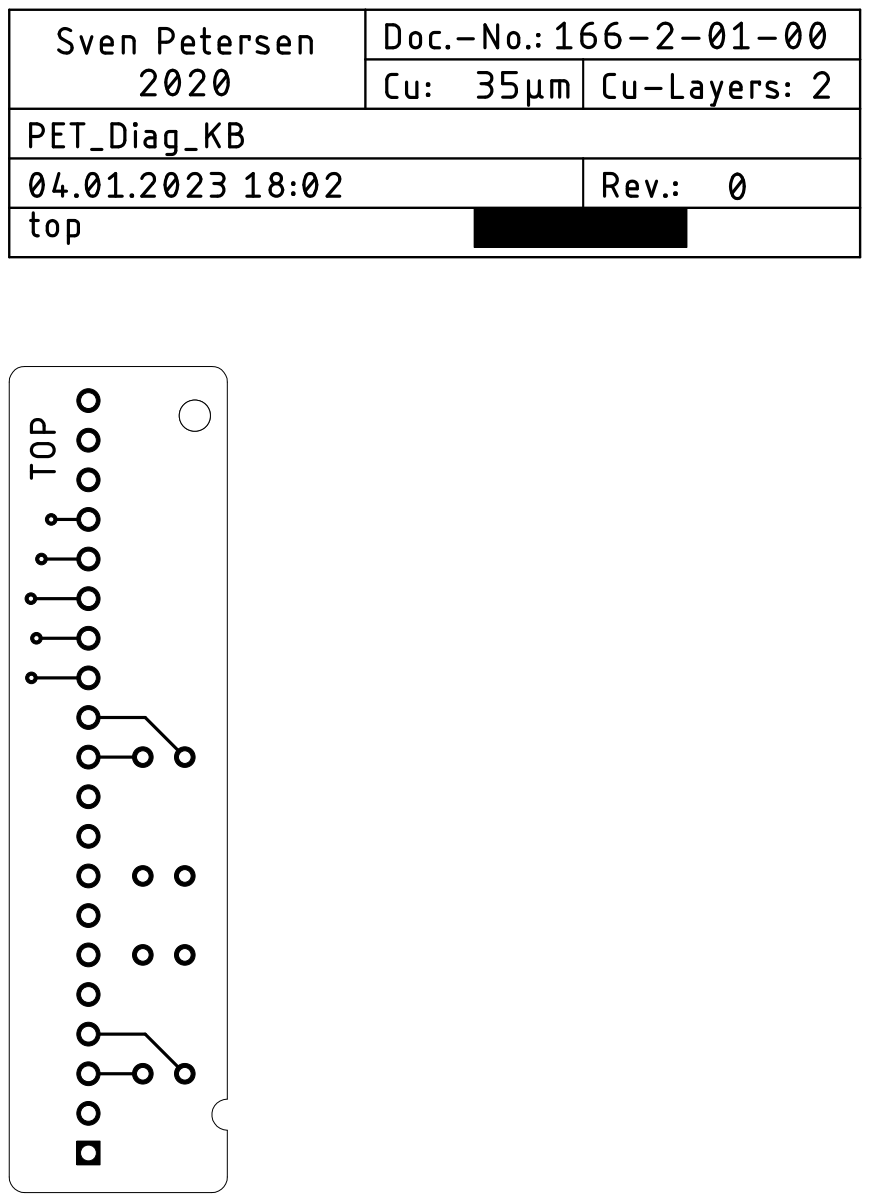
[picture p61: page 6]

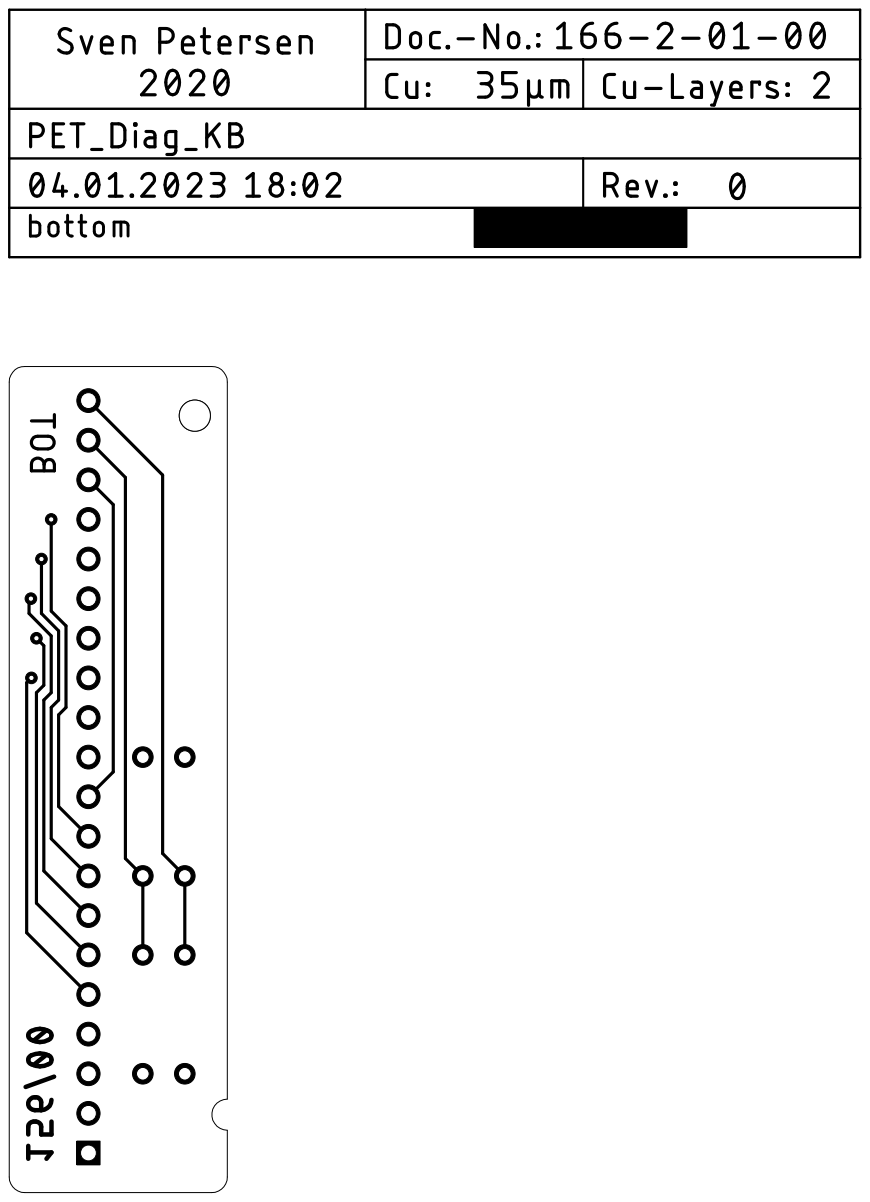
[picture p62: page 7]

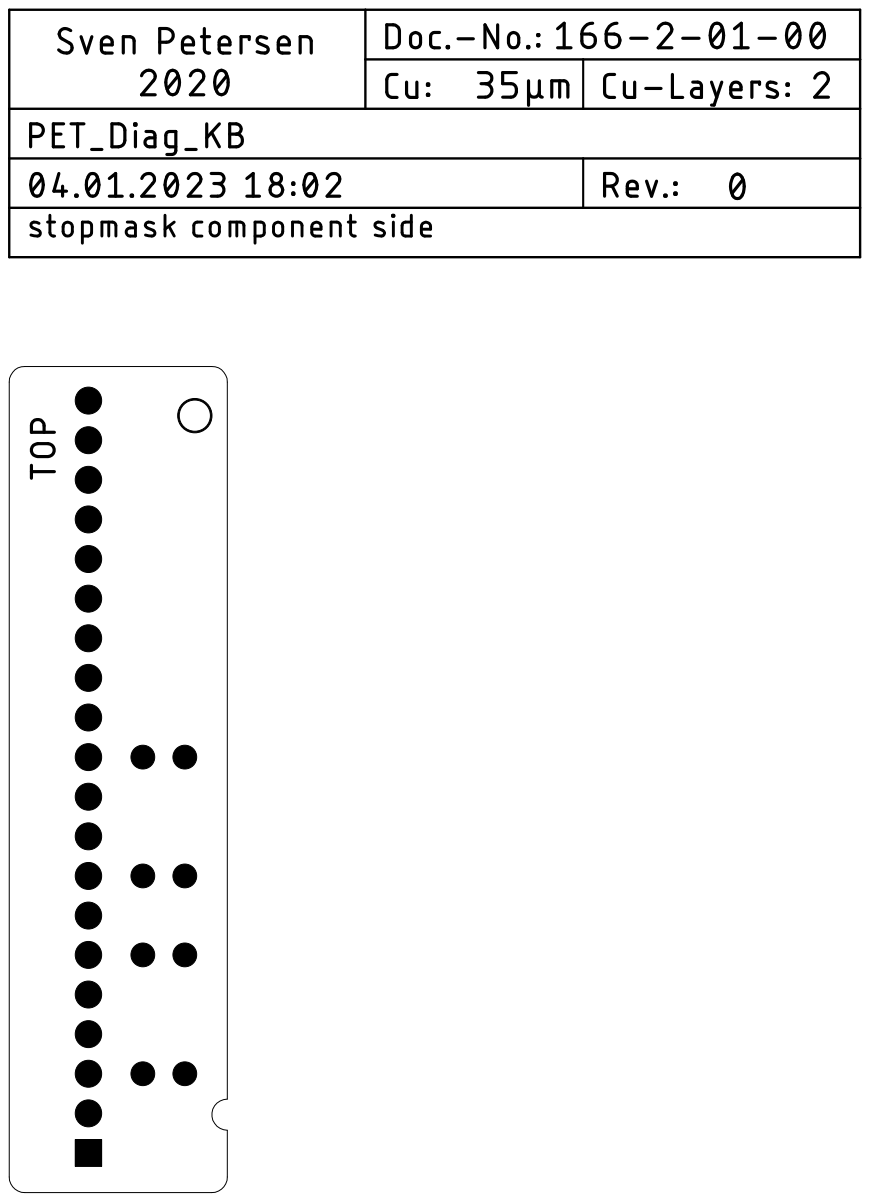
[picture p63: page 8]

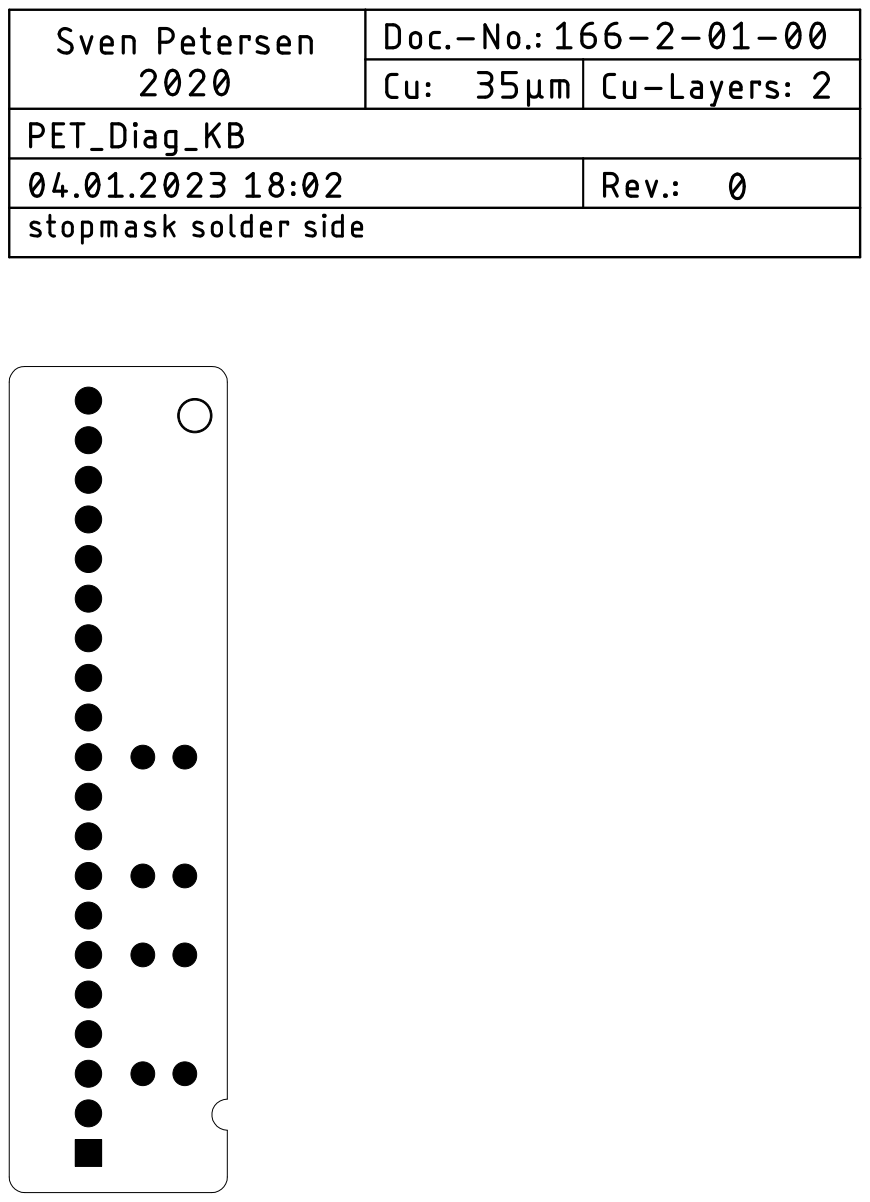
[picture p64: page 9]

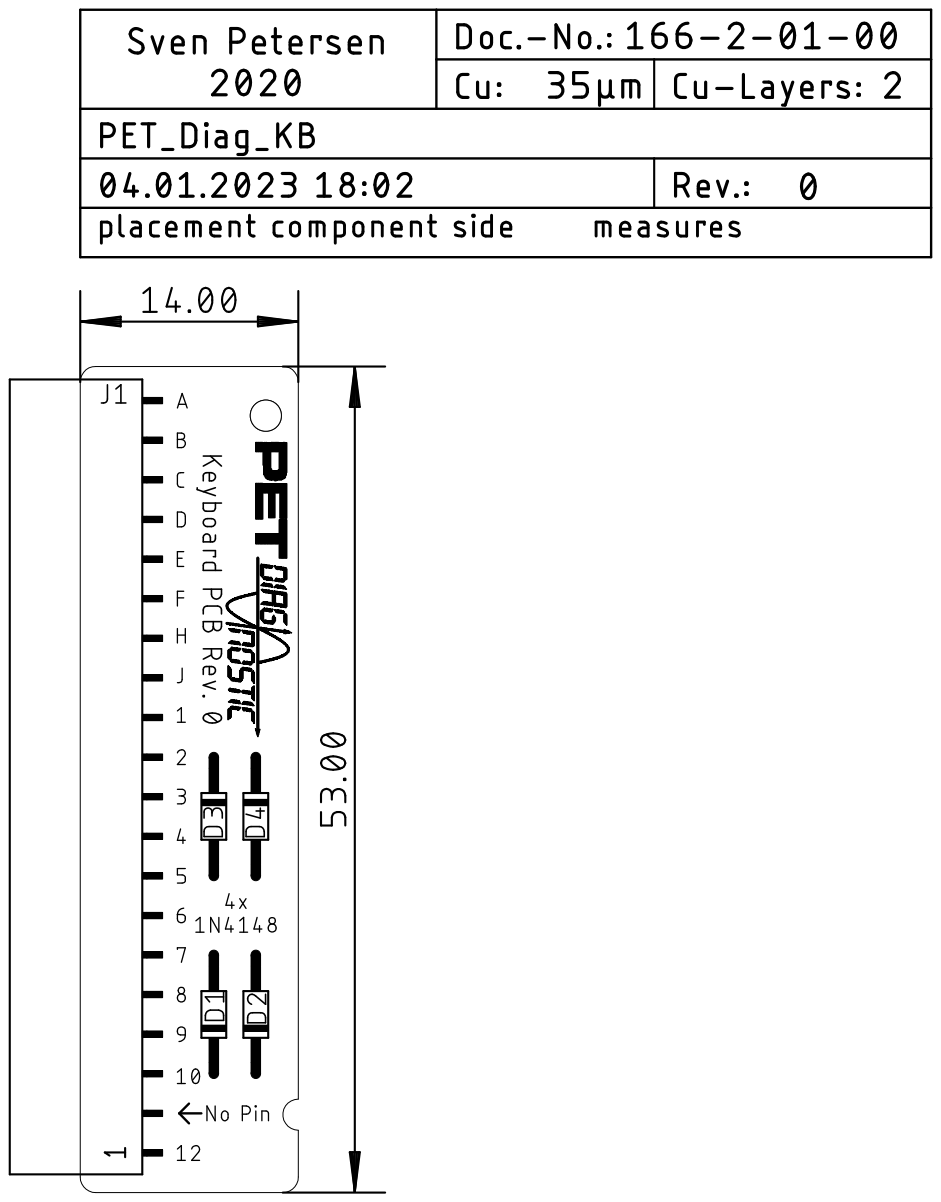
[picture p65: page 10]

Pos. Qty Value Footprint Ref.-No. Comment

1 1 166-2-01-00 2 Layer PCB Rev. 0 2 layer, Cu 35µ, HASL, 53.0mm x 14.0mm, 1.6mm FR4

2 4 1N4148 DO-35 D1, D2, D3, D4 Diode 1N4148

3 1 BL1-85AXX-20U BL1-85AXX-20U J1 e.g. MPE Garry, Reichelt BL 1x20W8 2,54

## Commodore PET Diagnostic Clip: Keyboard Dongle Rev. 0

## Bill of Material Rev. 0.0

PETDiag_KBDongle_BOM_v0_0.xlsx

Drafted by Sven Petersen Page 1 of 1

26.02.2023 18:53
Doc.No.: 166-5-01-00.0

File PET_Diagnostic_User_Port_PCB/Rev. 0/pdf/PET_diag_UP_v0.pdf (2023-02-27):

# Project Documentation

## Commodore PET/CBM80xx/40xx Diagnostic User Port PCB

## Project number: 165

## Revision: 0

## Date: 27.10.2020

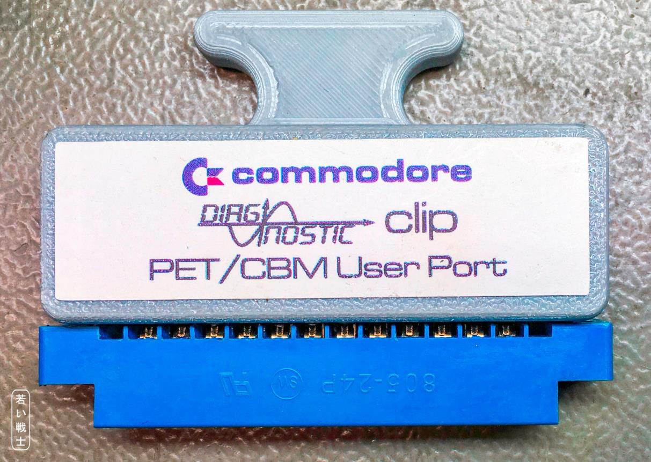
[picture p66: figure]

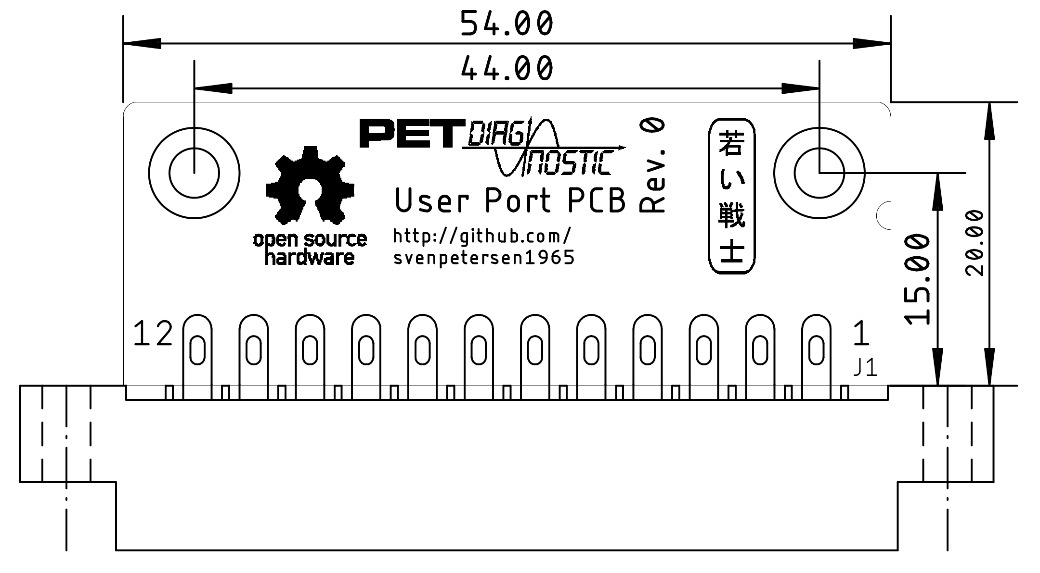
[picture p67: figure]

DiagClipUP_ModD.docx | | 27.02.2023 21:19
Drafted by Sven Petersen | Page 1 of 2 | Doc.-No.: 165-6-01-00

### Commodore PET/CBM80xx/40xx Diagnostic User Port PCB Rev. 0

### Module Description

## Introduction

The User Port PCB is part of the Diagnostic Clip project. Originally, it was made with a connector and wires, but since PCBs got cheap and provide interconnects very reproduceable with a low failure rate, it is a very simple board design.

The user port dongle/PCB connects the video signals and, IEEE Control signals and DIAGSENS & GRAPHIC to the GPIO pins of the user port. Further, it connects the tape read #1/#2 to the tape write signal. Not all user port signals are involved, so the user port is not completely tested.

Pins | Connected Signals
2-B | TVVIDEO - CA1
3-C | IEEESRQ - PA0
4-D | IEEEEOI - PA1
5-E-11 | DIAGSENS - PA2 - GRAPHIC
6-7-8 | TPREAD2 - TPWRITE - TPREAD1
9-K | TVVERT - PA6
10-L | TVHOR - PA7

The source of the information, that was required to design this PCB was retrieved from http://www.zimmers.net/anonftp/pub/cbm/schematics/computers/pet/diagnostics.txt

Figure 1: Dimensions of the User Port PCB

The 3D printable case requires two screws. Type C2.9 x 9.5 (DIN7981) self-tapping plastic screws are recommended.

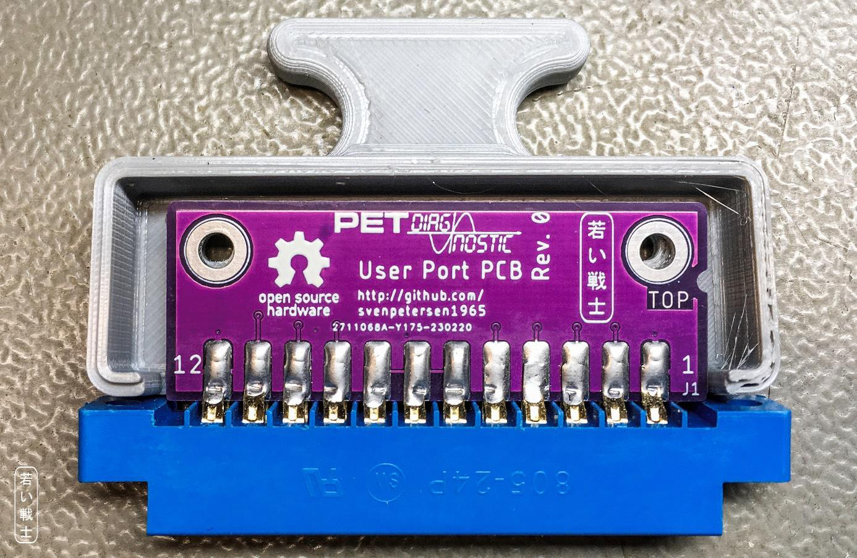
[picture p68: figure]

DiagClipUP_ModD.docx | | 27.02.2023 21:19
Drafted by Sven Petersen | Page 2 of 2 | Doc.-No.: 165-6-01-00

## Revision History

### Rev. 0

- Fully functional prototype








Pos. Qty Value Footprint Ref.-No. Comment

1 1 165-2-01-00 2 Layer PCB Rev. 0 2 layer, Cu 35µ, HASL, 54.0mm x 20.0mm, 1.6mm FR4
2 1 2x12, 3.96mm pitch USERPORT J1 edge connector, C64 user port, Ali Express: Series 805

## Commodore PET Diagnostic Clip: User Port Dongle Rev. 0

## Bill of Material Rev. 0.0

PETDiag_UPDongle_BOM_v0_0.xlsx

Drafted by Sven Petersen Page 1 of 1

26.02.2023 17:45
Doc.No.: 165-5-01-00.0

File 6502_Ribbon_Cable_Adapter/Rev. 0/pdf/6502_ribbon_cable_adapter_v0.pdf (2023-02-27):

# Project Documentation

## Commodore PET/CBM 6502 Ribbon Cable Adapter

## Project number: 162

## Revision: 0

## Date: 24.10.2020



6502CablAda_ModD.docx | | 23.02.2023 20:13
Drafted by Sven Petersen | Page 1 of 2 | Doc.-No.: 162-6-01-00

### Commodore PET/CBM 6502 Ribbon Cable Adapter Rev. 0

### Module Description

## Introduction

The 6502 Ribbon Cable Adapter is part of the PET Diagnostic Clip assembly. It replaces the actual DIP40 clip, which is available from Mouser etc. for about US$50. It provides a connection of the 6502 µprocessor to a 40 pin box header. The 6502 is inserted into its socket and it is then connected to the socket of the 6502 on the mainboard of the PET.

The Ribbon Cable Adapter (with or without the clip) can remain in the mainboard for normal operation.

Figure 1: Dimensions of the 6502 Ribbon Cable Adapter#

## Connectors

### J1 – Clip Connector

Signal Pin | Pin Signal
GND (6502, Pin 1) | 1 | 2 | /RES
RDY | 3 | 4 | PHI2
PHI | 5 | 6 | S.O.
/IRQ | 7 | 8 | PHI0
/NOROM | 9 | 10 | n.c. (6502, Pin 36)
/NMI | 11 | 12 | n.c. (6502, Pin 35)
SYNC | 13 | 14 | R//W

6502CablAda_ModD.docx | | 23.02.2023 20:13
Drafted by Sven Petersen | Page 2 of 2 | Doc.-No.: 162-6-01-00
Signal Pin | Pin Signal
5V | 15 | 16 | DB0
AB0 | 17 | 18 | DB1
AB1 | 19 | 20 | DB2
AB2 | 21 | 22 | DB3
AB3 | 23 | 24 | DB4
AB4 | 25 | 26 | DB5
AB5 | 27 | 28 | DB6
AB6 | 29 | 30 | DB7
AB7 | 31 | 32 | AB15
AB8 | 33 | 34 | AB14
AB9 | 35 | 36 | AB13
AB10 | 37 | 38 | AB12
AB11 | 39 | 40 | GND (6502, Pin 21)

It is advised to use a ribbon cable, not longer than 15cm and to install the strain reliefs.

### IC1(socket for the 6502, IC2 (6502 pin header)

Signal Pin | Pin Signal
To J1 Pin 1(GND) | 1 | 40 | /RES
RDY | 2 | 39 | PHI2
PHI | 3 | 38 | S.O.
/IRQ | 4 | 37 | PHI0
/NOROM | 5 | 36 | To J1, pin 10
/NMI | 6 | 35 | To J1, pin 12
SYNC | 7 | 34 | R//W
5V | 8 | 33 | DB0
AB0 | 9 | 32 | DB1
AB1 | 10 | 31 | DB2
AB2 | 11 | 30 | DB3
AB3 | 12 | 29 | DB4
AB4 | 13 | 28 | DB5
AB5 | 14 | 27 | DB6
AB6 | 15 | 26 | DB7
AB7 | 16 | 25 | AB15
AB8 | 17 | 24 | AB14
AB9 | 18 | 23 | AB13
AB10 | 19 | 22 | AB12
AB11 | 20 | 21 | GND

The precision round pins are very fragile. It is advised to keep them in a second DIP40 round pin socket.

## Revision History

### Rev. 0

- Working prototype










2 1 2x20 box header, 2.54mm; pitch; reichelt.de WSL 40G; 10120540, Reichelt BKL 10120540

Pos. Qty Value Footprint Ref.-No. Comment

1 1 162-2-01-00 2 Layer PCB Rev. 0 2 layer, Cu 35µ, HASL, 58.8mm x 32.0mm, 1.6mm FR4

2X20WV J1 2x20, box pin header or standard pin header, e.g.

4 1 3mm/gn 3MM LD1 standard LED 3mm/green

5 1 6502PINS DIL40_PINS_SS IC2 Precision round pin header, e.G. bkl-electronic.de Art.-Nr.

6 1 DIP40 socket GS40P IC1 Socket for 6502

## Commodore PET Diagnostic Clip: 6502 Ribbon Cable Adapter Rev. 0

## Bill of Material Rev. 0.0

PETDiag_6502Ada_BOM_v0_0.xlsx

Drafted by Sven Petersen Page 1 of 1

23.02.2023 20:15
Doc.No.: 162-5-01-00.0

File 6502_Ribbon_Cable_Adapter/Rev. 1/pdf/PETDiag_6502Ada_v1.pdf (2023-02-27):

# Project Documentation

## Commodore PET/CBM 6502 Ribbon Cable Adapter

## Project number: 162

## Revision: 1

## Date: 01.01.2023



6502CablAda_ModD.docx | | 23.02.2023 20:04
Drafted by Sven Petersen | Page 1 of 4 | Doc.-No.: 162-6-01-01

### Commodore PET/CBM 6502 Ribbon Cable Adapter Rev. 1

### Module Description

## Introduction

The 6502 Ribbon Cable Adapter is part of the PET Diagnostic Clip assembly. It replaces the actual DIP40 clip, which is available from Mouser etc. for about US$50. It provides a connection of the 6502 µprocessor to a 40 pin box header. The 6502 is inserted into its socket and it is then connected to the socket of the 6502 on the mainboard of the PET.

The Ribbon Cable Adapter (with or without the clip) can remain in the mainboard for normal operation.

Figure 1: Dimensions of the 6502 Ribbon Cable Adapter

To prevent the need to short circuit the address lines AB13 and AB14 to GND to redirect kernal ROM accesses from $Fxxx to $9xxx (the lower EDIT ROM address space), two AND gates (IC3: 74LS08) are inserted directly after the processor address lines (A13 and A14). This way, the address
lines can be set low. This kind of redirection is required for all <non CRTC type PETs, which are not
capable to switch off all system ROMs with the /NOROM signal (being low). This feature requires a diagnostic clip rev. 2 (or later).

## Switch SW1

The switch has to be set to <Force $9xxx= for these non-CRTC mainboards. The CRTC mainboards
make use of the /NOROM signal and do not require the said redirection.


6502CablAda_ModD.docx | | 23.02.2023 20:04
Drafted by Sven Petersen | Page 2 of 4 | Doc.-No.: 162-6-01-01

Figure 2: Mini slide switch

These mini slide switches can be found on Amazon, Ebay and AliExpress. A possible search term is
<mini slide switch dpdt= or <MSS22D18=, which will not show these switches exclusively, but it should
not be too hard to find the right ones.

## Assembly

First, the SMD components are soldered.

The precision round pins should be aligned properly. For this purpose, they are inserted into the DIP40 socket, inserted into the solder pads, soldered one pin each, checked, if they are properly aligned and vertical, adjusted if required and finally soldered completely.

Figure 3: First steps - SMD components and pin strips assembled


6502CablAda_ModD.docx | | 23.02.2023 20:04
Drafted by Sven Petersen | Page 3 of 4 | Doc.-No.: 162-6-01-01

Figure 4: bottom side of the assembled board

## Connectors

### J1 – Clip Connector

Signal Pin | Pin Signal
GND (6502, Pin 1) | 1 | 2 | /RES
RDY | 3 | 4 | PHI2
PHI | 5 | 6 | S.O.
/IRQ | 7 | 8 | PHI0
/NOROM | 9 | 10 | n.c. (6502, Pin 36)
/NMI | 11 | 12 | n.c. (6502, Pin 35)
SYNC | 13 | 14 | R//W
5V | 15 | 16 | DB0
AB0 | 17 | 18 | DB1
AB1 | 19 | 20 | DB2
AB2 | 21 | 22 | DB3
AB3 | 23 | 24 | DB4
AB4 | 25 | 26 | DB5
AB5 | 27 | 28 | DB6
AB6 | 29 | 30 | DB7
AB7 | 31 | 32 | AB15
AB8 | 33 | 34 | AB14
AB9 | 35 | 36 | AB13
AB10 | 37 | 38 | AB12
AB11 | 39 | 40 | GND (6502, Pin 21)

It is advised to use a ribbon cable, not longer than 15cm and to install the strain reliefs.

6502CablAda_ModD.docx | | 23.02.2023 20:04
Drafted by Sven Petersen | Page 4 of 4 | Doc.-No.: 162-6-01-01

### IC1(socket for the 6502, IC2 (6502 pin header)

Signal Pin | Pin Signal
To J1 Pin 1(GND) | 1 | 40 | /RES
RDY | 2 | 39 | PHI2
PHI | 3 | 38 | S.O.
/IRQ | 4 | 37 | PHI0
/NOROM | 5 | 36 | To J1, pin 10
/NMI | 6 | 35 | To J1, pin 12
SYNC | 7 | 34 | R//W
5V | 8 | 33 | DB0
AB0 | 9 | 32 | DB1
AB1 | 10 | 31 | DB2
AB2 | 11 | 30 | DB3
AB3 | 12 | 29 | DB4
AB4 | 13 | 28 | DB5
AB5 | 14 | 27 | DB6
AB6 | 15 | 26 | DB7
AB7 | 16 | 25 | AB15
AB8 | 17 | 24 | AB14
AB9 | 18 | 23 | AB13
AB10 | 19 | 22 | AB12
AB11 | 20 | 21 | GND

The precision round pins are very fragile. It is advised to keep them in a second DIP40 round pin socket.

## Revision History

### Rev. 0

- Working prototype
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









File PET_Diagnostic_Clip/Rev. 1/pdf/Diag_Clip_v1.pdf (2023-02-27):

## Project Documentation

Commodore PET/CBM80xx/40xx Diagnostic Clip

Project number: 163

Revision: 1

Date: 28.11.2021









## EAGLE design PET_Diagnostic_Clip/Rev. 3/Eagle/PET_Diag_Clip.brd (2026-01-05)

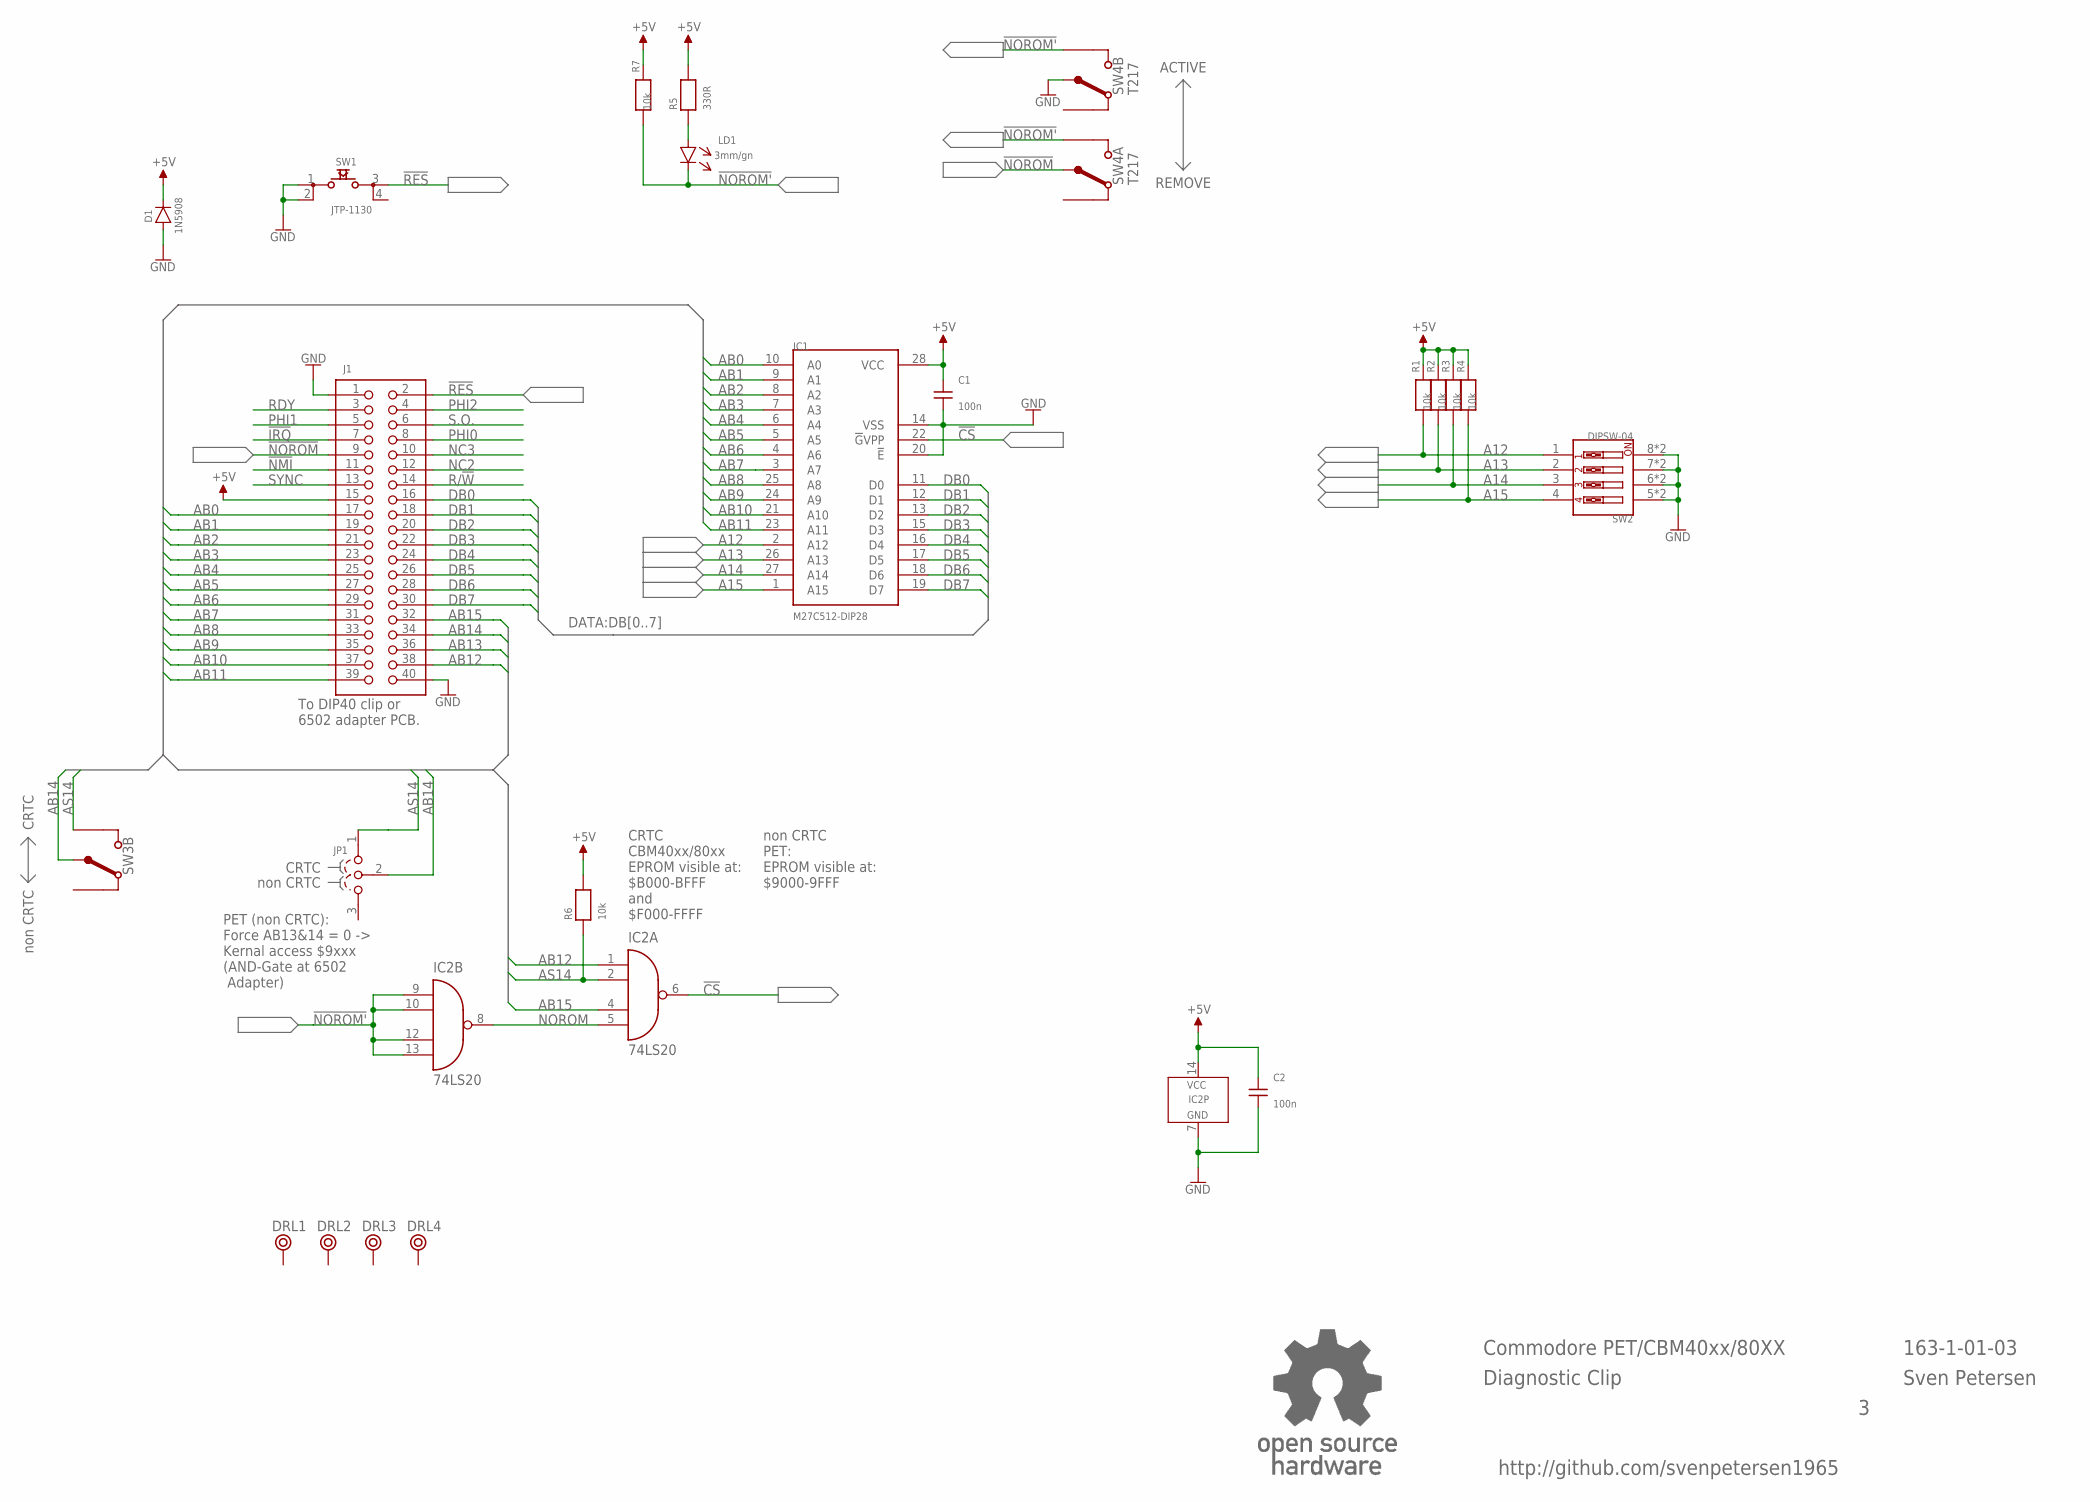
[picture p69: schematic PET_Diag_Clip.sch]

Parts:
C1, C2: 100n; C-2,5
D1: 1N5908; DO-201
DRL1, DRL2, DRL3, DRL4: BOHR3,5
IC1: M27C512-DIP28; DIL28-6
IC2: 74LS20; DIL-14
J1: PINHD-2X20WV; 2X20WV
JP1: COMBI-3P
LD1: 3mm/gn; 3MM
R1, R2, R3, R4, R6, R7: 10k; R-10
R5: 330R; R-10
SW1: JTP-1130
SW2: DIPSW-04; DIPSW-04V-COMBI
SW3: MSS22D18; DPDT_9MM
SW4: T217; T217_SIDE
U$13: OPEN_SOURCE_HW; OPENHW

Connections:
!CS: IC1.22 (!G!VPP), IC2.6 (O)
!IRQ: J1.7
!NMI: J1.11
!NOROM: J1.9, SW4.COM1 (COM)
!NOROM': IC2.9 (I0), IC2.10 (I1), IC2.12 (I2), IC2.13 (I3), LD1.C (K), R7.2, SW4.UP1 (UP), SW4.UP2 (UP)
!RES: J1.2, SW1.3
+5V: C1.2, C2.2, D1.K, IC1.28 (VCC), IC2.14 (VCC), J1.15, R1.1, R2.1, R3.1, R4.1, R5.2, R6.2, R7.1
A12: IC1.2 (A12), R1.2, SW2.1
A13: IC1.26 (A13), R2.2, SW2.2
A14: IC1.27 (A14), R3.2, SW2.3
A15: IC1.1 (A15), R4.2, SW2.4
AB0: IC1.10 (A0), J1.17
AB1: IC1.9 (A1), J1.19
AB2: IC1.8 (A2), J1.21
AB3: IC1.7 (A3), J1.23
AB4: IC1.6 (A4), J1.25
AB5: IC1.5 (A5), J1.27
AB6: IC1.4 (A6), J1.29
AB7: IC1.3 (A7), J1.31
AB8: IC1.25 (A8), J1.33
AB9: IC1.24 (A9), J1.35
AB10: IC1.21 (A10), J1.37
AB11: IC1.23 (A11), J1.39
AB12: IC2.1 (I0), J1.38
AB13: J1.36
AB14: J1.34, JP1.2, SW3.5 (COM)
AB15: IC2.4 (I2), J1.32
AS14: IC2.2 (I1), JP1.1, R6.1, SW3.6 (UP)
DB0: IC1.11 (D0), J1.16
DB1: IC1.12 (D1), J1.18
DB2: IC1.13 (D2), J1.20
DB3: IC1.15 (D3), J1.22
DB4: IC1.16 (D4), J1.24
DB5: IC1.17 (D5), J1.26
DB6: IC1.18 (D6), J1.28
DB7: IC1.19 (D7), J1.30
GND: C1.1, C2.1, D1.A, IC1.14 (VSS), IC1.20 (!E), IC2.7 (GND), J1.1, J1.40, SW1.1, SW1.2, SW2.5, SW2.5A (5), SW2.6, SW2.6A (6), SW2.7, SW2.7A (7), SW2.8, SW2.8A (8), SW4.COM2 (COM)
unnamed: LD1.A, R5.1
NC2: J1.12
NC3: J1.10
NOROM: IC2.5 (I3), IC2.8 (O)
PHI0: J1.8
PHI1: J1.5
PHI2: J1.4
R/!W: J1.14
RDY: J1.3
S.O.: J1.6
SYNC: J1.13

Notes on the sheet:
Commodore PET/CBM40xx/80XX
Diagnostic Clip
Sven Petersen
163-1-01-03
http://github.com/svenpetersen1965
To DIP40 clip or 6502 adapter PCB.
CRTC CBM40xx/80xx EPROM visible at: $B000-BFFF and $F000-FFFF
CRTC
non CRTC
PET (non CRTC): Force AB13&14 = 0 -> Kernal access $9xxx (AND-Gate at 6502 Adapter)
non CRTC PET: EPROM visible at: $9000-9FFF
ACTIVE
REMOVE

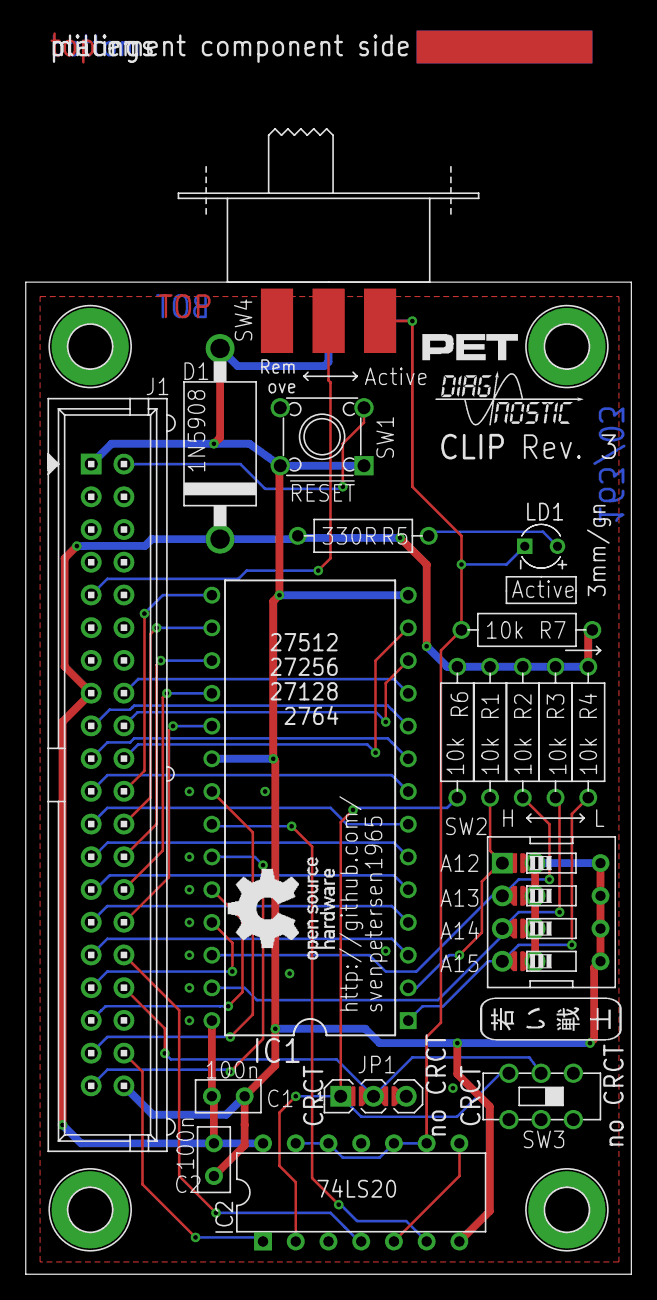
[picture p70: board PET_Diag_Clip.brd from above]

Board: 2 copper layers, 47.0 x 77.0 mm, 29 parts (0 on the bottom side), 36 nets.

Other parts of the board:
U$27: PET_SMALL
U$30: DIAG_SMALL
U$34: 2LAYER
U$35: PCB-TITLE/
U$42: SVEN_TAG

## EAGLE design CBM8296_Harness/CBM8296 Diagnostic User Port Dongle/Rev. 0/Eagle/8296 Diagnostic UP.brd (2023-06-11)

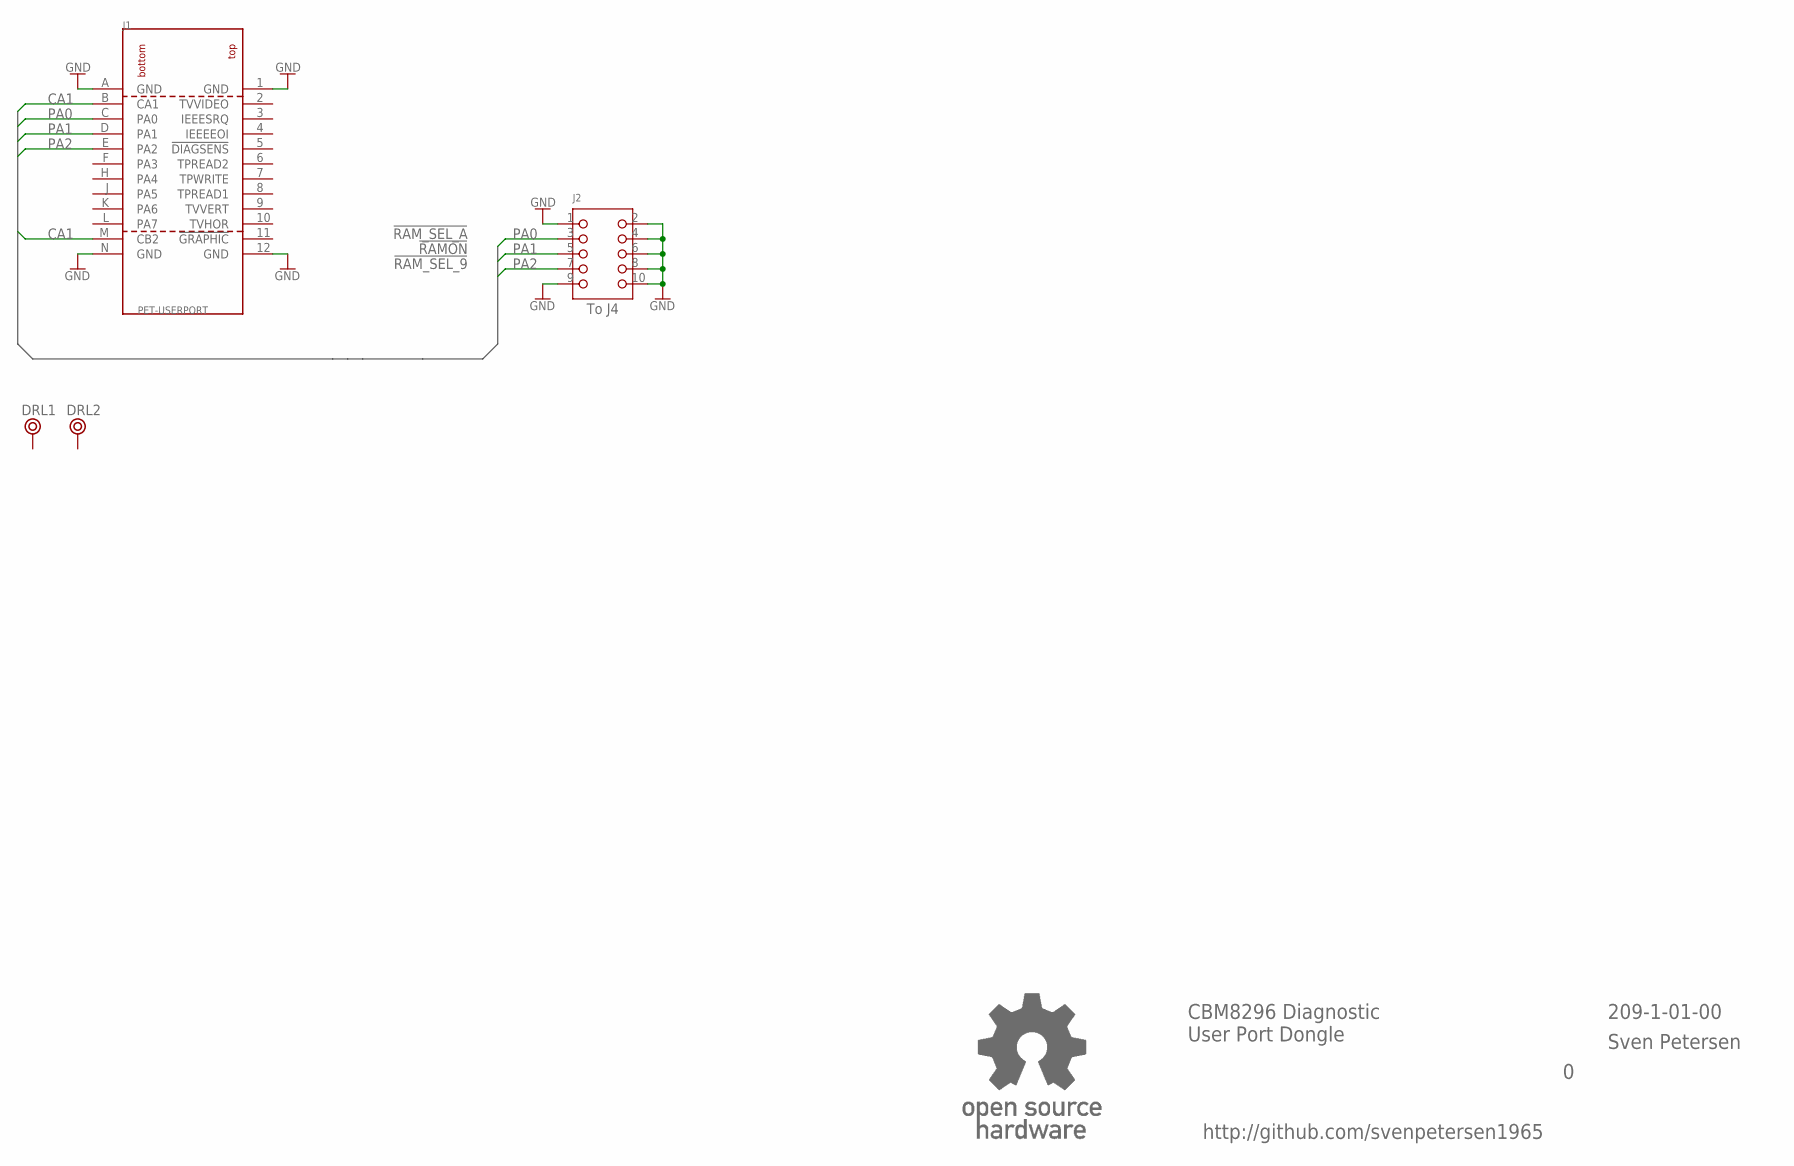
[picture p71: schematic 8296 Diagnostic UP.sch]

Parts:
DRL1, DRL2: BOHR3,5
J1: PET-USERPORT; USERPORT
J2: 2X05WV
U$13: OPEN_SOURCE_HW; OPENHW

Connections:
CA1: J1.B (CA1), J1.M (CB2)
GND: J1.1 (GND), J1.12 (GND), J1.A (GND), J1.N (GND), J2.1, J2.2, J2.4, J2.6, J2.8, J2.9, J2.10
PA0: J1.C (PA0), J2.3
PA1: J1.D (PA1), J2.5
PA2: J1.E (PA2), J2.7

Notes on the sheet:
CBM8296 Diagnostic User Port Dongle
209-1-01-00
Sven Petersen
http://github.com/svenpetersen1965
To J4
!RAM_SEL_A
!RAMON
!RAM_SEL_9

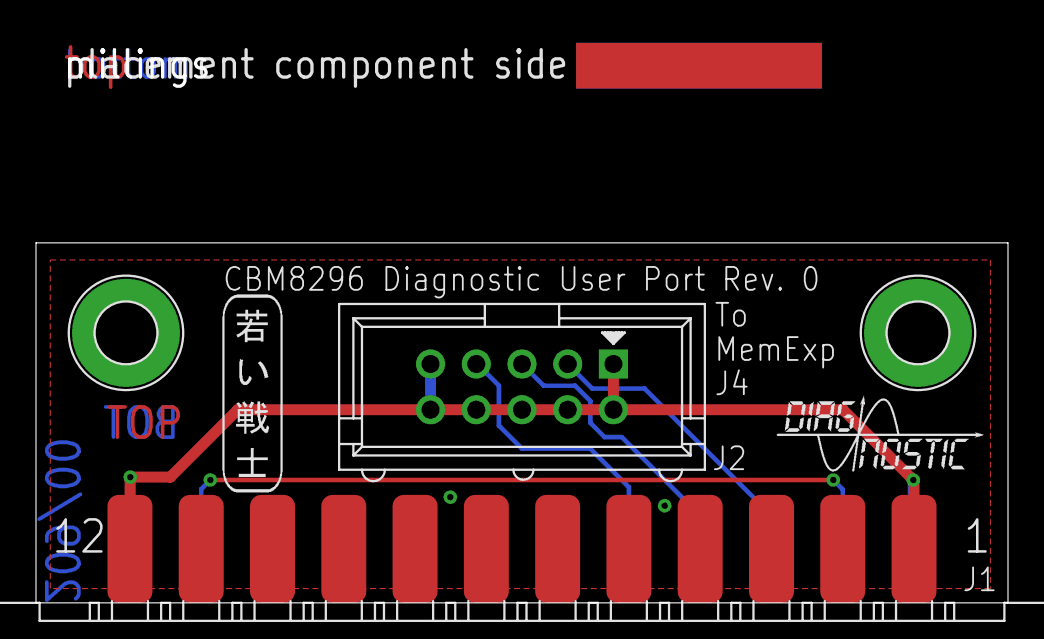
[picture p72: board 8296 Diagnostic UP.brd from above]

Board: 2 copper layers, 54.0 x 20.0 mm, 9 parts (1 on the bottom side), 5 nets.

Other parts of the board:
U$8: 2LAYER
U$9: PCB-TITLE/
U$10: SVEN_TAG
U$12: DIAG_SMALL

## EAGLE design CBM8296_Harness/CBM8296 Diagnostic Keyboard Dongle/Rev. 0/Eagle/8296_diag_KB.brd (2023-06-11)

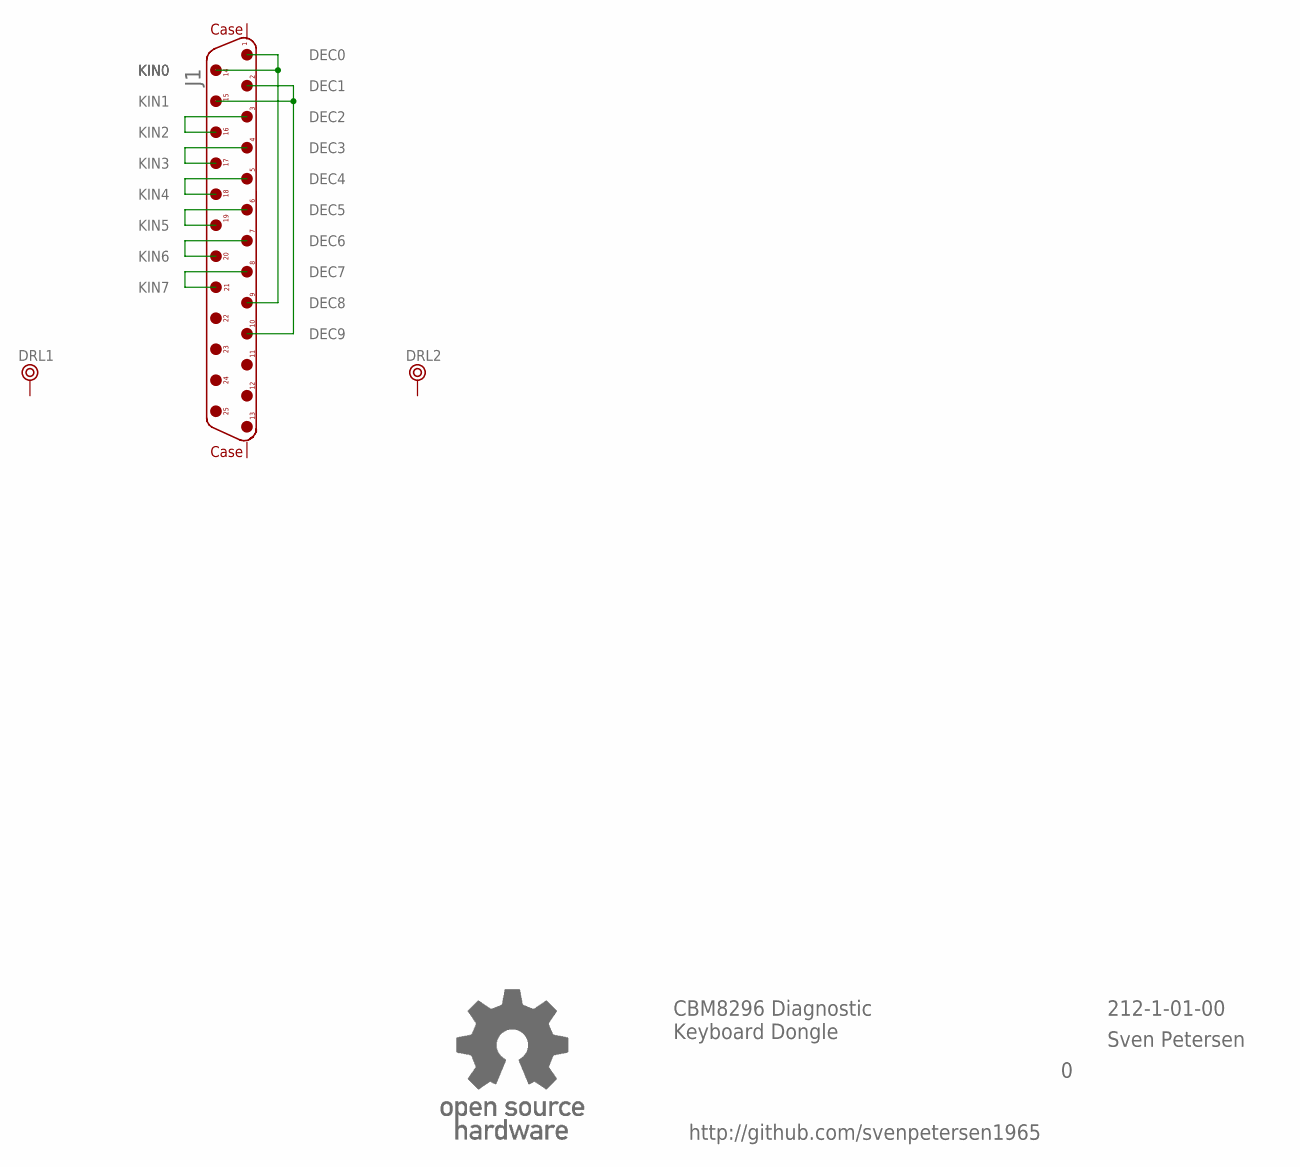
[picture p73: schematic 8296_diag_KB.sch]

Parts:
DRL1, DRL2: BOHR3,5
J1: D25M90CLEU
U$13: OPEN_SOURCE_HW; OPENHW

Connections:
unnamed: J1.1, J1.9, J1.14
unnamed: J1.2, J1.10, J1.15
unnamed: J1.3, J1.16
unnamed: J1.4, J1.17
unnamed: J1.5, J1.18
unnamed: J1.6, J1.19
unnamed: J1.7, J1.20
unnamed: J1.8, J1.21

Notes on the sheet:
CBM8296 Diagnostic Keyboard Dongle
212-1-01-00
Sven Petersen
http://github.com/svenpetersen1965
DEC0
DEC1
DEC2
DEC3
DEC4
DEC6
DEC5
DEC7
DEC8
DEC9
KIN0
KIN1
KIN2
KIN3
KIN4
KIN5
KIN6
KIN7

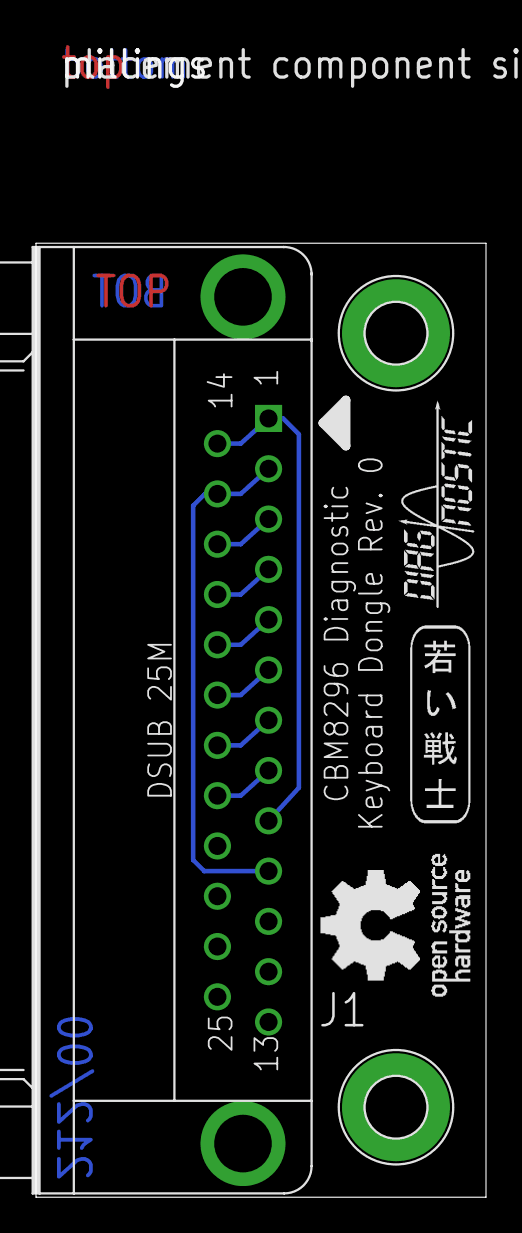
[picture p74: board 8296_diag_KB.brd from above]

Board: 2 copper layers, 25.0 x 53.0 mm, 8 parts (0 on the bottom side), 8 nets.

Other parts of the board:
U$2: DIAG_SMALL
U$3: SVEN_TAG
U$4: 2LAYER
U$5: PCB-TITLE/

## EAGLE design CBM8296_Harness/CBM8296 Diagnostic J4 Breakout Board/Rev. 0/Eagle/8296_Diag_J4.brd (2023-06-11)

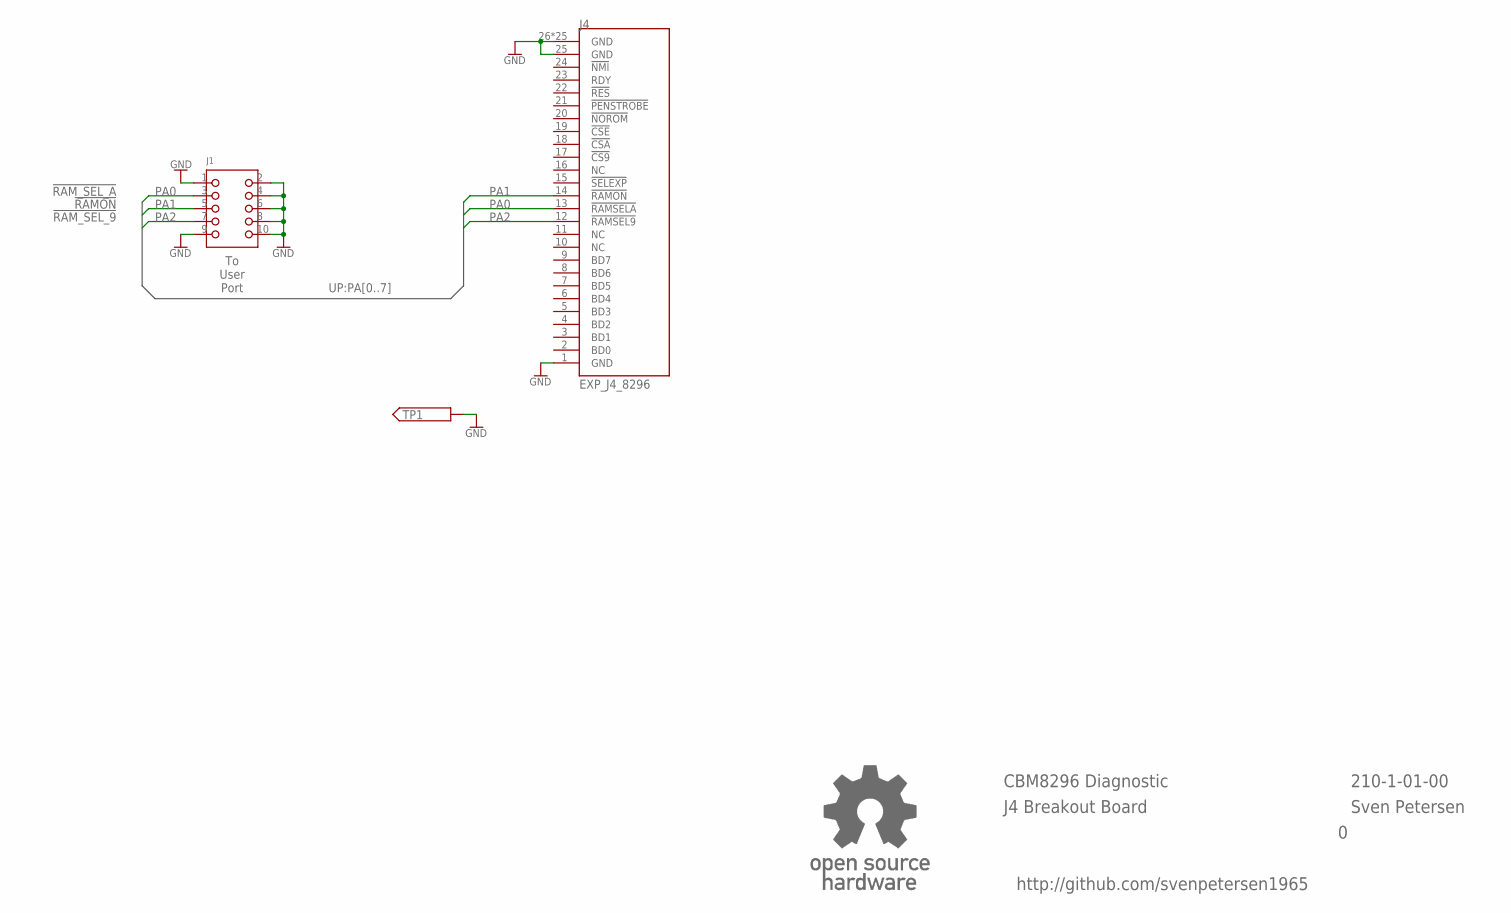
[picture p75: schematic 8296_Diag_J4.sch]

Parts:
J1: 2X05WV
J4: EXP_J4_8296; PET_EXPANSION_BOT
TP1: PINHD-1X1; 1X01
U$5: OPEN_SOURCE_HW; OPENHW

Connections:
GND: J1.1, J1.2, J1.4, J1.6, J1.8, J1.9, J1.10, J4.1 (GND), J4.25 (GND), J4.26 (GND), J4.27 (GND), J4.28 (GND), J4.29 (GND), J4.30 (GND), J4.31 (GND), J4.32 (GND), J4.33 (GND), J4.34 (GND), J4.35 (GND), J4.36 (GND), J4.37 (GND), J4.38 (GND), J4.39 (GND), J4.40 (GND), J4.41 (GND), J4.42 (GND), J4.43 (GND), J4.44 (GND), J4.45 (GND), J4.46 (GND), J4.47 (GND), J4.48 (GND), J4.49 (GND), J4.50 (GND), TP1.1
PA0: J1.3, J4.13 (!RAMSELA)
PA1: J1.5, J4.14 (!RAMON)
PA2: J1.7, J4.12 (!RAMSEL9)

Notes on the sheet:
CBM8296 Diagnostic
J4 Breakout Board
210-1-01-00
Sven Petersen
http://github.com/svenpetersen1965
To User Port
!RAM_SEL_A
!RAMON
!RAM_SEL_9

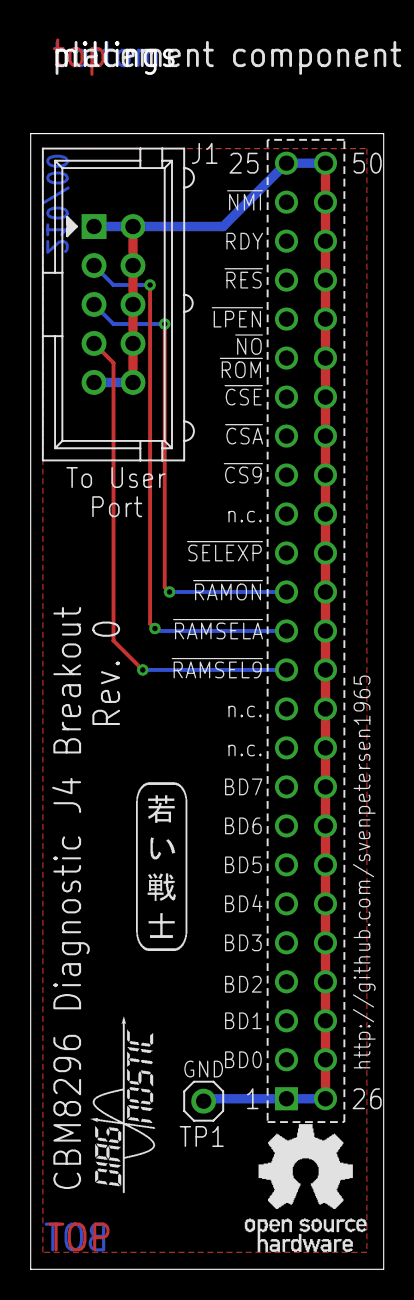
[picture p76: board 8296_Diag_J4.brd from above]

Board: 2 copper layers, 23.0 x 74.0 mm, 8 parts (0 on the bottom side), 4 nets.

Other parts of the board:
U$8: 2LAYER
U$9: SVEN_TAG
U$10: PCB-TITLE/
U$12: DIAG_SMALL

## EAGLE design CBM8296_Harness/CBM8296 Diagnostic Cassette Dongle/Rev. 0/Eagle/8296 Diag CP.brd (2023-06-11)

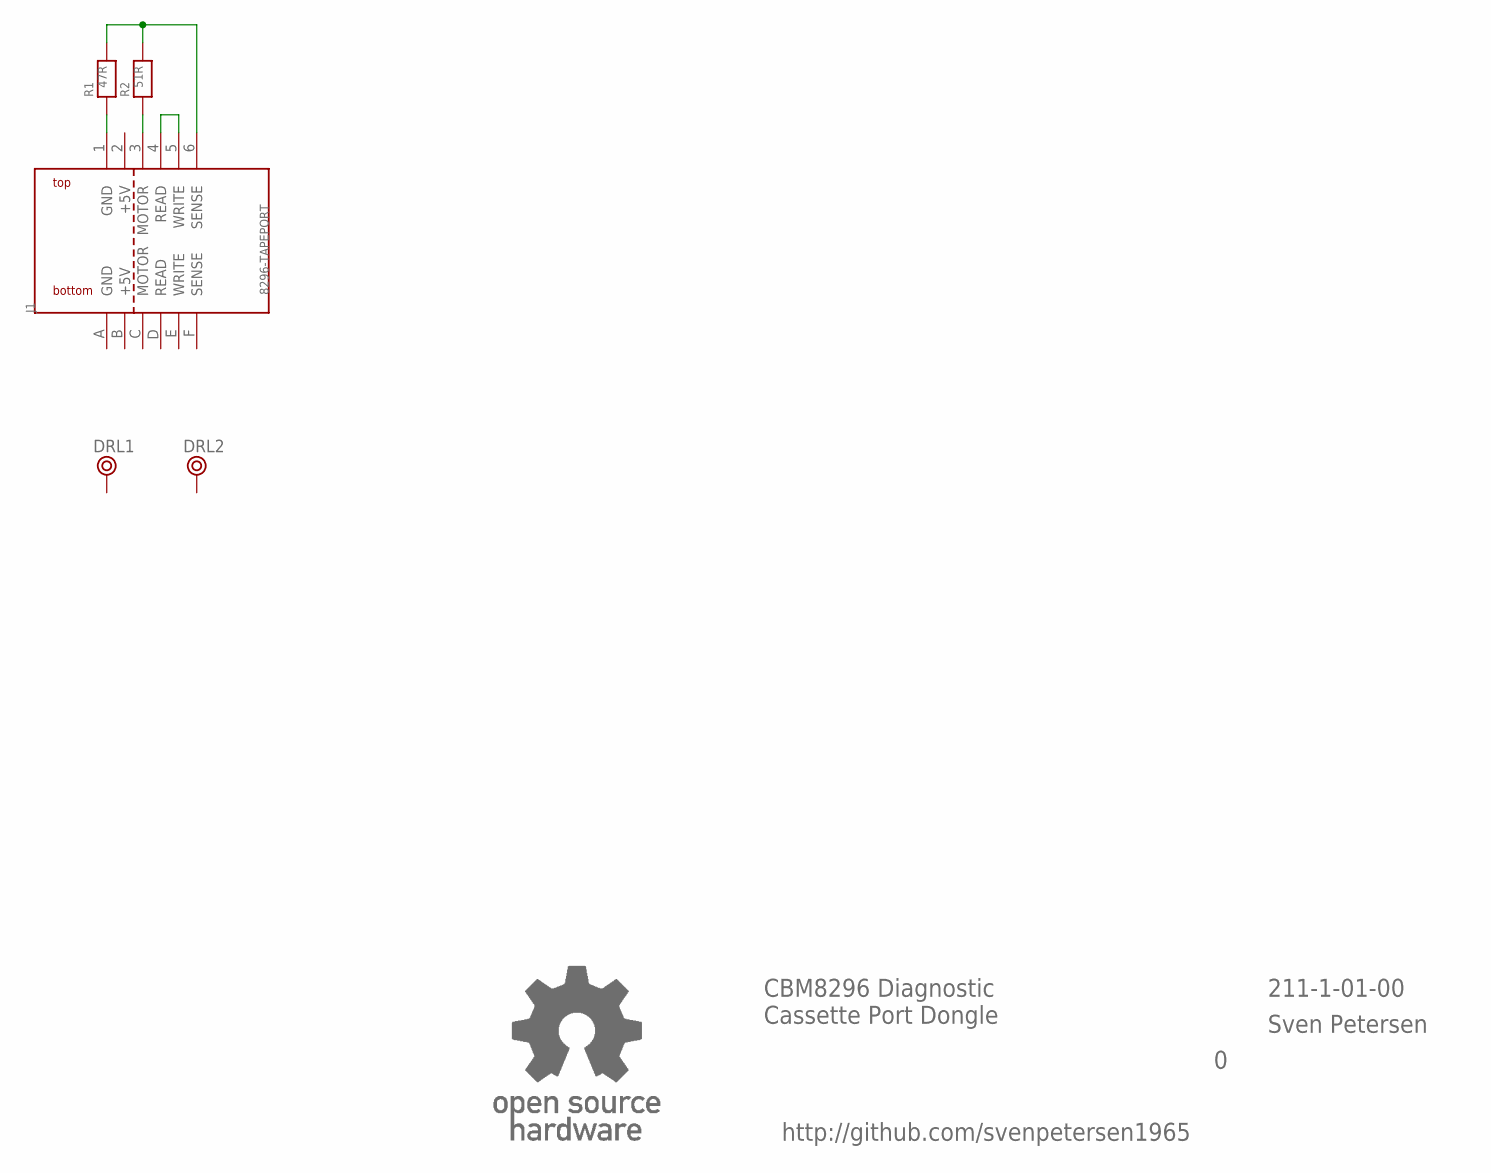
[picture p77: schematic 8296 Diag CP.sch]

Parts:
DRL1, DRL2: BOHR3,5
J1: 8296-TAPEPORT; TAPEPORT
R1: 47R; R-10
R2: 51R; R-10
U$13: OPEN_SOURCE_HW; OPENHW

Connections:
+5V: J1.2 (+5V), J1.B (+5V)
GND: J1.A (GND)
unnamed: J1.6 (SENSE), R1.2, R2.2
unnamed: J1.3 (MOTOR), R2.1
unnamed: J1.1 (GND), R1.1
unnamed: J1.4 (READ), J1.5 (WRITE)

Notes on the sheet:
CBM8296 Diagnostic Cassette Port Dongle
211-1-01-00
Sven Petersen
http://github.com/svenpetersen1965

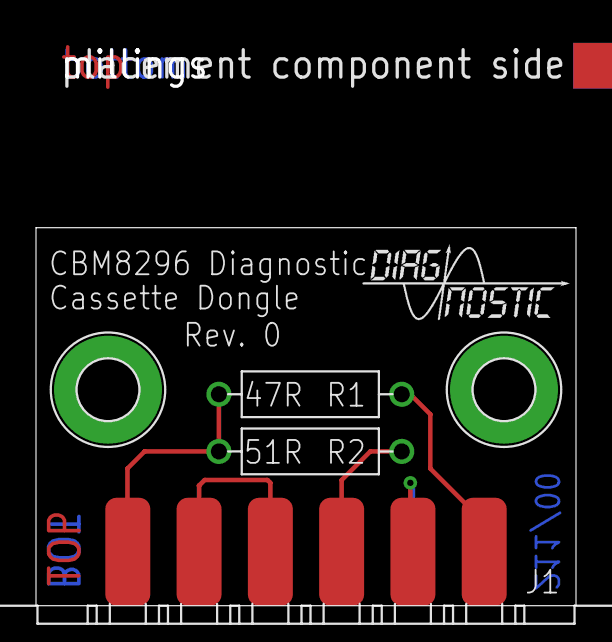
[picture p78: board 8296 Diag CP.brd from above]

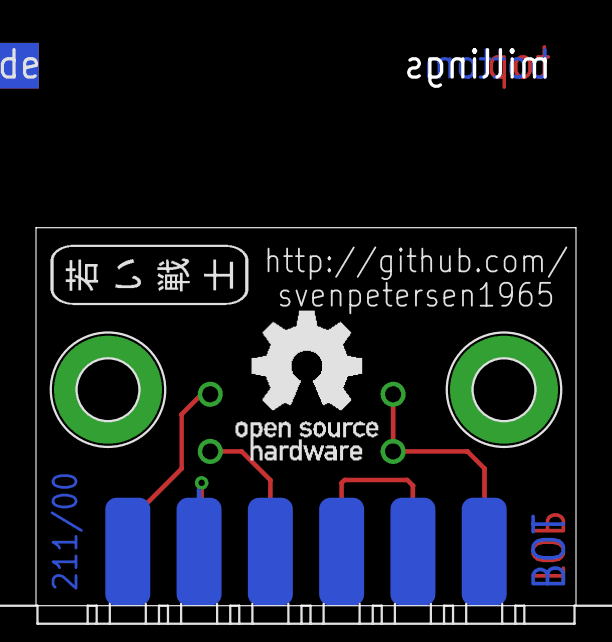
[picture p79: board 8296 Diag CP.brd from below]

Board: 2 copper layers, 30.0 x 21.0 mm, 10 parts (2 on the bottom side), 5 nets.

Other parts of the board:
U$2: DIAG_SMALL
U$3: 2LAYER
U$4: SVEN_TAG
U$5: PCB-TITLE/

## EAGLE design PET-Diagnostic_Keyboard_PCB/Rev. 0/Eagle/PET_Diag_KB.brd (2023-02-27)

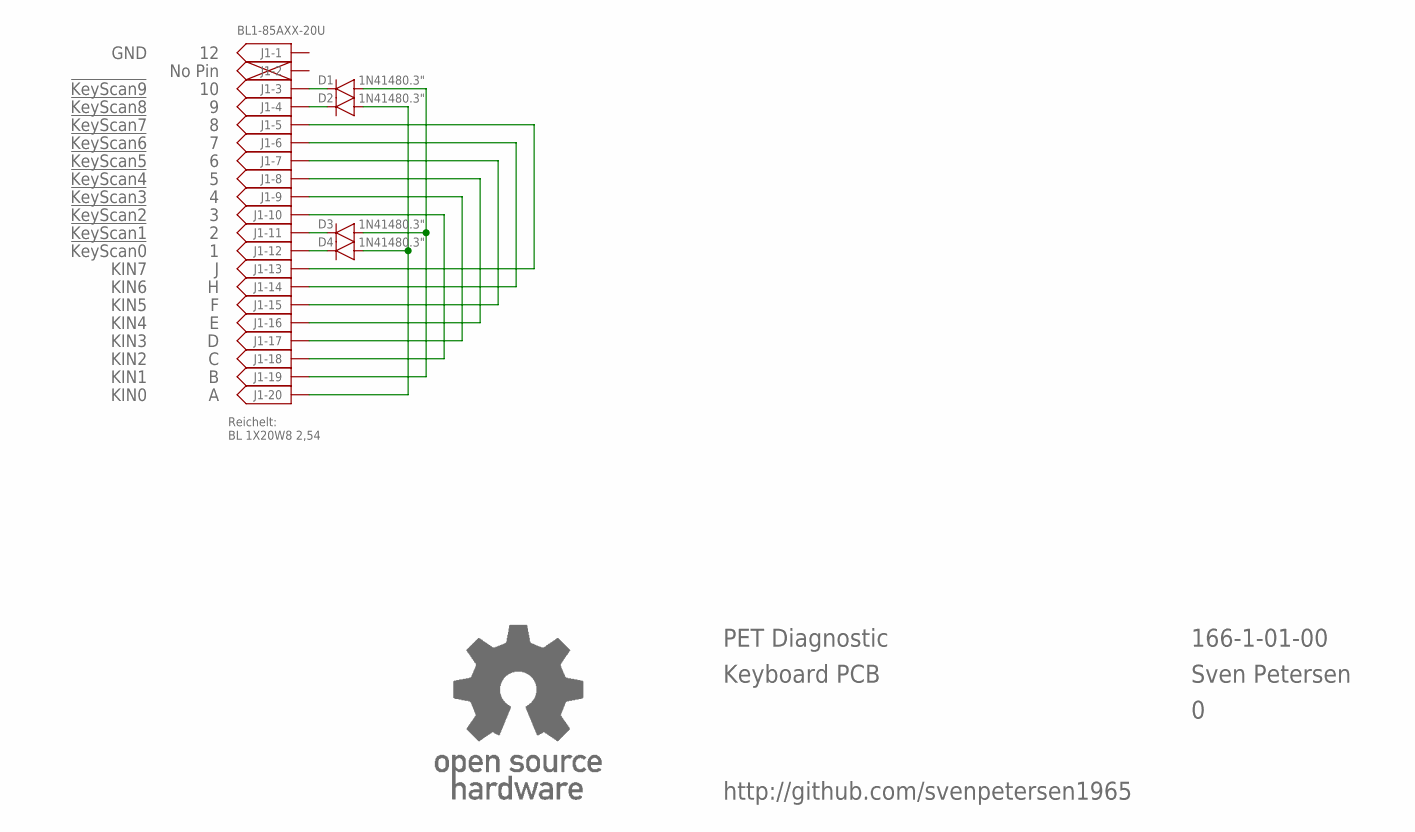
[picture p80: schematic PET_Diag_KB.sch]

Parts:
D1, D2, D3, D4: 1N41480.3"; DO-35/3
J1: BL1-85AXX-20U
U$9: OPEN_SOURCE_HW; OPENHW

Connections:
unnamed: D1.K, J1.3
unnamed: D2.A, D4.A, J1.20
unnamed: D1.A, D3.A, J1.19
unnamed: J1.10, J1.18
unnamed: J1.9, J1.17
unnamed: J1.8, J1.16
unnamed: J1.7, J1.15
unnamed: J1.6, J1.14
unnamed: J1.5, J1.13
unnamed: D2.K, J1.4
unnamed: D3.K, J1.11
unnamed: D4.K, J1.12

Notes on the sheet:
No Pin
PET Diagnostic
Keyboard PCB
166-1-01-00
Sven Petersen
Reichelt: BL 1X20W8 2,54
http://github.com/svenpetersen1965
!KeyScan0
!KeyScan1
!KeyScan2
!KeyScan3
!KeyScan4
!KeyScan5
!KeyScan6
!KeyScan7
!KeyScan8
!KeyScan9
KIN0
KIN1
KIN2
KIN3
KIN4
KIN5
KIN6
KIN7
GND



Board: 2 copper layers, 14.0 x 53.0 mm, 11 parts (2 on the bottom side), 12 nets.

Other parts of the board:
U$2: DIAG_SMALL
U$3: PET_SMALL
U$6: 2LAYER
U$7: PCB-TITLE/
U$8: SVEN_TAG

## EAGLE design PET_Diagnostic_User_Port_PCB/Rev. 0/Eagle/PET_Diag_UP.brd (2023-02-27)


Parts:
DRL1, DRL2: BOHR3,5
J1: PET-USERPORT; USERPORT
U$13: OPEN_SOURCE_HW; OPENHW

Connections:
CA1: J1.2 (TVVIDEO), J1.B (CA1)
GND: J1.1 (GND), J1.12 (GND), J1.A (GND), J1.N (GND)
unnamed: J1.6 (TPREAD2), J1.7 (TPWRITE), J1.8 (TPREAD1)
PA0: J1.3 (IEEESRQ), J1.C (PA0)
PA1: J1.4 (IEEEEOI), J1.D (PA1)
PA2: J1.5 (!DIAGSENS), J1.11 (!GRAPHIC), J1.E (PA2)
PA6: J1.9 (TVVERT), J1.K (PA6)
PA7: J1.10 (TVHOR), J1.L (PA7)

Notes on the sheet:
PET Diagnostic User Port PCB
165-1-01-00
Sven Petersen
http://github.com/svenpetersen1965


Board: 2 copper layers, 54.0 x 20.0 mm, 9 parts (0 on the bottom side), 8 nets.

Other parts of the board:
U$6: DIAG_SMALL
U$7: PET_SMALL
U$8: 2LAYER
U$9: PCB-TITLE/
U$10: SVEN_TAG

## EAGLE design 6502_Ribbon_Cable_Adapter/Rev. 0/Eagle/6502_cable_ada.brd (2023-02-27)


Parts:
IC1: 6502SOCKET; GS40P
IC2: 6502PINS; DIL40_PINS_SS
J1: PINHD-2X20WV; 2X20WV
LD1: 3mm/gn; 3MM
R1: 330R; R-10
U$11: OPEN_SOURCE_HW; OPENHW

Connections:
!IRQ: IC1.4 (!IRQ), IC2.4 (!IRQ), J1.7
!NMI: IC1.6 (!NMI), IC2.6 (!NMI), J1.11
!NOROM: IC1.5 (N.C.), IC2.5 (N.C.), J1.9
!RES: IC1.40 (!RES), IC2.40 (!RES), J1.2
+5V: IC1.8 (VCC), IC2.8 (VCC), J1.15, LD1.A
AB0: IC1.9 (AB0), IC2.9 (AB0), J1.17
AB1: IC1.10 (AB1), IC2.10 (AB1), J1.19
AB2: IC1.11 (AB2), IC2.11 (AB2), J1.21
AB3: IC1.12 (AB3), IC2.12 (AB3), J1.23
AB4: IC1.13 (AB4), IC2.13 (AB4), J1.25
AB5: IC1.14 (AB5), IC2.14 (AB5), J1.27
AB6: IC1.15 (AB6), IC2.15 (AB6), J1.29
AB7: IC1.16 (AB7), IC2.16 (AB7), J1.31
AB8: IC1.17 (AB8), IC2.17 (AB8), J1.33
AB9: IC1.18 (AB9), IC2.18 (AB9), J1.35
AB10: IC1.19 (AB10), IC2.19 (AB10), J1.37
AB11: IC1.20 (AB11), IC2.20 (AB11), J1.39
AB12: IC1.22 (AB12), IC2.22 (AB12), J1.38
AB13: IC1.23 (AB13), IC2.23 (AB13), J1.36
AB14: IC1.24 (AB14), IC2.24 (AB14), J1.34
AB15: IC1.25 (AB15), IC2.25 (AB15), J1.32
DB0: IC1.33 (DB0), IC2.33 (DB0), J1.16
DB1: IC1.32 (DB1), IC2.32 (DB1), J1.18
DB2: IC1.31 (DB2), IC2.31 (DB2), J1.20
DB3: IC1.30 (DB3), IC2.30 (DB3), J1.22
DB4: IC1.29 (DB4), IC2.29 (DB4), J1.24
DB5: IC1.28 (DB5), IC2.28 (DB5), J1.26
DB6: IC1.27 (DB6), IC2.27 (DB6), J1.28
DB7: IC1.26 (DB7), IC2.26 (DB7), J1.30
GND: IC1.21 (VSS), IC2.21 (VSS), J1.40, R1.1
GND1: IC1.1 (VSS), IC2.1 (VSS), J1.1
unnamed: LD1.C (K), R1.2
NC2: IC1.35 (N.C.), IC2.35 (N.C.), J1.12
NC3: IC1.36 (N.C.), IC2.36 (N.C.), J1.10
PHI0: IC1.37 (PHI0), IC2.37 (PHI0), J1.8
PHI1: IC1.3 (PHI1), IC2.3 (PHI1), J1.5
PHI2: IC1.39 (PHI2), IC2.39 (PHI2), J1.4
R/!W: IC1.34 (R/!W), IC2.34 (R/!W), J1.14
RDY: IC1.2 (RDY), IC2.2 (RDY), J1.3
S.O.: IC1.38 (S.O.), IC2.38 (S.O.), J1.6
SYNC: IC1.7 (SYNC), IC2.7 (SYNC), J1.13

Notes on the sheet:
6502 Diagnostic
Ribbon Cable Adapter
Sven Petersen
162-1-01-00
http://github.com/svenpetersen1965


Board: 2 copper layers, 32.0 x 58.0 mm, 9 parts (0 on the bottom side), 41 nets.

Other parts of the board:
U$12: PCB-TITLE/
U$13: 2LAYER
U$14: SVEN_TAG

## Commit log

2023-06-11 CBM8296 Cassette Dongle
    [8296 Diag CP.brd, 8296 Diag CP.dxf, 8296 Diag CP.sch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]
2023-06-11 CBM8296 J4 Breakout Board
    [8296_Diag_J4.brd, 8296_Diag_J4.dxf, 8296_Diag_J4.sch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]
2023-06-11 CBM8296 Keyboard Dongle
    [8296KB_bottom_shell.stl, 8296KB_top_shell.stl, 8296_KB_BOM_v0_0.xlsx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]
2023-06-11 CBM8296 User Port Dongle
    [8286UP_top_shell.stl, 8296 Diagnostic UP.brd, 8296 Diagnostic UP.dxf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]
2023-06-15 Testing of the 8296 harness (14.06.2023)
    My cooperation partner testing the 8296 harness…
2023-06-21 /NOROM Modification of Clip PCB Rev. 2
2026-01-05 Case for Clip PCB Rev. 3
    [PETDiag_Clip_v3 v11.f3d, clip_bottom_shell.stl, clip_top_shell.stl]
2026-01-05 Clip Rev. 3
    Easier to build, CBM8296 compatible
    [PETDiag_Clip_BOM_v3_0.xlsx, PET_Diag_Clip.brd, PET_Diag_Clip.dxf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]
